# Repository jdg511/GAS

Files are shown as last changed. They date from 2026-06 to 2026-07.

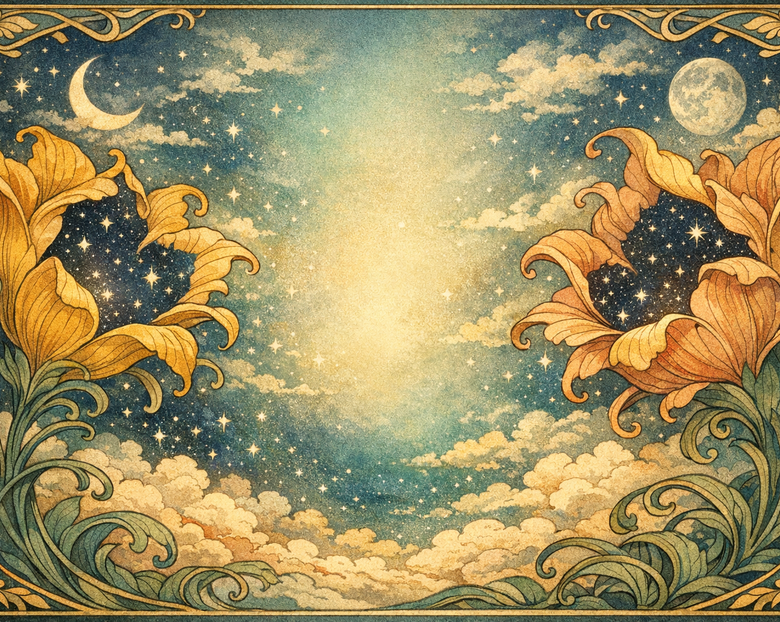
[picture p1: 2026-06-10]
Assets/Images/background_session_08.png

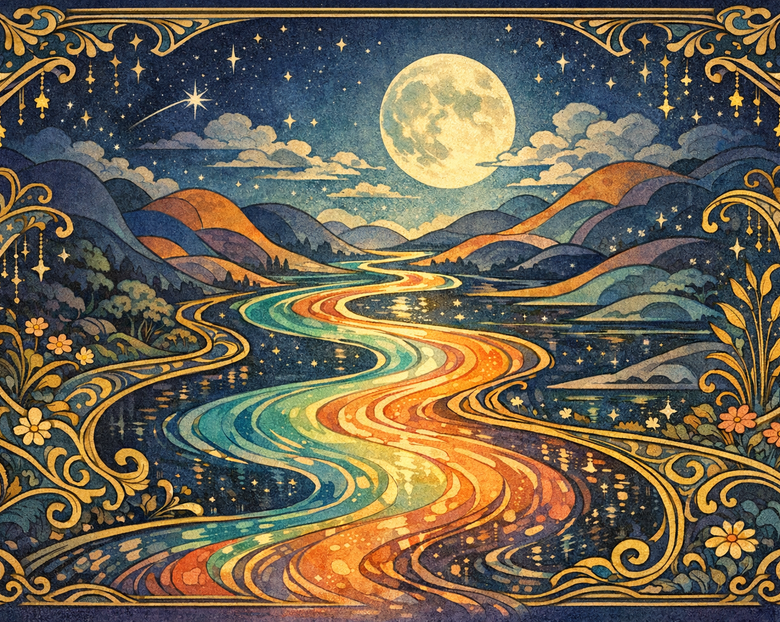
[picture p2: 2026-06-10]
Assets/Images/background_session_03.png

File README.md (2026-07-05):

# The Great American Spring

JUCE 7 audio effect by Illicit Apothecary.

Release v2.5 defines the GAS fork from the former Stereo Crossfeed Convolver project. It packages only the four final spring tank IR files:

- `GBS-L.wav`
- `GBS-R.wav`
- `GAS-L.wav`
- `GAS-R.wav`

The plugin provides Main Tanks, optional Ext Reverb Tanks in series or parallel, a constant-sum stereo crossfade, FilterClipper, feedback phase control, mono source handling, and wet/dry output mixing.

## Hardware Mapping Notes

For the real device, the simulation's `predelay + convolution IR` stage should be treated as the software stand-in for a physical spring reverb tank.

- Primary tank simulation: both channels represent `4AB1C1B` tanks.
- Secondary tank simulation: left channel represents a `9EB2C1B` tank and right channel represents a `9EB3C1B` tank.

This means the current JUCE simulation is not just a generic convolution reverb. Its timing and IR choices are standing in for the mechanical behavior of the spring tanks we intend to use in hardware.
Only the predelay and convolution portions are simulation-only. They exist to emulate the behavior of the real spring tanks; the rest of the signal path should be treated as candidate hardware behavior unless we explicitly decide otherwise later.

## Hardware Platform Constraints

The real-world unit should be designed as primarily analog hardware:

- Use passive components, solid-state transistors, and analog / mixed-signal ICs as the main building blocks.
- Do not base the PCB design on an MCU, Arduino, Raspberry Pi, or other general-purpose embedded computer.
- The production hardware should replace the simulation-only predelay and convolution stages with real spring tanks and supporting analog electronics, not runtime convolution or software processing on the PCB.

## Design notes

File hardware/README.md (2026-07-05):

# GAS Hardware Build

This folder is the starting point for turning the JUCE spring-reverb simulation into a real analog product.

## Core Constraints

- The real unit is primarily analog.
- Use passive parts, transistors, and analog or mixed-signal ICs.
- Do not use an MCU, Arduino, Raspberry Pi, or other general-purpose embedded computer on the production PCB.
- The external audio interfaces should be balanced line level, nominally `+4 dBu`, with 600-ohm capable line I/O behavior.
- The external audio connectors should be combo `XLR / TRS` jacks.
- The enclosure format is now a **user-supplied cylindrical tube**, `10 in` nominal diameter (standard pipe/cap size; `9 in` fits but is rarely stocked) and about `48 in` long.
- All external audio connections and DC power entry should land on **one circular service endcap**, in the spirit of the original Great British Spring.
- In the audio path, avoid ceramic, tantalum, and electrolytic capacitors wherever practical; prefer film-based or other non-ceramic/non-electrolytic solutions and use direct coupling where it makes sense. Power-supply and rail-decoupling positions may use ceramics or electrolytics when practical.
- Only the simulation's predelay and convolution blocks are software-only stand-ins for the real spring tanks.
- The real hardware should use the target tanks directly:
  - Primary tanks: `4AB1C1B` left and `4AB1C1B` right
  - Secondary tanks: `9EB2C1B` left and `9EB3C1B` right
- Plan around `+15VA / -15VA`, but prefer parts that can tolerate at least `+18V / -18V` wherever practical.
- Mains conversion lives in an **external `+24 VDC` wall-adapter strategy** (`750 mA / 18 W`, Triad Magnetics `WSU240-0750` regulated SMPS from DigiKey, selected `2026-07-04`). The chassis takes DC at a barrel jack and generates `+15V / -15V / +5V` on-board from that single DC input. No mains-side circuitry inside the enclosure. The Triad unit is a regulated SMPS; the P-0 receiving check in [rev-a-external-dc-power.md](rev-a-external-dc-power.md) still applies at first power-up.

## Board Roadmap

We are partitioning the product into analog boards so each section can be designed, tested, and revised independently.

1. Input / Output board
   - Balanced line receiver, dry split, final wet/dry summing, balanced line driver
2. Ext Reverb Tanks Off / Series / Parallel board
   - Secondary tank routing and amount control
3. Filter and Clipping board
   - Drive, HPF, selectable clipping, LPF
4. Tank Driver / Recovery board
   - Real spring tank send and return electronics for primary and secondary tanks
5. Crossfade / Feedback / Mixer board
   - Stereo tank crossfade, feedback loop, phase invert, inter-board summing
6. Power / Control / Interconnect board
   - Analog supply rails, panel controls, board-to-board headers, grounding strategy

## Signal-Path Mapping

The current software path is:

`input -> dry tap + wet path -> tank model -> stereo crossfade -> filter/clipper -> feedback -> wet/dry mix -> output`

The real hardware path should become:

`balanced line receiver -> dry split + wet send -> real tank drive/recovery path -> stereo crossfade -> filter/clipper -> feedback loop -> wet/dry output mixer -> balanced line driver`

The only direct substitution is:

- `predelay + convolution` in software
- replaced by
- real tank drive + real spring tank + recovery stages in hardware

## Design Intent

- Keep the board architecture modular so a third-party PCB house can fabricate repeatable revisions.
- Favor through-hole panel hardware and serviceable connectors where practical.
- Keep the control surface directly analog whenever possible: pots, toggles, rotary switches, relay logic, and analog switch ICs are all acceptable paths.
- Avoid any hardware decision that depends on firmware existing later.

## Build Handoff Entry Points

If you are picking this package up to actually build a unit, start here:

- [rev-a-external-dc-power.md](rev-a-external-dc-power.md) — external wall-adapter power topology and on-board ±15V / +5V generation
- [rev-a-pipe-enclosure-concept.md](rev-a-pipe-enclosure-concept.md) — cylindrical shell, endcap, rail, and tank-mount concept
- [rev-a-endcap-panel-layout.md](rev-a-endcap-panel-layout.md) — service-endcap zoning for combo jacks, DC jack, and controls
- [rev-a-endcap-hole-table.md](rev-a-endcap-hole-table.md) — first drilling/cutout draft for the circular service endcap
- [rev-a-endcap-hole-table.csv](rev-a-endcap-hole-table.csv) — machine-readable companion to the endcap hole table
- [rev-a-board-outline-assumptions.md](rev-a-board-outline-assumptions.md) — target board envelopes and axial placement inside the tube
- [rev-a-board-outline-assumptions.csv](rev-a-board-outline-assumptions.csv) — machine-readable board envelope and station map
- [rev-a-harness-cut-lengths.md](rev-a-harness-cut-lengths.md) — prototype harness cut lengths for boards, tanks, and panel wiring
- [rev-a-harness-cut-lengths.csv](rev-a-harness-cut-lengths.csv) — machine-readable harness-length companion
- [rev-a-board-package-freeze.md](rev-a-board-package-freeze.md) — compact board-by-board freeze for schematic capture and quoting
- [rev-a-electrical-capture-worksheet.md](rev-a-electrical-capture-worksheet.md) — next-pass electrical wiring brief keyed to the actual KiCad refs
- [rev-a-io-schematic-ready-definition.md](rev-a-io-schematic-ready-definition.md) — exact first-pass I/O unit allocation, passive map, and connector/net ownership
- [rev-a-ext-routing-schematic-ready-definition.md](rev-a-ext-routing-schematic-ready-definition.md) — exact first-pass ext-routing relay ownership, control decode, and passive map
- [rev-a-tank-driver-recovery-schematic-ready-definition.md](rev-a-tank-driver-recovery-schematic-ready-definition.md) — exact first-pass tank send/recovery stage ownership, shield strategy, and passive map
- [rev-a-crossfade-feedback-wet-schematic-ready-definition.md](rev-a-crossfade-feedback-wet-schematic-ready-definition.md) — exact first-pass crossfade, wet-return, and feedback-path definition
- [rev-a-filter-clipper-schematic-ready-definition.md](rev-a-filter-clipper-schematic-ready-definition.md) — exact first-pass filter/drive/clip stage ownership and mode truth
- [rev-a-control-backplane-schematic-ready-definition.md](rev-a-control-backplane-schematic-ready-definition.md) — exact first-pass control landing, mode encoding, and backplane reserve policy
- [rev-a-board-connector-schedule.csv](rev-a-board-connector-schedule.csv) — machine-readable connector ownership and harness schedule
- [rev-a-quote-request-packet.md](rev-a-quote-request-packet.md) — exactly which files to send each vendor and template request emails
- [rev-a-total-cost-rollup.md](rev-a-total-cost-rollup.md) — single per-unit cost estimate across electronics, fab, assembly, tanks, enclosure, and labor
- [rev-a-bench-test-procedures.md](rev-a-bench-test-procedures.md) — per-board test procedures with specific signals, equipment, and pass/fail thresholds
- [rev-a-manufacturing.md](rev-a-manufacturing.md) — vendor recommendations and file conventions
- [bom/rev-a-procurement-snapshot.md](bom/rev-a-procurement-snapshot.md) — current exact-part sourcing snapshot and scope split
- [rev-a-bringup-sequence.md](rev-a-bringup-sequence.md) — board-by-board power-up order
- [rev-a-open-issues.md](rev-a-open-issues.md) — what is still genuinely unresolved

## Next Deliverables

- Shared signal naming and connector conventions
- One spec per board
- Schematic packets with stage ownership and pin-level harness maps
- Control-law and circuit-value tables that track the current plugin behavior
- Remaining audio-sheet pin-level

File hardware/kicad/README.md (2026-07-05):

# KiCad Workspace

KiCad 10 is installed locally on this machine.

This folder is the intended home for the hardware project once schematic capture starts.

## Planned Contents

- `GAS-Hardware.kicad_pro`
- `GAS-Hardware.kicad_sch`
- one schematic file scaffold per board
- board layouts for:
  - input-output
  - tank-driver-recovery
  - ext-tank-routing
  - crossfade-feedback-wet-summing
  - filter-clipper

## Current Status

The KiCad project now has a **real top-level hierarchical shell**, first-pass real symbol capture across every rev-A child sheet, and a first-pass electrically assigned power/backplane page.

What currently exists:

- file naming
- top-level sheet ownership and page ordering
- title blocks
- top-level system notes
- child-sheet interface labels for global rails, I/O boundary nets, inter-board audio nets, and frozen control nets
- first-pass symbol population on every rev-A board sheet
- first-pass DC-entry, rail-generation, and harness-fanout net assignment on `power-backplane.kicad_sch`
- PCB placement scaffold files for all six rev-A boards, generated from the documented board envelope assumptions
- DRC-clean placement scaffolds with four M3 mounting holes plus all currently assigned schematic footprints per board
- capture sequencing
- validated CLI export workflow
- a manifest-driven audit script for measuring schematic population progress

What does **not** yet exist:

- real inter-sheet and intra-sheet pin-level wiring on the five audio/control sheets
- clean ERC after the new symbol-only capture phase
- finished footprint assignment inside every schematic page
- routed copper, zones, final component placement, or Gerber/drill fabrication exports for the PCB files

Capture should now key off:

- [rev-a-schematic-packets.md](C:/Users/Jason/GAS-build/repo/hardware/rev-a-schematic-packets.md:1)
- [rev-a-electrical-capture-worksheet.md](C:/Users/Jason/GAS-build/repo/hardware/rev-a-electrical-capture-worksheet.md:1)
- [rev-a-io-schematic-ready-definition.md](C:/Users/Jason/GAS-build/repo/hardware/rev-a-io-schematic-ready-definition.md:1)
- [rev-a-ext-routing-schematic-ready-definition.md](C:/Users/Jason/GAS-build/repo/hardware/rev-a-ext-routing-schematic-ready-definition.md:1)
- [rev-a-tank-driver-recovery-schematic-ready-definition.md](C:/Users/Jason/GAS-build/repo/hardware/rev-a-tank-driver-recovery-schematic-ready-definition.md:1)
- [rev-a-crossfade-feedback-wet-schematic-ready-definition.md](C:/Users/Jason/GAS-build/repo/hardware/rev-a-crossfade-feedback-wet-schematic-ready-definition.md:1)
- [rev-a-filter-clipper-schematic-ready-definition.md](C:/Users/Jason/GAS-build/repo/hardware/rev-a-filter-clipper-schematic-ready-definition.md:1)
- [rev-a-control-backplane-schematic-ready-definition.md](C:/Users/Jason/GAS-build/repo/hardware/rev-a-control-backplane-schematic-ready-definition.md:1)
- [rev-a-interconnect-pin-map.md](C:/Users/Jason/GAS-build/repo/hardware/rev-a-interconnect-pin-map.md:1)
- [rev-a-bringup-sequence.md](C:/Users/Jason/GAS-build/repo/hardware/rev-a-bringup-sequence.md:1)
- [rev-a-sheet-population-plan.md](C:/Users/Jason/GAS-build/repo/hardware/kicad/rev-a-sheet-population-plan.md:1)
- [rev-a-symbol-manifest.csv](C:/Users/Jason/GAS-build/repo/hardware/kicad/rev-a-symbol-manifest.csv:1)
- [rev-a-net-label-manifest.csv](C:/Users/Jason/GAS-build/repo/hardware/kicad/rev-a-net-label-manifest.csv:1)

## Verification

During this session, the hierarchical top-level shell and all child sheets were accepted by `kicad-cli`, and the release-export script still produced schematic PDFs successfully after the interface-label pass.

Important current nuance:

- symbol population is intentionally ahead of real wire placement
- `kicad-cli sch export pdf` still succeeds
- top-level ERC is no longer clean at this intermediate stage because the hierarchical labels are not yet attached to real wires or symbols
- the current ERC result is therefore a **known intermediate failure**, not a claim that the capture is electrically complete

Current exported folder:

- the historical placeholder export artifact still exists as a file named `hardware/kicad/exports`

Repeatable release/export helper:

- [export-rev-a-release.ps1](C:/Users/Jason/GAS-build/repo/hardware/kicad/export-rev-a-release.ps1:1)
- [rev-a-release-manifest.csv](C:/Users/Jason/GAS-build/repo/hardware/kicad/rev-a-release-manifest.csv:1)

Repeatable capture-progress audit:

- [audit-rev-a-capture.py](C:/Users/Jason/GAS-build/repo/hardware/kicad/audit-rev-a-capture.py:1)
- [rev-a-capture-audit.md](C:/Users/Jason/GAS-build/repo/hardware/kicad/rev-a-capture-audit.md:1)

Run:

```powershell
python hardware/kicad/audit-rev-a-capture.py
```

Current baseline from the latest `2026-06-29` audit:

- top-level hierarchy: `6 / 6` child sheets present
- populated schematic refs: `88 / 88`
- explicit manifest net labels: `82 / 82`

Current release-export / ERC baseline from the same session:

- capture audit: `88 / 88` planned refs present and `82 / 82` manifest labels present
- top-level ERC: `650` known intermediate violations after the I/O-board center-short cleanup pass on `2026-06-29`
- the I/O child sheet dropped from `404` to `376` local violations in the same pass, and its multiple-net-name collisions dropped from `8` to `2`
- the remaining I/O multiple-net-name warnings are the intentional `WD_L_LO <-> WET_SUM_L` and `WD_R_LO <-> WET_SUM_R` wet-return aliases
- the remaining ERC debt is still dominated by top-level unconnected sheet pins, placeholder wire endpoints, off-grid legacy symbol endpoints, and still-unwired child-sheet labels on the non-power sheets
- the power/backplane page itself still stands as the most electrically assigned sheet, but it is not yet the final ripple-decoupling or chassis-bond implementation

Current PCB scaffold baseline:

- `crossfade-feedback-wet.kicad_pcb`: `100 mm x 70 mm`, 8 electrical footprints, 4x M3 mounting holes, DRC clean
- `ext-tank-routing.kicad_pcb`: `120 mm x 80 mm`, 12 electrical footprints, 4x M3 mounting holes, DRC clean
- `filter-clipper.kicad_pcb`: `140 mm x 90 mm`, 19 electrical footprints, 4x M3 mounting holes, DRC clean
- `io-board.kicad_pcb`: `160 mm x 75 mm`, 50 electrical footprints, 4x M3 mounting holes, DRC clean
- `power-backplane.kicad_pcb`: `150 mm x 95 mm`, 14 electrical footprints, 4x M3 mounting holes, DRC clean
- `tank-driver-recovery.kicad_pcb`: `170 mm x 110 mm`, 11 electrical footprints, 4x M3 mounting holes, DRC clean
- these are **placement scaffolds only** and are not routed fabrication outputs

Repeatable PCB footprint placement helper:

- [place-rev-a-board-footprints.py](C:/Users/Jason/GAS-build/repo/hardware/kicad/place-rev-a-board-footprints.py:1)

Current scripted output root:

- `hardware/kicad/release-exports/rev-a-release`

## Order Readiness Gate

Before ordering boards, run:

```powershell
.\hardware\kicad\test-rev-a-order-readiness.ps1
```

The gate writes:

- [rev-a-order-readiness.md](C:/Users/Jason/GAS-build/repo/hardware/kicad/rev-a-order-readiness.md:1)
- [GAS-Hardware-erc-current.json](C:/Users/Jason/GAS-build/repo/hardware/kicad/GAS-Hardware-erc-current.json:1)

It intentionally fails while any of these are true:

- no `*.kicad_pcb` board layout files exist
- top-level ERC has violations
- non-virtual schematic symbols have empty footprint fields
- KiCad/SPICE simulation model properties are absent

The current project is therefore **not order-ready**. It remains in schematic-capture cleanup before PCB layout, DRC, Gerber/drill export, and simulation setup.

## Planned Export Set

- fabrication Gerbers
- drill files
- schematic PDFs
- `BOM.csv`
- centroid / position files
- assembly drawings
- bring-up and calibration notes

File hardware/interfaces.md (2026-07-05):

# Shared Interfaces

These are the working inter-board signal names for the analog build. The goal is to keep board boundaries stable before schematic capture.

## Audio Nets

- `IN_L`, `IN_R`
  - Local single-ended audio after the balanced input receiver
- `DRY_L`, `DRY_R`
  - Dry split taken from the input board before spring-tank processing
- `WET_SEND_L`, `WET_SEND_R`
  - Main wet-path feeds leaving the input board toward the tank system
- `PRI_RET_L`, `PRI_RET_R`
  - Recovered audio returning from the primary `4AB1C1B` tanks
- `SEC_RET_L`, `SEC_RET_R`
  - Recovered audio returning from the secondary `9EB2C1B` / `9EB3C1B` tanks
- `TANK_MIX_L`, `TANK_MIX_R`
  - Output of the tank-routing board before stereo crossfade
- `XFADE_OUT_L`, `XFADE_OUT_R`
  - Output of the stereo crossfade stage
- `FILTCLIP_OUT_L`, `FILTCLIP_OUT_R`
  - Output of the filter and clipping board
- `FB_SEND_L`, `FB_SEND_R`
  - Signals entering the feedback loop
- `FB_RET_L`, `FB_RET_R`
  - Feedback return signals summed into the wet send on the ext-routing board, upstream of the primary send and the parallel-mode pickoff, so regenerated signal makes another pass through the spring tanks
  - Must never sum into the `TANK_MIX` (post-tank) summers
- `WET_SUM_L`, `WET_SUM_R`
  - Final wet signal presented to the output mix stage
- `OUT_L`, `OUT_R`
  - Local single-ended audio before the balanced output driver

## Control Nets

- `CTL_EXT_MODE_A`, `CTL_EXT_MODE_B`
  - Two-bit ext-routing control pair
  - first-pass decode is `00 = Off`, `10 = Series`, `11 = Parallel`, `01 = reserved`
- `CTL_CLIP_MODE_A`, `CTL_CLIP_MODE_B`
  - Selects Clean / Silicon / LED / Germanium clipping topology
- `CTL_FB_INV`
  - Feedback polarity invert

Practical note:

- rev A now prefers raw passive control nets at the board boundaries rather than abstract one-net control names for stereo pots
- the actual raw control naming lives in [rev-a-control-harnesses.md](C:/Users/Jason/GAS-build/repo/hardware/rev-a-control-harnesses.md:1) and [rev-a-control-backplane-definition.md](C:/Users/Jason/GAS-build/repo/hardware/rev-a-control-backplane-definition.md:1)

## Power Nets

- `+15VA`, `-15VA`
  - Preferred starting assumption for the main analog rails
- `+5VAUX`
  - Optional auxiliary rail for relay coils, LEDs, or analog-switch housekeeping
- `AGND`
  - Audio ground / star ground reference
- `CHASSIS`
  - Chassis / enclosure ground, bonded at controlled points only

## Current Assumptions

- Default design target is stereo throughout.
- External I/O uses combo `XLR / TRS` jacks.
- Main analog stages should preserve enough headroom to survive tank recovery peaks and clipping-mode level changes.
- Board-to-board links should use locking headers or JST/Molex style connectors rather than hardwired point-to-point only.
- If tank interface impedances force shielded cabling, the tank driver/recovery board owns that connectorization.

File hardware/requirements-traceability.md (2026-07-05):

# GAS Hardware Requirements Traceability

This file maps the user-provided hardware constraints to the current hardware package so the design can be reviewed for drift.

## Scope

The goal is to design the analog hardware package for the GAS device as far as possible in this session, including:

- board architecture
- schematic-ready board definitions
- sourced BOM with current pricing/vendor links
- manufacturing handoff recommendations

## Constraint Matrix

| Requirement | Current Decision | Primary Evidence |
| --- | --- | --- |
| Real device is analog, no MCU / Arduino / Raspberry Pi | Locked as analog-only architecture | [README.md](C:/Users/Jason/GAS-build/repo/hardware/README.md:7), [rev-a-system-architecture.md](C:/Users/Jason/GAS-build/repo/hardware/rev-a-system-architecture.md:9) |
| Predelay + convolution are simulation-only stand-ins for real tanks | Locked as the only software-only substitution | [README.md](C:/Users/Jason/GAS-build/repo/README.md:16), [hardware/README.md](C:/Users/Jason/GAS-build/repo/hardware/README.md:37) |
| Primary tanks are `4AB1C1B` / `4AB1C1B` | Locked in architecture and board briefs | [README.md](C:/Users/Jason/GAS-build/repo/README.md:18), [rev-a-system-architecture.md](C:/Users/Jason/GAS-build/repo/hardware/rev-a-system-architecture.md:20) |
| Secondary tanks are `9EB2C1B` left and `9EB3C1B` right | Locked in architecture and board briefs | [README.md](C:/Users/Jason/GAS-build/repo/README.md:19), [rev-a-system-architecture.md](C:/Users/Jason/GAS-build/repo/hardware/rev-a-system-architecture.md:22) |
| External I/O is balanced line level | Locked at `+4 dBu`, 600-ohm capable | [hardware/README.md](C:/Users/Jason/GAS-build/repo/hardware/README.md:10), [input-output-board.md](C:/Users/Jason/GAS-build/repo/hardware/boards/input-output-board.md:5) |
| External jacks are combo `XLR / TRS` | Locked in architecture, panel spec, and mechanical BOM | [hardware/README.md](C:/Users/Jason/GAS-build/repo/hardware/README.md:11), [rev-a-controls-and-panel.md](C:/Users/Jason/GAS-build/repo/hardware/rev-a-controls-and-panel.md:5), [rev-a-panel-and-mechanical-reference-bom.csv](C:/Users/Jason/GAS-build/repo/hardware/bom/rev-a-panel-and-mechanical-reference-bom.csv:1) |
| Rev A needs a dedicated mono-input to stereo switch | Locked on the I/O board and panel spec | [input-output-board.md](C:/Users/Jason/GAS-build/repo/hardware/boards/input-output-board.md:10), [rev-a-controls-and-panel.md](C:/Users/Jason/GAS-build/repo/hardware/rev-a-controls-and-panel.md:24) |
| Input buffer should be JFET or BiFET | Current rev-A pick is `OPA1644AIDR` | [input-output-board.md](C:/Users/Jason/GAS-build/repo/hardware/boards/input-output-board.md:29), [rev-a-system-architecture.md](C:/Users/Jason/GAS-build/repo/hardware/rev-a-system-architecture.md:41), [rev-a-core-priced-bom.csv](C:/Users/Jason/GAS-build/repo/hardware/bom/rev-a-core-priced-bom.csv:1) |
| Prefer `+/-18V` tolerant parts where practical | Locked for the audio op-amp families | [hardware/README.md](C:/Users/Jason/GAS-build/repo/hardware/README.md:17), [rev-a-system-architecture.md](C:/Users/Jason/GAS-build/repo/hardware/rev-a-system-architecture.md:53) |
| Avoid ceramic / tantalum / electrolytic capacitors in the audio path if possible | Locked as an audio-path-only capacitor policy | [hardware/README.md](C:/Users/Jason/GAS-build/repo/hardware/README.md:12), [rev-a-capacitor-policy.md](C:/Users/Jason/GAS-build/repo/hardware/rev-a-capacitor-policy.md:1), [rev-a-common-passives-reference-bom.csv](C:/Users/Jason/GAS-build/repo/hardware/bom/rev-a-common-passives-reference-bom.csv:1) |
| Power may use practical ceramics/electrolytics | Explicitly allowed in power policy and passive BOM | [rev-a-layout-rules.md](C:/Users/Jason/GAS-build/repo/hardware/rev-a-layout-rules.md:17), [rev-a-common-passives-reference-bom.csv](C:/Users/Jason/GAS-build/repo/hardware/bom/rev-a-common-passives-reference-bom.csv:5) |
| Tanks are purchased separately from the PCB assembly | Locked in manufacturing handoff | [rev-a-manufacturing.md](C:/Users/Jason/GAS-build/repo/hardware/rev-a-manufacturing.md:127), [rev-a-manufacturing.md](C:/Users/Jason/GAS-build/repo/hardware/rev-a-manufacturing.md:155) |

## Deliverable Matrix

| Deliverable | Current Evidence |
| --- | --- |
| Board architecture | [hardware/README.md](C:/Users/Jason/GAS-build/repo/hardware/README.md:19), [rev-a-system-architecture.md](C:/Users/Jason/GAS-build/repo/hardware/rev-a-system-architecture.md:57) |
| Board-by-board definitions | [boards/input-output-board.md](C:/Users/Jason/GAS-build/repo/hardware/boards/input-output-board.md:1), [boards/ext-tank-routing-board.md](C:/Users/Jason/GAS-build/repo/hardware/boards/ext-tank-routing-board.md:1), [boards/crossfade-feedback-wet-board.md](C:/Users/Jason/GAS-build/repo/hardware/boards/crossfade-feedback-wet-board.md:1), [boards/filter-clipper-board.md](C:/Users/Jason/GAS-build/repo/hardware/boards/filter-clipper-board.md:1), [boards/system-remaining.md](C:/Users/Jason/GAS-build/repo/hardware/boards/system-remaining.md:1) |
| Signal ownership / interconnects | [interfaces.md](C:/Users/Jason/GAS-build/repo/hardware/interfaces.md:1), [rev-a-interconnects.md](C:/Users/Jason/GAS-build/repo/hardware/rev-a-interconnects.md:1) |
| Schematic starting points | [rev-a-circuit-starting-points.md](C:/Users/Jason/GAS-build/repo/hardware/rev-a-circuit-starting-points.md:1), [rev-a-board-implementation-matrix.md](C:/Users/Jason/GAS-build/repo/hardware/rev-a-board-implementation-matrix.md:1), [rev-a-schematic-packets.md](C:/Users/Jason/GAS-build/repo/hardware/rev-a-schematic-packets.md:1), [rev-a-capture-value-tables.md](C:/Users/Jason/GAS-build/repo/hardware/rev-a-capture-value-tables.md:1), [rev-a-mode-truth-tables.md](C:/Users/Jason/GAS-build/repo/hardware/rev-a-mode-truth-tables.md:1) |
| Hardware control ranges mapped from the plugin | [rev-a-control-ranges-and-laws.md](C:/Users/Jason/GAS-build/repo/hardware/rev-a-control-ranges-and-laws.md:1), [PluginProcessor.cpp](C:/Users/Jason/GAS-build/repo/Source/PluginProcessor.cpp:606) |
| Layout-facing board zoning | [rev-a-board-placement-and-zones.md](C:/Users/Jason/GAS-build/repo/hardware/rev-a-board-placement-and-zones.md:1), [rev-a-layout-rules.md](C:/Users/Jason/GAS-build/repo/hardware/rev-a-layout-rules.md:1) |
| Numeric electrical targets | [rev-a-numeric-targets.md](C:/Users/Jason/GAS-build/repo/hardware/rev-a-numeric-targets.md:1), [rev-a-power-budget.md](C:/Users/Jason/GAS-build/repo/hardware/rev-a-power-budget.md:1) |
| Current priced BOMs | [bom/README.md](C:/Users/Jason/GAS-build/repo/hardware/bom/README.md:1), [bom/rev-a-core-priced-bom.csv](C:/Users/Jason/GAS-build/repo/hardware/bom/rev-a-core-priced-bom.csv:1), [bom/rev-a-common-passives-reference-bom.csv](C:/Users/Jason/GAS-build/repo/hardware/bom/rev-a-common-passives-reference-bom.csv:1), [bom/rev-a-connectors-and-harness-reference-bom.csv](C:/Users/Jason/GAS-build/repo/hardware/bom/rev-a-connectors-and-harness-reference-bom.csv:1), [bom/rev-a-panel-and-mechanical-reference-bom.csv](C:/Users/Jason/GAS-build/repo/hardware/bom/rev-a-panel-and-mechanical-reference-bom.csv:1), [bom/rev-a-supply-watch.md](C:/Users/Jason/GAS-build/repo/hardware/bom/rev-a-supply-watch.md:1) |
| Manufacturing handoff | [rev-a-manufacturing.md](C:/Users/Jason/GAS-build/repo/hardware/rev-a-manufacturing.md:1), [rev-a-validation-checklist.md](C:/Users/Jason/GAS-build/repo/hardware/rev-a-validation-checklist.md:1), [kicad/README.md](C:/Users/Jason/GAS-build/repo/hardware/kicad/README.md:1) |
| Real KiCad project scaffolding | [kicad/GAS-Hardware.kicad_pro](C:/Users/Jason/GAS-build/repo/hardware/kicad/GAS-Hardware.kicad_pro:1), [kicad/GAS-Hardware.kicad_sch](C:/Users/Jason/GAS-build/repo/hardware/kicad/GAS-Hardware.kicad_sch:1), [rev-a-schematic-capture-plan.md](C:/Users/Jason/GAS-build/repo/hardware/rev-a-schematic-capture-plan.md:1) |
| Verified schematic placeholders | [kicad/README.md](C:/Users/Jason/GAS-build/repo/hardware/kicad/README.md:1), `kicad-cli sch export pdf` run outputs in `hardware/kicad/exports` |

## Remaining Reality Check

What is strong right now:

- the architecture and constraints are explicit
- the BOM package is split in a builder-friendly way
- the board boundaries and control ownership are defined

What is not yet complete enough to call "finished hardware design":

- the KiCad project is real and hierarchical, but several audio/control sheets are still intermediate first-pass captures rather than fully finished schematics
- there are not yet finished PCB layouts or clean fabrication-ready DRC/ERC artifacts
- some stage-level component values still need bench-tuning rather than pretending to be final

That means the package is materially advanced, but the thread goal is not yet proven complete.

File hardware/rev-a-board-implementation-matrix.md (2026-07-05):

# GAS Rev A Board Implementation Matrix

This file turns the architecture into concrete board ownership so schematic capture does not drift.

## Board Summary

| Board | Main Function | Active Parts | Key Controls | Main Risk |
| --- | --- | --- | --- | --- |
| Input / Output | Balanced receive, mono-to-stereo, wet/dry sum, balanced drive | `1x OPA1644AIDR`, `3x OPA1656IDR` | Wet/Dry, Mono->Stereo | balanced I/O behavior and headroom |
| Tank Driver / Recovery | Tank send drive and tank recovery | `4x OPA1656IDR`, `2x BD139-16`, `2x BD140-16` | none on panel directly | primary send level and recovery noise |
| Ext Tank Routing | Off/Series/Parallel routing and secondary mix | `4x G6K-2F-Y-DC5`, `1x OPA1679IDR` | Ext Mode, Ext Mix | relay routing around sensitive recovery nodes |
| Crossfade / Feedback / Wet Summing | Stereo crossfade, feedback, wet handoff | `1x OPA1679IDR` | Crossfade, Feedback, Feedback Invert | loop stability |
| Filter / Clipping | HPF, drive, clipping, LPF | `2x OPA1679IDR` | Drive, HPF F/Q, LPF F/Q, Clip Mode | stereo tracking and clip switching artifacts |
| Power / Backplane | DC entry, rail conversion, star ground, harnessing | `1x URA2415YMD-10WR3`, `1x R-78E5.0-0.5` | none | ripple control and grounding |

## Input / Output Board Allocation

### U1 `OPA1644AIDR`

- balanced input receiver left
- balanced input receiver right
- mono-to-stereo routing buffer left
- mono-to-stereo routing buffer right or spare unity-gain utility stage

### U2 `OPA1656IDR`

- wet/dry mix left
- wet/dry mix right

### U3 `OPA1656IDR`

- balanced output driver left hot
- balanced output driver left cold

### U4 `OPA1656IDR`

- balanced output driver right hot
- balanced output driver right cold

### I/O Board Connectors

- `J1` left combo `XLR / TRS`
- `J2` right combo `XLR / TRS`
- `J3` left combo `XLR / TRS` output
- `J4` right combo `XLR / TRS` output
- `P1` power
- `P2` wet send
- `P3` wet return
- `P4` dry distribution
- `P5` wet/dry control
- `P6` mono-to-stereo switch

## Tank Driver / Recovery Board Allocation

### U101 `OPA1656IDR`

- primary left send predriver
- primary right send predriver

### Q101 / Q102 / Q103 / Q104 `BD139-16` / `BD140-16`

- complementary output pair for primary left send
- complementary output pair for primary right send

### U102 `OPA1656IDR`

- secondary left tank send
- secondary right tank send

### U103 `OPA1656IDR`

- primary left recovery
- primary right recovery

### U104 `OPA1656IDR`

- secondary left recovery
- secondary right recovery

### Tank Board Connectors

- `P101` primary routing bundle
- `P102` secondary routing bundle
- `P103` power
- `J101-J108` tank send/return landings

## Ext Tank Routing Board Allocation

### K201-K204 `G6K-2F-Y-DC5`

- route primary and secondary path state for Off / Series / Parallel

### U201 `OPA1679IDR`

- left final routing / wet-output sum
- right final routing / wet-output sum
- left secondary-send buffer
- right secondary-send buffer

### Routing Board Connectors

- `P201` wet input from I/O board
- `P202` primary tank bundle
- `P203` secondary tank bundle
- `P204` routed output to crossfade board
- `P205` feedback reinjection input
- `P206` control or panel-backplane header
- `P207` power input including `+5VAUX`

## Crossfade / Feedback / Wet Summing Board Allocation

### U301 `OPA1679IDR`

- `U301A` left inverting crossfade summer
- `U301B` right inverting crossfade summer
- `U301C` left feedback driver / invert stage
- `U301D` right feedback driver / invert stage
- `U301` power unit for local `+15VA / -15VA` decoupling ownership

### Crossfade / Feedback / Wet Connectors

- `P301` routed tank input: `TANK_MIX_L`, `AGND`, `TANK_MIX_R`
- `P302` send to filter / clipper: `XFADE_OUT_L`, `AGND`, `XFADE_OUT_R`
- `P303` filter return: `FILTCLIP_OUT_L`, `AGND`, `FILTCLIP_OUT_R`
- `P304` direct wet return to I/O board: `WET_SUM_L`, `AGND`, `WET_SUM_R`
- `P305` feedback reinjection output: `FB_RET_L`, `AGND`, `FB_RET_R`
- `P306` power input: `+15VA`, `AGND`, `-15VA`
- `P307` grouped control landing for crossfade, feedback amount, and feedback phase invert

### Crossfade / Feedback / Wet Circuit Freeze Notes

- the direct wet return is sourced from the post-filter `FILTCLIP_OUT_L/R` path and is not phase-flipped
- `CTL_FB_INV` only changes the feedback-send source between direct and inverted paths
- the current `P307` header is good enough for rev-A capture, but still slightly compressed for a completely raw off-board passive feedback-pot implementation

## Filter / Clipping Board Allocation

### U401 `OPA1679IDR`

- left pre-HPF
- right pre-HPF
- left drive/clipping buffer
- right drive/clipping buffer

### U402 `OPA1679IDR`

- left post-LPF
- right post-LPF
- left output buffer
- right output buffer

### Filter / Clipping Connectors

- `P401` input from crossfade board
- `P402` output to crossfade/feedback board
- `P403` control group A
- `P404` power input
- `P405` control group B

## One Important Connector Caveat

Standard combo `XLR / TRS` receptacles are typically `XLR female + TRS`.

That is conventional for balanced inputs, but unconventional for XLR outputs.

Rev A therefore has two practical interpretations:

1. honor the combo-jack requirement literally and accept the unusual female-XLR output convention
2. use the combo format where physically possible, but treat the TRS side as the primary balanced output path

The project currently preserves the literal combo-jack requirement, but this should be sanity-checked before enclosure metalwork is frozen.

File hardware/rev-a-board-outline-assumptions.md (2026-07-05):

# GAS Rev A Board Outline Assumptions

This file gives the first concrete board-size and placement assumptions for the cylindrical rev-A build.

These are **prototype-planning numbers**, not final fab outlines. Their purpose is to:

- keep the six-board split physically plausible inside the tube
- support rail spacing and harness-length planning
- give KiCad layout work a target envelope before the mechanical package is fully frozen

## Mechanical Reference Frame

- enclosure shell: user-supplied tube
- preferred outer diameter: `10.0 in` nominal (`254 mm`; measured cap face will differ — see rev-a-pipe-enclosure-concept.md)
- acceptable fallback outer diameter: `9.0 in` (`228.6 mm`) if stock appears; `8.0 in` (`203.2 mm`) only with layout compromises
- design target length: `48 in` (`1219 mm`)

For the draft board envelopes below, assume:

- usable internal width between rails and curvature keepout: about `160 mm`
- usable straight-line board length near the service end: `80-170 mm` depending on board
- minimum side clearance from board corners to curved shell: `10 mm`
- minimum board-to-board axial service gap: `18 mm`

## Preferred Internal Rail Geometry

- two longitudinal rails or angle brackets
- nominal rail separation: `140 mm` center-to-center
- board mounting plane offset from shell wall: `18-25 mm`
- keep the deepest components on the inward-facing side where possible

## Draft Board Envelopes

### 1. Input / Output Board

- target outline: `160 mm x 75 mm`
- orientation: wide edge parallel to the service endcap
- location: immediately behind the combo-jack field

Reason:

- the board mainly needs room for balanced I/O stages, harness headers, and optional short panel harnesses
- combo jacks themselves should remain panel parts, not board-edge mechanical anchors, in the preferred rev-A interpretation

### 2. Power / Control Backplane

- target outline: `150 mm x 95 mm`
- orientation: broad side parallel to the service endcap
- location: behind or slightly below the I/O board, close to DC entry and chassis bond

Reason:

- this board wants room for the DC-DC module, rail filtering, power headers, and grouped control landings

### 3. Ext Tank Routing Board

- target outline: `120 mm x 80 mm`
- location: first mid-tube audio board after the service-end boards

Reason:

- relay routing is more important than density
- keep one long edge available for the harness field

### 4. Crossfade / Feedback / Wet Board

- target outline: `100 mm x 70 mm`
- location: adjacent to the routing board

Reason:

- this is electrically compact and should be one of the smaller boards

### 5. Filter / Clipper Board

- target outline: `140 mm x 90 mm`
- location: adjacent to the crossfade board

Reason:

- this board is likely to grow because of film-capacitor footprints and control-header density

### 6. Tank Driver / Recovery Board

- target outline: `170 mm x 110 mm`
- location: deeper into the tube, near the tank zone

Reason:

- this board carries the most analog risk
- it needs room for TO-126 devices, recovery spacing, RCA or equivalent tank landings, and thermal/mechanical breathing room

## Draft Axial Station Map

Measured from the inside face of the service endcap:

| Station | Start | End | Notes |
|---|---:|---:|---|
| I/O board zone | `25 mm` | `100 mm` | close to combo-jack harnesses |
| Power/control zone | `105 mm` | `200 mm` | close to DC entry and chassis bond |
| Ext-routing zone | `225 mm` | `305 mm` | first mid-path audio board |
| Crossfade zone | `325 mm` | `395 mm` | short audio links to routing and filter |
| Filter/clipper zone | `415 mm` | `505 mm` | keep controls reachable by one grouped harness |
| Tank driver/recovery zone | `575 mm` | `685 mm` | quiet zone near tank harness landings |
| Tank mounting zone | `720 mm` | `1120 mm` | user-supplied tanks and isolation hardware |

This intentionally leaves:

- one service gap between the filter/clipper and tank-driver board
- a quiet transition zone before the tank area

## Curvature And Height Keepouts

Do not assume a rectangular box interior.

For boards wider than `140 mm`:

- keep tall parts inside an inner rectangle about `140 mm x board length`
- reserve corner triangles as no-go zones for tall electrolytics, relays, or stacked connectors

Practical rule:

- if a component is taller than `14 mm`, keep it at least `12 mm` inboard from the board outline on the shell-facing side

## Preferred Mounting-Hole Pattern

Use a simple 4-hole pattern on each board where practical:

- hole size: `3.2 mm` for `M3` or `4-40`
- edge setback: `5-7 mm`
- slotted holes acceptable only on the tank-driver board if thermal or harness alignment needs them

## What This File Does And Does Not Freeze

This file freezes:

- a plausible physical envelope for each board
- a believable axial layout for harness planning
- a preferred rail-mounted construction style

This file does not freeze:

- exact final PCB outline
- final mounting-hole coordinates
- exact component keepouts from the eventual KiCad 3D models

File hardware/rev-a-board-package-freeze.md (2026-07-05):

# GAS Rev A Board Package Freeze

This file is the compact "what each board is" reference for the current hardware package.

Use it when:

- populating the KiCad child sheets
- building per-board quote bundles
- checking that the mechanical, harness, and BOM layers still agree

The goal is not to replace the board briefs. It is to freeze the minimum board facts that should not drift casually.

## Global Rev-A Freeze

- Analog-only product electronics. No MCU, Arduino, Raspberry Pi, DSP module, or general-purpose embedded computer.
- External I/O is balanced line level, nominal `+4 dBu`, with 600-ohm capable line-interface behavior.
- External panel connectors are combo `XLR / TRS` jacks.
- The real tank set is `4AB1C1B x2`, `9EB2C1B x1`, `9EB3C1B x1`.
- Predelay and convolution remain software-only study tools and do not appear on the PCB set.
- Main supply architecture is external `+24 VDC` wall adapter into on-board conversion for `+15VA`, `-15VA`, and `+5VAUX`.
- The main cylindrical enclosure tube is user-supplied.

## Board Freeze Table

| Board | Target Envelope | Placement Zone | Main Active Set | Power | Main Connectors | Controls | Install Scope |
|---|---|---|---|---|---|---|---|
| Input / Output | `160 x 75 mm` | `25-100 mm` from service endcap | `1x OPA1644AIDR`, `3x OPA1656IDR` | `+15VA`, `AGND`, `-15VA` | `J1-J4`, `P1-P6` | wet/dry, mono-to-stereo | SMT core plus panel-handwired combo jacks |
| Power / Control Backplane | `150 x 95 mm` | `105-200 mm` | `1x URA2415YMD-10WR3`, `1x R-78E5.0-0.5`, optional `ULN2003ADR` | `+24VDC` input, generates `+15VA`, `-15VA`, `+5VAUX` | `J500`, `P501-P506`, optional `P601`, `P610-P614` | none directly; preferred control landing | mixed-tech or SMT plus handwired panel DC jack |
| Ext Tank Routing | `120 x 80 mm` | `225-305 mm` | `4x G6K-2F-Y-DC5`, `1x OPA1679IDR` | `+15VA`, `AGND`, `-15VA`, `+5VAUX` | `P201-P207` | ext mode, ext amount | SMT board, controls via backplane or local wiring |
| Crossfade / Feedback / Wet | `100 x 70 mm` | `325-395 mm` | `1x OPA1679IDR` | `+15VA`, `AGND`, `-15VA` | `P301-P307` | crossfade, feedback, feedback invert | SMT board, controls via backplane or local wiring |
| Filter / Clipper | `140 x 90 mm` | `415-505 mm` | `2x OPA1679IDR` | `+15VA`, `AGND`, `-15VA` | `P401-P405` | drive, HPF F/Q, LPF F/Q, clip mode | SMT board plus film-cap-heavy analog section |
| Tank Driver / Recovery | `170 x 110 mm` | `575-685 mm` | `4x OPA1656IDR`, `2x BD139-16`, `2x BD140-16` | `+15VA`, `AGND`, `-15VA` | `P101-P103`, `J101-J108` | no front-panel controls | mixed-tech board with shielded tank landing |

Placement zones above come from:

- [rev-a-board-outline-assumptions.csv](C:/Users/Jason/GAS-build/repo/hardware/rev-a-board-outline-assumptions.csv:1)

## Per-Board Capture Freeze

### Input / Output

- `J1` and `J2` are balanced stereo inputs.
- `J3` and `J4` are balanced stereo outputs.
- Mono mode is a dedicated rev-A panel function and lives after the balanced receiver.
- Output stage is fully active balanced, not unbalanced and not pseudo-balanced.
- Audio-path capacitor choices should honor the non-ceramic/non-electrolytic preference where coupling is required.

### Power / Control Backplane

- No mains circuitry on-board.
- DC entry is `5.5 x 2.1 mm` barrel (PJ-005A, Triad WSU240-0750 adapter).
- One controlled `AGND` to `CHASSIS` bond only.
- This board is the preferred landing zone for dense front-panel controls if the panel is not directly board-mounted.
- `U601` remains reserve-only under the current frozen 2-bit ext-mode interface and should not be assumed populated in the fixed rev-A BOM.

### Ext Tank Routing

- Supports `Off`, `Series`, and `Parallel` for the secondary tanks only.
- Must preserve distinct left and right secondary tank identities:
  - left secondary = `9EB2C1B`
  - right secondary = `9EB3C1B`
- Relay current loops stay away from high-gain recovery nodes.

### Crossfade / Feedback / Wet

- This board owns the feedback loop gain and polarity function.
- The wet return sent back to the I/O board comes from here, not from the filter board directly.

### Filter / Clipper

- Clean mode bypasses intentional clipping rather than merely turning gain down.
- Keep mirrored left/right analog geometry as much as the film-cap footprint density allows.
- Reserve DNP footprints for alternate diode families and compensation parts.

### Tank Driver / Recovery

- This board is the real-world replacement for the software-only predelay/convolution surrogate.
- Primary sends are the highest-current analog path in the product and need thermal and loop-stability headroom.
- Recovery stages must stay physically quiet and separated from relay and DC-DC noise.

## Preferred Assembly Split

### Board-House Population

- op amps
- relays
- small passives
- low-voltage protection parts
- the DC-DC and +5V regulator modules if the selected assembler accepts them

### Hand Install Or Consigned Install

- combo `XLR / TRS` jacks
- panel DC jack
- panel pots, toggles, and rotaries
- TO-126 primary send transistors if the chosen assembler does not support them economically
- shielded tank cabling
- the four spring tanks
- the user-supplied enclosure tube

## Drift Checks

Before freezing any schematic sheet or PCB outline, confirm it still agrees with:

- [rev-a-interconnect-pin-map.md](C:/Users/Jason/GAS-build/repo/hardware/rev-a-interconnect-pin-map.md:1)
- [rev-a-control-harnesses.md](C:/Users/Jason/GAS-build/repo/hardware/rev-a-control-harnesses.md:1)
- [rev-a-endcap-panel-layout.md](C:/Users/Jason/GAS-build/repo/hardware/rev-a-endcap-panel-layout.md:1)
- [rev-a-harness-cut-lengths.csv](C:/Users/Jason/GAS-build/repo/hardware/rev-a-harness-cut-lengths.csv:1)

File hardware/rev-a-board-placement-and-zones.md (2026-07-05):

# GAS Rev A Board Placement And Zones

This file turns the abstract board split into layout-facing placement guidance.

It is intentionally more concrete than the general layout rules, but less fake-precise than claiming a final enclosure before the mechanics are frozen.

## Global Placement Rules

- Keep the power-entry and DC-DC conversion zone as far as practical from tank recovery circuitry.
- Keep every board's power entry on a predictable edge or corner so the harnessing stays legible.
- Keep low-level recovery, feedback, and balanced-input nodes away from relay coils, PSU ripple loops, and tank-send current paths.
- Prefer one consistent "quiet edge" and one consistent "connector edge" on each board instead of scattering interfaces on every side.
- Treat the cylindrical tube axis as the main mechanical reference direction.

## 1. Input / Output Board

### Role

- service-endcap-adjacent signal entry/exit board
- balanced receive and balanced drive boundary

### Preferred Zones

| Zone | Preferred Contents |
| --- | --- |
| panel edge | `J1-J4` combo jacks and any immediately adjacent RF boundary parts |
| quiet input corner | balanced receiver ratios and `U1` |
| internal signal edge | `P2`, `P3`, `P4` harness connectors |
| output edge near panel | `U3`, `U4`, and output build-out resistors |
| utility/control edge | `P5`, `P6` if controls are off-board |

### Routing Intent

- keep the input receivers and output drivers physically separated
- do not let output leg return currents share the same copper region as the input ratio network
- keep combo-jack pin-1 or sleeve-to-chassis strategy physically close to the connector boundary

## 2. Tank Driver / Recovery Board

### Role

- quietest analog board in the system except for the local send transistor hot zones

### Preferred Zones

| Zone | Preferred Contents |
| --- | --- |
| hot/send edge | `Q101-Q104`, emitter resistors, zobels, any small heatsink allowance |
| tank connector edge | `J101-J108` or their chosen equivalents |
| quiet recovery corner | `U103`, `U104`, recovery bias/gain parts |
| internal harness edge | `P101`, `P102`, `P103` |
| service/test strip | primary bias/current test pads and return-node test pads |

### Routing Intent

- keep send current loops short and local to the output devices
- keep recovery traces physically separated from send traces, even when they terminate at the same tank interface area
- if the board must sit near the tanks, orient the recovery side away from the PSU and relay boards

## 3. Ext Tank Routing Board

### Role

- mode-switching and secondary contribution management board

### Preferred Zones

| Zone | Preferred Contents |
| --- | --- |
| relay/power side | `K201-K204`, coil-drive or suppression parts, `P207` |
| wet audio side | `U201`, active summing parts |
| signal harness edge | `P201-P205` |
| control edge | `P206` or the local mode/amount hardware |

### Routing Intent

- draw the relay contact flow in a way that is visually traceable on the PCB
- keep coil supply and flyback current loops out of the high-impedance summing area
- prefer one edge for all inter-board signal harnesses so routing mode debug is simpler

## 4. Crossfade / Feedback / Wet Board

### Role

- loop-management and final wet handoff board

### Preferred Zones

| Zone | Preferred Contents |
| --- | --- |
| input edge | `P301` routed-tank input and `P303` filter return |
| loop core | `U301`, feedback summing parts, phase switch interface |
| output edge | `P302`, `P304`, `P305` |
| power/control edge | `P306`, `P307` |

### Routing Intent

- keep the feedback loop physically compact and obvious
- put the feedback reinjection output near the edge that faces the routing board
- avoid long wandering traces between the filter-return point and the wet-output point

## 5. Filter / Clipper Board

### Role

- dense tone-shaping and nonlinear board

### Preferred Zones

| Zone | Preferred Contents |
| --- | --- |
| input edge | `P401` and the first HPF stage |
| center mirror line | left/right matched filter sections |
| clip core | diode networks and drive-stage feedback loops |
| output edge | `P402` and output buffers |
| control edge | `P403` or board-mounted control hardware |
| power corner | `P404` and local decoupling |

### Routing Intent

- mirror left and right channels as much as practical
- keep each clip network close to its drive op amp
- do not place long control traces through the most sensitive summing nodes if the controls land off-board

## 6. Power / Backplane Board

### Role

- low-voltage source, star-ground, and distribution board

### Preferred Zones

| Zone | Preferred Contents |
| --- | --- |
| service-endcap side | `J500` harness landing from panel DC jack, `D500`, `F500`, `TVS500`, `C500` |
| conversion side | `PS500`, `PS501`, ferrites, rail bulk caps |
| low-voltage distribution side | `P501-P506`, rail bulk capacitors, test pads |
| bond zone | controlled `AGND` to `CHASSIS` connection |
| optional control landing side | grouped panel-control headers if this board becomes the control backplane |

### Routing Intent

- keep dirty input-conversion loops local to the DC-DC area
- place the star ground and chassis bond close to the low-voltage distribution center, not in the middle of the quiet audio harness field
- point the `P506` auxiliary-power output toward the ext-routing board if the enclosure allows it

## Board-To-Board Physical Relationship

The preferred physical ordering inside the cylindrical enclosure is:

1. service-endcap plane: combo jacks, DC jack, switches, pots
2. just behind endcap: input/output board plus power/control backplane
3. middle analog area: ext-routing, crossfade/feedback, and filter boards on rails
4. quiet deep-tube area: tank driver/recovery board near the tank harness landings
5. along tube wall or subframe: spring tanks

This ordering helps the harness set follow the signal flow while keeping the power-entry and relay energy away from the quietest tank-return circuitry.

## What This File Does Not Pretend To Freeze

- exact board outline dimensions
- exact mounting-hole pattern
- exact front-panel spacing
- exact circular endcap hole pattern
- whether every control is board-mounted or backplane-landed

Those still depend on the final enclosure and metalwork package.

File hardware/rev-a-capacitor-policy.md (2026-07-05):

# GAS Rev A Capacitor Policy

This project now has an explicit audio-path capacitor-selection preference:

- in the audio path, avoid ceramic capacitors where practical
- in the audio path, avoid tantalum capacitors
- in the audio path, avoid electrolytic capacitors where practical

## Preferred Order

1. direct coupling with correct biasing if no capacitor is needed
2. film
3. PPS-film
4. polypropylene
5. polyester
6. mica

## What This Means In Practice

- balanced I/O and internal gain stages should be direct-coupled where sensible
- filter timing positions should use film-family parts where practical
- large-value coupling caps should be treated as a warning sign to revisit the circuit topology
- power-supply filtering and rail decoupling may use ceramic or electrolytic parts where that is the practical engineering choice

## Expected Exceptions

The biggest likely exception zone is the primary `4AB1C1B` send driver if the design keeps a single-supply, capacitor-coupled approach.

If a ceramic, tantalum, or electrolytic capacitor becomes truly unavoidable in the audio path:

- document the exact reason
- document the location
- document why the non-ceramic alternative was not practical for rev A

## Design Consequences

- board area may increase
- some boards may become mixed through-hole / SMD
- the first prototype may prioritize capacitor policy over density

That tradeoff is acceptable for rev A.

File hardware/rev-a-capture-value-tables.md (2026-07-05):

# GAS Rev A Capture Value Tables

This file is the schematic-capture companion to [rev-a-schematic-packets.md](C:/Users/Jason/GAS-build/repo/hardware/rev-a-schematic-packets.md:1).

Use it to reserve designator blocks and populate the first real schematic sheets with consistent starting values.

These are not claimed-final production values. They are the first capture values that should exist on the sheet instead of leaving whole analog sections unnamed or blank.

## 1. Input / Output Board

### Recommended Designator Reservations

| Block | Recommended RefDes Block |
| --- | --- |
| balanced input boundary and RF parts | `R1-R10`, `C1-C10` |
| left/right balanced receiver ratios | `R11-R18` |
| mono/stereo routing and split isolation | `R21-R30` |
| wet/dry summing | `R31-R40` |
| balanced output left | `R41-R50`, `C41-C44` |
| balanced output right | `R51-R60`, `C51-C54` |
| local decoupling and rail bulk | `C91-C99` |

### Starting Circuit Table

| Stage | Part Group | Start Value / Part | Notes |
| --- | --- | --- | --- |
| input series protection | `R1-R4` | `100R` | one per balanced leg |
| RF shunt footprints | `C1-C4` | `220 pF`, DNP default | keep at the connector boundary |
| balanced receiver ratios | `R11-R18` | `10k`, `0.1%` | matched differential receiver ratios |
| split isolation | `R21-R24` | `100R` | one per dry/wet branch output if needed |
| wet input summing | `R31`, `R33` | `20k` | left dry and wet summing inputs |
| wet input summing | `R32`, `R34` | `20k` | right dry and wet summing inputs |
| summing feedback | `R35`, `R36` | `20k` | left/right summer feedback |
| balanced output gain set | `R41-R48` | `10k` | start with unity hot/cold stages |
| output build-out | `R49-R50`, `R59-R60` | `49.9R` | one per output leg |
| output RF footprints | `C41-C44`, `C51-C54` | DNP default | optional connector-facing suppression |

## 2. Tank Driver / Recovery Board

### Recommended Designator Reservations

| Block | Recommended RefDes Block |
| --- | --- |
| primary left send | `R101-R119`, `C101-C109`, `D101-D104` |
| primary right send | `R121-R139`, `C121-C129`, `D121-D124` |
| secondary left/right sends | `R151-R169`, `C151-C159` |
| primary recoveries | `R171-R189`, `C171-C179` |
| secondary recoveries | `R191-R209`, `C191-C199` |
| local decoupling and rail bulk | `C291-C299` |

### Starting Circuit Table

| Stage | Part Group | Start Value / Part | Notes |
| --- | --- | --- | --- |
| primary base stoppers | `R101`, `R102`, `R121`, `R122` | `47R` to `100R` | one at each transistor base |
| primary emitter resistors | `R103`, `R104`, `R123`, `R124` | `0.22R` to `0.47R` | start with footprints that allow either value |
| primary zobel resistor | `R105`, `R125` | `10R` | pair with film cap |
| primary zobel capacitor | `C101`, `C121` | `47 nF` film preferred | tank-send stabilization |
| secondary send feedback | `R151`, `R152` | `12k` | left/right non-inverting gain |
| secondary send gain-to-ground | `R153`, `R154` | `10k` | gives about `2.2x` gain |
| secondary send series output | `R155`, `R156` | `220R` | one per secondary send |
| recovery input bias | `R171-R174` | `2.2M` | one per recovery input |
| recovery gain-to-ground | `R175-R178` | `1k` | one per recovery stage |
| recovery feedback | `R179-R182` | `33k` | one per recovery stage |
| recovery feedback comp | `C171-C174` | `47 pF` to `100 pF`, DNP-friendly | stability tuning footprint |
| recovery input coupler if required | `C175-C178` | `22 nF` film preferred | only if direct coupling proves impractical |

## 3. Ext Tank Routing Board

### Recommended Designator Reservations

| Block | Recommended RefDes Block |
| --- | --- |
| left routing / summing | `R201-R219`, `C201-C209` |
| right routing / summing | `R221-R239`, `C221-C229` |
| series makeup and feedback injection | `R241-R259`, `C241-C249` |
| relay coil suppression and housekeeping | `D261-D268`, `R261-R269`, `C261-C269` |
| local decoupling and rail bulk | `C291-C299` |

### Starting Circuit Table

| Stage | Part Group | Start Value / Part | Notes |
| --- | --- | --- | --- |
| routing/summing inputs | `R201-R208`, `R221-R228` | `20k` | primary, secondary, and wet summing starts |
| routing feedback | `R209`, `R229` | `20k` | unity-gain active sums |
| series makeup trim | `R241` | `20k` nominal plus trim footprint | only if series mode needs lift |
| feedback reinjection resistor | `R242`, `R243` | `20k` | left/right feedback return entry |
| relay flyback | `D261-D264` | diode footprint or suppression network | required if coils are transistor-driven |

## 4. Crossfade / Feedback / Wet Board

### Recommended Designator Reservations

| Block | Recommended RefDes Block |
| --- | --- |
| left/right crossfade network | `R301-R319`, `C301-C309` |
| feedback loop | `R321-R339`, `C321-C329` |
| wet output handoff | `R341-R349`, `C341-C344` |
| local decoupling and rail bulk | `C391-C399` |

### Starting Circuit Table

| Stage | Part Group | Start Value / Part | Notes |
| --- | --- | --- | --- |
| crossfade summing resistors | `R301-R308` | `20k` | equal-value network start |
| feedback pot series floor | `R321`, `R322` | `10k` | prevents hard-zero instability |
| feedback return resistors | `R323`, `R324` | `20k` to `100k` capture placeholders | tune loop gain on bench |
| feedback compensation footprints | `C321`, `C322` | `47 pF`, DNP default | one per channel or shared utility stage |
| wet output isolators | `R341`, `R342` | `100R` | useful if the return harness loading changes |

## 5. Filter / Clipper Board

### Recommended Designator Reservations

| Block | Recommended RefDes Block |
| --- | --- |
| left HPF | `R401-R419`, `C401-C409` |
| right HPF | `R421-R439`, `C421-C429` |
| left/right drive and clip | `R441-R469`, `C441-C449`, `D401-D412` |
| left LPF | `R471-R489`, `C471-C479` |
| right LPF | `R491-R509`, `C491-C499` |
| output buffers and local utility | `R511-R519`, `C511-C519` |
| local decoupling and rail bulk | `C591-C599` |

### Starting Circuit Table

| Stage | Part Group | Start Value / Part | Notes |
| --- | --- | --- | --- |
| filter timing footprints | `C401-C409`, `C421-C429`, `C471-C479`, `C491-C499` | fit `10 nF`, `22 nF`, and `47 nF` options | keep the board flexible during tuning |
| general filter resistor space | `R401-R419`, `R421-R439`, `R471-R509` | start around `10k` to `33k` capture values | exact values depend on chosen topology |
| clip silicon pair | `D401-D404` | `1N4148W` | symmetrical silicon option |
| clip LED pair | `D405-D408` | red SMD LED pair | higher threshold clip option |
| clip germanium pair | `D409-D412` | germanium or adapter footprints | asymmetrical option if needed |
| drive gain placeholder resistors | `R441-R448` | choose values that allow `0 dB` to `+20 dB` range | bench-tune around actual clip feel |

## 6. Power / Backplane Board

### Recommended Designator Reservations

| Block | Recommended RefDes Block |
| --- | --- |
| DC entry and protection | `J500`, `D500`, `F500`, `TVS500`, `C500` |
| low-voltage conversion | `PS500`, `PS501`, `FB500-FB501`, `C501-C514` |
| board power fan-out and test | `P501-P506`, `TP501-TP509` |
| chassis bond / star point | `R551`, `C551`, `L551` if used | 

### Starting Circuit Table

| Stage | Part Group | Start Value / Part | Notes |
| --- | --- | --- | --- |
| split-rail outputs | `P501-P505` | `3-position JST VH` | `+15VA`, `AGND`, `-15VA` |
| ext-routing power | `P506` | `4-position JST VH` | includes `+5VAUX` |
| chassis bond placeholder | `R551/C551` | reserve for bond strategy parts if used | only one controlled bond point |
| local rail bulk | `C501-C519` | power-only ceramic/electrolytic set | not in the audio path |

## What This File Intentionally Leaves Open

- exact final filter topology values
- exact primary send bias network values
- exact feedback loop gain values
- any final compensation part that only real bench work can justify

That is intentional. The goal is to freeze what is already known while keeping honest room for the small set of values that still depend on the real spring hardware.

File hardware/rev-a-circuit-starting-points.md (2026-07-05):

# GAS Rev A Circuit Starting Points

This file is the bridge between the board briefs and real schematics. It does not pretend to be the final tuned schematic, but it locks the first-pass analog topologies and starting values that should go into KiCad.

## 1. Balanced Input / Output Board

## Capacitor Interpretation

In this file:

- the audio path should avoid ceramic, tantalum, and electrolytic capacitors where practical
- power-supply and rail-decoupling positions may use practical ceramic or electrolytic parts

### Balanced Input Receiver

Per channel:

- topology: precision differential receiver
- active device: `OPA1644AIDR`
- resistor strategy:
  - use matched 0.1% resistor ratios
  - start with `10k / 10k / 10k / 10k`
- input protection:
  - `100R` series per leg
  - `220 pF` RF shunt placeholders, preferably PPS-film or mica if fitted
  - clamp network footprint placeholders if needed after EMC testing

Intent:

- convert balanced `+4 dBu` nominal line input into the local single-ended wet/dry domain
- maintain good CMRR without relying on scarce specialty analog front-end ICs
- satisfy the JFET / BiFET preference on the input buffer stage

### Mono-Input To Stereo Switch

Rev A requirement:

- add a dedicated analog mono-input to stereo switch after the balanced receiver

Starting behavior:

- `Stereo`: left receiver feeds left channel, right receiver feeds right channel
- `Mono -> Stereo`: selected mono source feeds both left and right internal channels

Preferred implementation:

- switch the already-received single-ended audio, not the balanced external lines
- default the selected mono source to the left input path unless later product decisions require left/right source selection

### Wet/Dry Mix

Per channel:

- topology: active inverting summer
- active device: `OPA1656IDR`
- starting values:
  - `20k` dry input resistor
  - `20k` wet input resistor
  - `20k` feedback resistor
- make the control law adjustable by changing the wet/dry pot taper later if listening tests call for it

### Balanced Output Driver

Per channel:

- topology: fully active dual-op-amp balanced line driver
- active devices:
  - `2x OPA1656IDR` total for stereo output
- starting values:
  - gain of `1`
  - `49.9R` series output resistor on each leg
  - optional RF shunt footprint at the connector-facing side

Intent:

- deliver balanced line output
- tolerate 600-ohm style professional interfacing
- keep common SMD active parts consistent with the rest of the design
- do not treat the rev-A output as optional, pseudo-balanced, or unbalanced

## 2. Tank Driver / Recovery Board

### Primary 4AB1C1B Send Driver

Per primary tank:

- topology: split-rail op-amp predriver plus complementary emitter-follower output stage
- active devices:
  - `OPA1656IDR`
  - `BD139-16`
  - `BD140-16`
- supply: `+15VA` and `-15VA`
- starting values:
  - op-amp stage gain: start near unity to modest gain
  - emitter resistors: start around `0.22R` to `0.47R` placeholders
  - base-stopper resistors: include footprints on both transistor bases
  - bias spreader / diode-bias network: include trim or selection option
  - zobel: `10R + 47 nF`, with film preferred for the capacitor
  - series trim resistor footprint between driver and tank input

Intent:

- drive the low-impedance 8-ohm primary tank input from the existing split rails
- avoid a large audio-path coupling capacitor if practical
- keep the stage simple enough for rev A while aligning better with the audio-path capacitor policy

### Secondary 9EBxC1B Send Driver

Per secondary tank:

- topology: non-inverting op-amp driver
- active device: `OPA1656IDR`
- starting values:
  - gain: start at `2.0` to `2.2`
  - feedback resistor: `12k`
  - ground resistor: `10k`
  - output series resistor: `220R`
  - keep this stage direct-coupled on split rails if stability and DC conditions allow
  - if a coupling capacitor is still required, prefer film and treat electrolytics as an exception rather than the default

Intent:

- drive the 800-ohm-input secondary tanks cleanly from standard high-headroom audio op-amp stages

### Tank Recovery Preamps

Per tank return:

- topology: AC-coupled non-inverting recovery stage
- topology note: if recovery biasing can be arranged cleanly, direct coupling is preferred over unnecessary coupling capacitors
- active device: `OPA1656IDR`
- starting values:
  - input coupling capacitor: `22 nF`, film preferred if coupling is required
  - bias to ground: `2.2M`
  - gain resistor to ground: `1k`
  - feedback resistor: start at `33k`
  - small feedback capacitor footprint: `47 pF` to `100 pF`, preferably mica or PPS-film where practical
  - output DC blocking only if later testing shows offset problems

Intent:

- prioritize low noise and stable recovery before trying to maximize raw gain

## 3. Ext Tank Routing Board

### Mode Switching

- use `G6K-2F-Y-DC5` relays in the audio path
- keep relay control separate from audio wiring
- add local flyback suppression if the coils are transistor-driven

### Series / Parallel Gain Staging

Starting approach:

- route audio with relays
- use unity-gain buffer points around switch nodes
- use one OPA1679 quad to cover:
  - left primary/secondary blend
  - right primary/secondary blend
  - optional series-path makeup gain
  - spare test or utility stage

Starting resistor values:

- unity-gain summers: `20k` input resistors, `20k` feedback
- series-path makeup trim footprint: `20k` nominal plus trim option

## 4. Crossfade / Feedback / Wet Summing Board

### Stereo Crossfade

Per stereo pair:

- topology: dual cross-mix around one OPA1679
- start with equal-value resistor network:
  - `20k` nominal summing resistors
  - crossfade control implemented by variable split between own-channel and opposite-channel contribution

Intent:

- preserve constant-ish level while moving between isolated stereo and crossfed stereo

### Feedback Loop

Per channel:

- topology: inverting feedback send/return mix
- start with:
  - `100k` feedback amount pot
  - `10k` series floor resistor so the loop never hard-shorts into instability
  - DPDT phase-invert switch in the loop
  - optional compensation footprint: `47 pF` across the feedback resistor, preferably mica or PPS-film where practical

Intent:

- make loop stability adjustable on the bench instead of forcing a second PCB spin for compensation alone

## 5. Filter / Clipping Board

### Filter Topology

Rev A recommendation:

- use active 2-pole state-variable or multiple-feedback sections
- keep the PCB flexible enough to tune between the two during capture if one is mechanically easier

First-pass target:

- per channel:
  - one pre-clipping HPF section
  - one post-clipping LPF section
- active device family: `OPA1679IDR`

Starting capacitor family:

- audio-path timing caps should begin with film, PPS-film, polypropylene, polyester, or mica choices
- avoid ceramic timing caps where practical
- start with `10 nF`, `22 nF`, and `47 nF` footprints available around the filter equations

### Drive And Clipping

Per channel:

- op-amp gain stage ahead of clip network
- start drive control around a `0 dB` to `+20 dB` range
- clip mode selection:
  - `Clean`: bypass clip network
  - `Silicon`: anti-parallel small-signal silicon diodes
  - `LED`: anti-parallel LEDs
  - `Germanium`: asymmetrical germanium pair

Suggested starting diode footprints:

- silicon: `1N4148W`
- germanium: SMD germanium availability varies, so leave both SMD and leaded-adapter footprints if board area permits
- LED: small SMD red LED pair

## Parts Families To Keep Common

- 0.1% resistor values for balanced receiver/output stages
- 1% resistor values for general audio gain stages
- practical local rail decouplers at every IC
- practical bulk rail capacitors per board
- `OPA1656IDR` and `OPA1679IDR` as the default audio op-amp family

## What To Tune First On The Bench

1. Primary send level into `4AB1C1B`
2. Recovery gain and noise floor
3. Series versus parallel level matching
4. Feedback loop stability
5. HPF / LPF ranges against listening tests

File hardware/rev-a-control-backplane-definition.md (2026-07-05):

# GAS Rev A Control Backplane Definition

This file defines the preferred rev-A solution for the denser control groups.

The backplane is still fully analog in spirit:

- no MCU
- no digital audio
- no embedded computer

It only centralizes panel controls, passive control wiring, and simple relay-driver or mode-encoding support where that is cleaner than long direct runs to every audio board.

## Purpose

- land the dense front-panel controls
- decode mode selectors into the existing control nets
- keep passive control harnessing organized
- optionally reserve space for `ULN2003ADR` or similar future support if a later revision changes the harness to give the backplane real coil-drive or indicator ownership

## Recommended Active Content

- `U601` `ULN2003ADR`
  - optional reserve only
  - do not assume it is populated in the current fixed rev-A harness because the frozen inter-board interface carries only the two ext-mode outputs, not a dedicated expanded relay-driver bus
  - if the simple direct-drive rev-A strategy is retained, `CTL_EXT_MODE_A/B` themselves should be treated as the switched `+5VAUX` relay-control outputs

## Power

### P601 Backplane Power

- preferred connector: `JST VH` 4-position
- pins:
  - `1` `+5VAUX`
  - `2` `AGND`
  - `3` `+15VA`
  - `4` `-15VA`

Practical note:

- most of the control backplane only needs `+5VAUX` and `AGND`
- the split rails are included so the board can still serve as the common control landing board if local analog buffering or LED/reference support is later added

## Board-Side Control Connectors

### P610 I/O Controls

- preferred connector: `JST XH` 9-position
- carries:
  - `WD_L_HI`
  - `WD_L_WIPER`
  - `WD_L_LO`
  - `WD_R_HI`
  - `WD_R_WIPER`
  - `WD_R_LO`
  - `MONO_A`
  - `MONO_C`
  - `MONO_B`

### P611 Ext Routing Controls

- preferred connector: `JST XH` 10-position
- carries:
  - `EXTMIX_L_HI`
  - `EXTMIX_L_WIPER`
  - `EXTMIX_L_LO`
  - `EXTMIX_R_HI`
  - `EXTMIX_R_WIPER`
  - `EXTMIX_R_LO`
  - `+5VAUX`
  - `AGND`
  - `CTL_EXT_MODE_A`
  - `CTL_EXT_MODE_B`

### P612 Crossfade / Feedback Controls

- preferred connector: `JST XH` 10-position
- carries:
  - `XFD_L_HI`
  - `XFD_L_WIPER`
  - `XFD_L_LO`
  - `XFD_R_HI`
  - `XFD_R_WIPER`
  - `XFD_R_LO`
  - `FB_L_WIPER`
  - `FB_R_WIPER`
  - `CTL_FB_INV`
  - `AGND`

Practical note:

- if the feedback amount law ends up needing full six-wire raw dual-pot wiring instead of local bias endpoints on the crossfade board, split this into two connectors rather than overcompressing the harness

### P613 Filter / Clipper Controls A

- preferred connector: `JST XH` 12-position
- carries:
  - `DRV_HI`
  - `DRV_WIPER`
  - `DRV_LO`
  - `HPF_F_L_HI`
  - `HPF_F_L_WIPER`
  - `HPF_F_L_LO`
  - `HPF_F_R_HI`
  - `HPF_F_R_WIPER`
  - `HPF_F_R_LO`
  - `HPF_Q_L_WIPER`
  - `HPF_Q_R_WIPER`
  - `AGND`

### P614 Filter / Clipper Controls B

- preferred connector: `JST XH` 12-position
- carries:
  - `LPF_F_L_HI`
  - `LPF_F_L_WIPER`
  - `LPF_F_L_LO`
  - `LPF_F_R_HI`
  - `LPF_F_R_WIPER`
  - `LPF_F_R_LO`
  - `LPF_Q_L_WIPER`
  - `LPF_Q_R_WIPER`
  - `+5VAUX`
  - `CTL_CLIP_MODE_A`
  - `CTL_CLIP_MODE_B`
  - `AGND`

## Panel-Side Hardware

The backplane is the preferred landing point for:

- `J701` ext mode rotary
- `J702` clip mode rotary
- `VR701` wet/dry dual pot
- `VR702` ext amount dual pot
- `VR703` crossfade dual pot
- `VR704` feedback dual pot
- `VR705` drive pot
- `VR706` HPF cutoff dual pot
- `VR707` HPF Q dual pot
- `VR708` LPF cutoff dual pot
- `VR709` LPF Q dual pot
- `SW701` mono-to-stereo
- `SW702` feedback phase

## Encoding Rules

### Ext Mode

- `00` = `Off`
- `10` = `Series`
- `11` = `Parallel`
- `01` = reserved / off-equivalent service state

### Clip Mode

- `00` = `Clean`
- `01` = `Silicon`
- `10` = `LED`
- `11` = `Germanium`

## Why This Board Is Worth Keeping

Without it, rev A starts to accumulate:

- too many long passive control runs
- too many tiny inconsistent control headers
- avoidable front-panel wiring clutter

With it, the build package becomes easier to quote and easier to service while still staying fully within the analog-only project constraint.

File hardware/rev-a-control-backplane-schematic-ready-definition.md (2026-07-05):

# GAS Rev A Control Backplane Schematic-Ready Definition

This file is the direct electrical definition for the rev-A control backplane layer.

It is the practical companion to [rev-a-control-backplane-definition.md](C:/Users/Jason/GAS-build/repo/hardware/rev-a-control-backplane-definition.md:1), [rev-a-control-harnesses.md](C:/Users/Jason/GAS-build/repo/hardware/rev-a-control-harnesses.md:1), and [rev-a-electrical-capture-worksheet.md](C:/Users/Jason/GAS-build/repo/hardware/rev-a-electrical-capture-worksheet.md:1).

Use this file when:

- deciding whether the current rev-A control strategy stays as a distinct backplane or collapses into direct panel wiring
- translating the dense-control wiring into a future KiCad page or a later expansion of the current `power-backplane.kicad_sch`
- checking that the panel control layer stays analog-only and honest about which controls are raw passive landings versus encoded mode selectors

## 1. Assumed First-Pass Control-Backplane Strategy

This definition freezes the first-pass control-backplane role as:

- no audio signal processing on the backplane
- passive landing and redistribution for off-board pots and switches
- local generation of the encoded mode pairs for ext-routing and clip mode
- optional future reserve for simple coil or indicator support, but not relied on by the current frozen inter-board harness

Important note:

- the current rev-A harness contract between the control layer and the ext-routing board carries only `CTL_EXT_MODE_A` and `CTL_EXT_MODE_B`
- because of that, a `ULN2003ADR` on the control backplane cannot directly drive the ext-routing relay coils without changing the frozen inter-board interface
- if rev A keeps the simplest direct-drive relay strategy, those two exported mode lines should be interpreted as the switched `+5VAUX` outputs themselves, not as separate logic-only sense lines
- therefore `U601` should be treated as a reserve-only symbol for now, not a required populated rev-A part

## 2. First-Pass Electrical Boundary

The control backplane should remain fully compatible with the current project constraints:

- no MCU
- no programmable logic
- no digital audio
- no computer-style control plane

The only active behavior currently justified here is:

- switch-to-bit encoding for mode selectors
- optional passive or transistorized indicator/relay support if the inter-board interface later grows to support it

## 3. Board-Side Connector Ownership

### P601 Backplane Power

| Pin | Net | Meaning |
| --- | --- | --- |
| `1` | `+5VAUX` | main control logic-high rail |
| `2` | `AGND` | control reference |
| `3` | `+15VA` | reserve split rail |
| `4` | `-15VA` | reserve split rail |

Practical rule:

- the current rev-A passive control scheme should assume only `+5VAUX` and `AGND` are required on the backplane
- `+15VA` and `-15VA` remain reserved for later analog buffer or indicator support and should not be assumed by the base passive wiring

### P610 I/O Controls

| Pin | Net | Meaning |
| --- | --- | --- |
| `1` | `WD_L_HI` | left wet/dry pot dry end |
| `2` | `WD_L_WIPER` | left wet/dry wiper |
| `3` | `WD_L_LO` | left wet/dry pot wet end |
| `4` | `WD_R_HI` | right wet/dry pot dry end |
| `5` | `WD_R_WIPER` | right wet/dry wiper |
| `6` | `WD_R_LO` | right wet/dry pot wet end |
| `7` | `MONO_A` | mono switch throw A |
| `8` | `MONO_C` | mono switch common |
| `9` | `MONO_B` | mono switch throw B |

### P611 Ext Routing Controls

| Pin | Net | Meaning |
| --- | --- | --- |
| `1` | `EXTMIX_L_HI` | left ext-amount top end |
| `2` | `EXTMIX_L_WIPER` | left ext-amount wiper |
| `3` | `EXTMIX_L_LO` | left ext-amount low end |
| `4` | `EXTMIX_R_HI` | right ext-amount top end |
| `5` | `EXTMIX_R_WIPER` | right ext-amount wiper |
| `6` | `EXTMIX_R_LO` | right ext-amount low end |
| `7` | `+5VAUX` | mode-encoding high rail |
| `8` | `AGND` | mode-encoding reference |
| `9` | `CTL_EXT_MODE_A` | ext-mode encoded bit A |
| `10` | `CTL_EXT_MODE_B` | ext-mode encoded bit B |

### P612 Crossfade / Feedback Controls

Keep the current rev-A grouped landing below, but treat it as a consciously compressed interface:

| Pin | Net | Meaning |
| --- | --- | --- |
| `1` | `XFD_L_HI` | left crossfade top end |
| `2` | `XFD_L_WIPER` | left crossfade wiper |
| `3` | `XFD_L_LO` | left crossfade low end |
| `4` | `XFD_R_HI` | right crossfade top end |
| `5` | `XFD_R_WIPER` | right crossfade wiper |
| `6` | `XFD_R_LO` | right crossfade low end |
| `7` | `FB_L_WIPER` | left feedback control wiper only |
| `8` | `FB_R_WIPER` | right feedback control wiper only |
| `9` | `CTL_FB_INV` | feedback invert control |
| `10` | `AGND` | control reference |

Practical rule:

- this is sufficient for the current placeholder capture
- it is not yet a fully honest raw passive dual-gang feedback-pot interface
- before final PCB release, either:
  - promote this into a larger raw-feedback header set, or
  - make the feedback pot local to the control backplane and explicitly generate the missing endpoint references there

### P613 Filter / Clipper Controls A

| Pin | Net | Meaning |
| --- | --- | --- |
| `1` | `DRV_HI` | drive-pot top end |
| `2` | `DRV_WIPER` | drive-pot wiper |
| `3` | `DRV_LO` | drive-pot low end |
| `4` | `HPF_F_L_HI` | left HPF cutoff top end |
| `5` | `HPF_F_L_WIPER` | left HPF cutoff wiper |
| `6` | `HPF_F_L_LO` | left HPF cutoff low end |
| `7` | `HPF_F_R_HI` | right HPF cutoff top end |
| `8` | `HPF_F_R_WIPER` | right HPF cutoff wiper |
| `9` | `HPF_F_R_LO` | right HPF cutoff low end |
| `10` | `HPF_Q_L_WIPER` | left HPF-Q wiper only |
| `11` | `HPF_Q_R_WIPER` | right HPF-Q wiper only |
| `12` | `AGND` | control reference |

### P614 Filter / Clipper Controls B

| Pin | Net | Meaning |
| --- | --- | --- |
| `1` | `LPF_F_L_HI` | left LPF cutoff top end |
| `2` | `LPF_F_L_WIPER` | left LPF cutoff wiper |
| `3` | `LPF_F_L_LO` | left LPF cutoff low end |
| `4` | `LPF_F_R_HI` | right LPF cutoff top end |
| `5` | `LPF_F_R_WIPER` | right LPF cutoff wiper |
| `6` | `LPF_F_R_LO` | right LPF cutoff low end |
| `7` | `LPF_Q_L_WIPER` | left LPF-Q wiper only |
| `8` | `LPF_Q_R_WIPER` | right LPF-Q wiper only |
| `9` | `+5VAUX` | clip-mode encoding high rail |
| `10` | `CTL_CLIP_MODE_A` | clip-mode encoded bit A |
| `11` | `CTL_CLIP_MODE_B` | clip-mode encoded bit B |
| `12` | `AGND` | control reference |

Practical rule:

- `P613` and `P614` are sufficient for the current grouped-control placeholder strategy
- the `HPF_Q_*` and `LPF_Q_*` entries are still compressed relative to a fully raw passive stereo pot landing
- before final PCB release, either:
  - promote those Q controls into fuller raw passive interfaces, or
  - make the Q controls local to the control backplane and explicitly generate the missing endpoint references there

## 4. Panel-Side Hardware Ownership

Use these panel refs as the first-pass control-backplane ownership map:

| Ref | Type | Function |
| --- | --- | --- |
| `VR701` | dual pot | wet/dry |
| `VR702` | dual pot | ext amount |
| `VR703` | dual pot | crossfade |
| `VR704` | dual pot | feedback |
| `VR705` | single pot | drive |
| `VR706` | dual pot | HPF cutoff |
| `VR707` | dual pot | HPF Q |
| `VR708` | dual pot | LPF cutoff |
| `VR709` | dual pot | LPF Q |
| `SW701` | SPDT or 3-state source switch | mono/stereo |
| `SW702` | SPDT | feedback invert |
| `J701` | rotary mode switch | ext mode |
| `J702` | rotary mode switch | clip mode |

## 5. Raw Passive Wiring Ownership

### Wet / Dry

`VR701` should wire directly to `P610`:

- left track to `WD_L_HI`, `WD_L_WIPER`, `WD_L_LO`
- right track to `WD_R_HI`, `WD_R_WIPER`, `WD_R_LO`

### Ext Amount

`VR702` should wire directly to `P611`:

- left track to `EXTMIX_L_HI`, `EXTMIX_L_WIPER`, `EXTMIX_L_LO`
- right track to `EXTMIX_R_HI`, `EXTMIX_R_WIPER`, `EXTMIX_R_LO`

### Crossfade

`VR703` should wire directly to `P612`:

- left track to `XFD_L_HI`, `XFD_L_WIPER`, `XFD_L_LO`
- right track to `XFD_R_HI`, `XFD_R_WIPER`, `XFD_R_LO`

### Feedback

`VR704` is not yet fully represented as a raw passive interface in the frozen 10-pin grouping.

Therefore the current schematic-ready interpretation is:

- `FB_L_WIPER` and `FB_R_WIPER` are the only mandatory frozen boundary nets today
- the exact local endpoint generation for the feedback dual pot remains a later design choice

### Drive

`VR705` should wire directly to `P613`:

- `DRV_HI`, `DRV_WIPER`, `DRV_LO`

### HPF Cutoff

`VR706` should wire directly to `P613`:

- left track to `HPF_F_L_HI`, `HPF_F_L_WIPER`, `HPF_F_L_LO`
- right track to `HPF_F_R_HI`, `HPF_F_R_WIPER`, `HPF_F_R_LO`

### HPF Q

`VR707` is only partially represented in the current grouped interface:

- mandatory frozen nets today are `HPF_Q_L_WIPER` and `HPF_Q_R_WIPER`
- the endpoint strategy remains deferred unless the interface is promoted

### LPF Cutoff

`VR708` should wire directly to `P614`:

- left track to `LPF_F_L_HI`, `LPF_F_L_WIPER`, `LPF_F_L_LO`
- right track to `LPF_F_R_HI`, `LPF_F_R_WIPER`, `LPF_F_R_LO`

### LPF Q

`VR709` is only partially represented in the current grouped interface:

- mandatory frozen nets today are `LPF_Q_L_WIPER` and `LPF_Q_R_WIPER`
- the endpoint strategy remains deferred unless the interface is promoted

## 6. Encoded Mode Ownership

### SW701 Mono Switch

`SW701` should remain the raw 3-wire switch landing:

| Switch Terminal | Net |
| --- | --- |
| `A` | `MONO_A` |
| `C` | `MONO_C` |
| `B` | `MONO_B` |

### SW702 Feedback Invert

The first-pass interpretation should stay simple:

- `CTL_FB_INV` is asserted or grounded by `SW702`
- `AGND` is the low state
- if needed, a pull-up or pull-down can live locally on the target board rather than on the backplane

### J701 Ext Mode

Freeze `J701` as a two-pole three-position rotary or functionally equivalent discrete analog switch arrangement.

Required bit map:

| User Position | `CTL_EXT_MODE_A` | `CTL_EXT_MODE_B` |
| --- | --- | --- |
| `Off` | `0` | `0` |
| `Series` | `1` | `0` |
| `Parallel` | `1` | `1` |

The unused `01` state should remain unselected by the panel hardware.

### J702 Clip Mode

Freeze `J702` as a two-pole four-position rotary or functionally equivalent discrete analog switch arrangement.

Required bit map:

| User Position | `CTL_CLIP_MODE_A` | `CTL_CLIP_MODE_B` |
| --- | --- | --- |
| `Clean` | `0` | `0` |
| `Silicon` | `0` | `1` |
| `LED` | `1` | `0` |
| `Germanium` | `1` | `1` |

## 7. `U601` Reserve Policy

`U601` `ULN2003ADR` should remain a reserve-only footprint or symbol unless the inter-board control contract changes.

Reason:

- the current frozen ext-routing interface carries encoded mode lines, not direct coil-drive lines
- without additional coil-drive nets in the harness, the backplane cannot directly own relay sinking

Therefore the current rev-A policy is:

1. do not treat `U601` as required
2. keep it absent from any fixed populated BOM unless the harness contract changes
3. if a later revision moves relay sinking to the backplane, update:
   - `rev-a-interconnect-pin-map.md`
   - `rev-a-board-connector-schedule.csv`
   - `rev-a-ext-routing-schematic-ready-definition.md`
   - the KiCad manifests

## 8. Current KiCad Capture Relationship

The checked-in `power-backplane.kicad_sch` currently captures:

- `J500`
- `F500`
- `D500`
- `TVS500`
- `C500`
- `PS500`
- `PS501`
- `FB500`
- `FB501`
- `P501-P506`
- `P601`

It does not yet instantiate:

- `P610-P614`
- `U601`

That is acceptable for the present phase, but it means the control-backplane layer remains a definition-level artifact rather than a real KiCad-wired page today.

## 9. Verification Gate For The Later KiCad Pass

When this definition is translated into the later real KiCad control-backplane pass, verify all of the following:

1. `P601` keeps the frozen `+5VAUX / AGND / +15VA / -15VA` order.
2. `P610` and `P611` remain fully honest raw passive or encoded interfaces and are not compressed further.
3. `J701` and `J702` cannot select illegal intermediate states in normal panel use.
4. `U601` is only populated if the harness definition is updated to support real coil-drive ownership from the backplane.
5. Any remaining compressed grouped headers are called out explicitly on the schematic notes instead of being mistaken for fully raw passive harnesses.

## 10. Explicitly Deferred Items

These are intentionally deferred:

- whether the control-backplane remains a distinct PCB or is folded into an expanded power/backplane board
- the final endpoint strategy for the off-board feedback, HPF-Q, and LPF-Q passive controls
- any future indicator LED or relay-drive features that would justify populating `U601`

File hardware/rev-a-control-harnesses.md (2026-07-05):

# GAS Rev A Control Harnesses

This file defines the rev-A front-panel control wiring in a way that can actually be captured and built.

It exists because several rev-A controls are stereo dual-gang parts, and those cannot be represented honestly as vague one-net control abstractions if the first hardware pass uses passive panel controls.

## Control Wiring Strategy

Rev A supports two valid implementations:

1. board-mounted controls where a board sits directly behind the panel
2. a power/control/backplane board that lands the panel controls and routes them to the audio boards

For the denser stereo-control groups, option `2` is preferred.

## Raw Control Pin Convention

For passive panel controls, use these labels:

### Single Pot

- `HI`
- `WIPER`
- `LO`

### Dual-Gang Pot

- `L_HI`
- `L_WIPER`
- `L_LO`
- `R_HI`
- `R_WIPER`
- `R_LO`

### SPDT Toggle

- `A`
- `C`
- `B`

### Encoded Mode Switch

For mode selectors that are decoded into logic-like control lines on the control backplane:

- `+5VAUX`
- `AGND`
- `CTL_*_A`
- `CTL_*_B`

## Harness Set

### H21 Wet / Dry Control

- from: panel dual-gang pot
- to: I/O board `P5` or control backplane landing
- preferred connector: `JST XH` 6-position
- conductors:
  - `WD_L_HI`
  - `WD_L_WIPER`
  - `WD_L_LO`
  - `WD_R_HI`
  - `WD_R_WIPER`
  - `WD_R_LO`

### H22 Mono Source To Stereo

- from: panel SPDT toggle
- to: I/O board `P6` or control backplane landing
- preferred connector: `JST XH` 3-position
- conductors:
  - `MONO_A`
  - `MONO_C`
  - `MONO_B`

### H23 Ext Reverb Tanks Amount

- from: panel dual-gang pot
- to: ext-routing board analog-control input or control backplane landing
- preferred connector: `JST XH` 6-position
- conductors:
  - `EXTMIX_L_HI`
  - `EXTMIX_L_WIPER`
  - `EXTMIX_L_LO`
  - `EXTMIX_R_HI`
  - `EXTMIX_R_WIPER`
  - `EXTMIX_R_LO`

### H24 Ext Reverb Tanks Mode

- from: panel mode rotary
- to: ext-routing board or control backplane logic landing
- preferred connector: `JST XH` 4-position
- conductors:
  - `+5VAUX`
  - `AGND`
  - `CTL_EXT_MODE_A`
  - `CTL_EXT_MODE_B`

Encoding:

- `00` = `Off`
- `10` = `Series`
- `11` = `Parallel`
- `01` = reserved / off-equivalent service state

### H25 Crossfade Amount

- from: panel dual-gang pot
- to: crossfade / feedback / wet board `P307` or control backplane landing
- preferred connector: `JST XH` 6-position
- conductors:
  - `XFD_L_HI`
  - `XFD_L_WIPER`
  - `XFD_L_LO`
  - `XFD_R_HI`
  - `XFD_R_WIPER`
  - `XFD_R_LO`

### H26 Feedback Amount

- from: panel dual-gang pot
- to: crossfade / feedback / wet board `P307` or control backplane landing
- preferred connector: `JST XH` 6-position
- conductors:
  - `FB_L_HI`
  - `FB_L_WIPER`
  - `FB_L_LO`
  - `FB_R_HI`
  - `FB_R_WIPER`
  - `FB_R_LO`

### H27 Feedback Phase

- from: panel SPDT toggle or backplane-encoded control
- to: crossfade / feedback / wet board `P307`
- preferred connector: `JST XH` 4-position if encoded
- conductors:
  - `+5VAUX`
  - `AGND`
  - `CTL_FB_INV`
  - `SPARE`

Preferred implementation note:

- if the phase inversion is executed by a local relay or analog switch on the crossfade board, this encoded harness is preferred
- if the phase switch itself is mounted directly on the crossfade board, no separate harness is needed

### H28 Drive

- from: panel single-gang pot
- to: filter / clipper board `P403` or control backplane landing
- preferred connector: `JST XH` 3-position
- conductors:
  - `DRV_HI`
  - `DRV_WIPER`
  - `DRV_LO`

### H29 HPF Cutoff

- from: panel dual-gang pot
- to: filter / clipper board `P403` or control backplane landing
- preferred connector: `JST XH` 6-position
- conductors:
  - `HPF_F_L_HI`
  - `HPF_F_L_WIPER`
  - `HPF_F_L_LO`
  - `HPF_F_R_HI`
  - `HPF_F_R_WIPER`
  - `HPF_F_R_LO`

### H30 HPF Q

- from: panel dual-gang pot
- to: filter / clipper board `P405` or control backplane landing
- preferred connector: `JST XH` 6-position
- conductors:
  - `HPF_Q_L_HI`
  - `HPF_Q_L_WIPER`
  - `HPF_Q_L_LO`
  - `HPF_Q_R_HI`
  - `HPF_Q_R_WIPER`
  - `HPF_Q_R_LO`

### H31 LPF Cutoff

- from: panel dual-gang pot
- to: filter / clipper board `P403` or control backplane landing
- preferred connector: `JST XH` 6-position
- conductors:
  - `LPF_F_L_HI`
  - `LPF_F_L_WIPER`
  - `LPF_F_L_LO`
  - `LPF_F_R_HI`
  - `LPF_F_R_WIPER`
  - `LPF_F_R_LO`

### H32 LPF Q

- from: panel dual-gang pot
- to: filter / clipper board `P405` or control backplane landing
- preferred connector: `JST XH` 6-position
- conductors:
  - `LPF_Q_L_HI`
  - `LPF_Q_L_WIPER`
  - `LPF_Q_L_LO`
  - `LPF_Q_R_HI`
  - `LPF_Q_R_WIPER`
  - `LPF_Q_R_LO`

### H33 Clip Mode

- from: panel rotary selector
- to: filter / clipper board `P405` or control backplane landing
- preferred connector: `JST XH` 4-position
- conductors:
  - `+5VAUX` — **source is the panel 5V bus, NOT the filter board.**
    The filter board's `P405` pin 9 is a spare with no on-board 5V feed
    (its power input H13/`P404` is ±15V only). Feed the clip rotary common
    from the same +5VAUX bus that feeds the ext-mode rotary common
    (arrives at the panel on ext board `P206` pin 7, sourced from
    power-backplane `P506.4` via `P207.4`). One short panel jumper wire
    between the two rotary commons is the rev-A wiring.
    Do not wire `P405` pin 9 as the 5V source — the clip relays would
    never energize. (Found in the 2026-07-04 pre-order review; a 4-pin
    `P404`/`P504` power feed is the recorded rev-B fix.)
  - `AGND`
  - `CTL_CLIP_MODE_A`
  - `CTL_CLIP_MODE_B`

Encoding:

- `00` = `Clean`
- `01` = `Silicon`
- `10` = `LED`
- `11` = `Germanium`

## Practical Result

This wiring map makes two important rev-A implications explicit:

1. `Wet / Dry`, `Ext Amount`, `Crossfade`, `Feedback`, `HPF Cutoff`, `HPF Q`, `LPF Cutoff`, and `LPF Q` are all better treated as real 6-wire stereo controls if they are off-board.
2. a control-backplane or locally board-mounted controls are cleaner than pretending all of these can be handled by a few tiny generic control headers.

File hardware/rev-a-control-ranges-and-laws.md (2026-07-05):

# GAS Rev A Control Ranges And Laws

This file maps the current JUCE control behavior into rev-A hardware control recommendations.

The intent is not to force the first analog prototype to feel identical to the plugin on day one. The intent is to stop the hardware controls from drifting into arbitrary ranges or tapers while schematic capture is still in progress.

Source for the current software ranges and defaults:

- [PluginProcessor.cpp](C:/Users/Jason/GAS-build/repo/Source/PluginProcessor.cpp:606)
- [applyDefaultGasSettings()](C:/Users/Jason/GAS-build/repo/Source/PluginProcessor.cpp:757)

There are two relevant "defaults" in the software:

1. the parameter-layout defaults used when the parameters are declared
2. the curated `applyDefaultGasSettings()` preset that the processor applies as the GAS startup/default state

For rev-A hardware panel marks and startup assumptions, the curated `applyDefaultGasSettings()` values are the better reference unless the product direction changes later.

## Main Control Table

| Control | Plugin Range | Layout Default | GAS Default | Rev-A Hardware Element | Recommended Hardware Law | Notes |
| --- | --- | --- | --- | --- | --- | --- |
| `Crossfade Amount` | `0.0` to `1.0` | `0.2` | `0.0` | dual-gang pot | electrical law set by resistor network around a linear pot | the curated startup state is fully uncrossfed |
| `Mode` | `Clean / Silicon / LED / Germanium` | `Clean` | `Clean` | 4-position rotary | hard switched | make `Clean` the fully bypassed clip mode |
| `Drive` | `0 dB` to `+30 dB` | `+6 dB` | `+6 dB` | pot | audio/log-like gain feel | the plugin has a wide gain span, so reserve enough gain before clipping |
| `HPF Cutoff` | `1 Hz` to `4000 Hz` | `120 Hz` | `100 Hz` | dual-gang pot | log-like sweep | do not use a raw linear-feeling frequency sweep |
| `HPF Q` | `0.25` to `8.0` | `0.707` | `1.0` | dual-gang pot | low-end resolution favored | keep the useful range around `0.5` to `2.0` physically easy to hit |
| `LPF Cutoff` | `500 Hz` to `20000 Hz` | `16000 Hz` | `12000 Hz` | dual-gang pot | log-like sweep | keep most of the travel above a few kilohertz |
| `LPF Q` | `0.25` to `8.0` | `0.707` | `1.0` | dual-gang pot | low-end resolution favored | same handling recommendation as HPF Q |
| `Ext Reverb Tanks` | `Off / Series / Parallel` | `Parallel` | `Off` | 3-position rotary or equivalent relay logic | hard switched | the curated startup state bypasses the secondary tanks |
| `Ext Reverb Tanks Amount` | `0.0` to `1.0` | `1.0` | `1.0` | dual-gang pot | near-linear blend behavior | keep full secondary contribution available when engaged |
| `Feedback` | `0.0` to `1.0` | `0.2` | `0.1` | dual-gang pot | controlled build-up near the low end | add fixed floor/series resistance so the loop never hard-shorts into instability |
| `Feedback Phase Invert` | `false / true` | `false` | `false` | toggle or pushbutton plus relay | hard switched | keep this in the feedback loop only |
| `Wet / Dry` | `0.0` to `1.0` | `0.5` | `0.5` | dual-gang pot | mix law set by summing network | center should sound like the nominal balanced mix point |
| `Mono Source To Stereo` | `false / true` | `false` | `false` | toggle | hard switched | switch after the balanced receiver |

## Software-Law Implications

The plugin already tells us something important about how the hardware controls should feel.

### Frequency Controls

The JUCE cutoff controls use a skewed `NormalisableRange` rather than a simple linear sweep.

That means rev A should not use:

- a pot law that feels linear in Hertz
- a control that crams the useful low-end range into a tiny travel region

Preferred rev-A approach:

- implement the frequency controls with a circuit law that feels roughly logarithmic
- use resistor padding, cap-range selection, or filter-law shaping so the lower frequencies get more panel travel

### Q Controls

The raw parameter defaults park both filter Q controls at `0.707`, while the curated GAS default preset moves them to `1.0`.

Preferred rev-A approach:

- make both `0.707` and `1.0` easy to hit repeatably
- do not optimize the control around only extreme resonance settings

### Blend Controls

`Crossfade`, `Ext Reverb Tanks Amount`, `Feedback`, and `Wet / Dry` are normalized in software.

That does not mean the hardware should use plain passive linear pots with no surrounding law shaping.

Preferred rev-A approach:

- use active summing or cross-mix resistor networks
- let the pot position control the weighting inside that network
- tune perceived balance on the bench instead of pretending a raw `50kB` pot automatically gives the right subjective law

## Default Positions Worth Marking On The Panel

These are the curated GAS defaults that are the best candidates for rev-A reference marks or calibration targets:

| Control | Plugin Default | Hardware Interpretation |
| --- | --- | --- |
| `Crossfade Amount` | `0%` | fully uncrossfed starting point |
| `Drive` | `+6 dB` | light push into the nonlinear stage |
| `HPF Cutoff` | `100 Hz` | useful low-frequency cleanup without obvious thinning |
| `HPF Q` | `1.0` | slightly more pointed than Butterworth |
| `LPF Cutoff` | `12 kHz` | open but not maximum-bright |
| `LPF Q` | `1.0` | slightly more pointed than Butterworth |
| `Ext Reverb Tanks` | `Off` | secondary tanks bypassed at startup |
| `Ext Reverb Tanks Amount` | `100%` | full secondary-tank contribution available |
| `Feedback` | `10%` | audible but conservative startup value |
| `Wet / Dry` | `50%` | equal starting mix |

## Recommended Pot And Switch Strategy

### High-Density Stereo Controls

Use dual-gang parts for:

- crossfade
- ext tank amount
- feedback
- wet/dry
- HPF cutoff
- HPF Q
- LPF cutoff
- LPF Q

### Best Candidates For Board-Mounted Or Backplane-Landed Controls

- `Drive`
- `HPF Cutoff`
- `HPF Q`
- `LPF Cutoff`
- `LPF Q`
- `Crossfade`
- `Feedback`

### Simple Local Control Exceptions

- `Mono Source To Stereo`
- `Feedback Phase Invert`
- `Mode`
- `Ext Reverb Tanks`

## First-Pass Bench Questions

When the first analog prototype exists, evaluate these before freezing final pot families:

1. Does the wet/dry blend feel level-consistent through the middle third of travel?
2. Does the crossfade control preserve an intentional perceived width change instead of only changing loudness?
3. Is the HPF low-end sweep usable across more than half the travel?
4. Is the LPF high-end sweep useful before the last small slice of pot travel?
5. Does feedback become musically active early enough without becoming unstable too abruptly?

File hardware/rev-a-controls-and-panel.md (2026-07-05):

# GAS Rev A Controls And Panel

This document captures the user-facing controls and service-endcap assumptions for the analog hardware.

## Enclosure Context

- cylindrical tube enclosure
- about `48 in` long
- target diameter `10 in` nominal
- all user connections and DC power entry on one circular endcap

Because the control count is high and the I/O format is fixed, the endcap is now the primary user interface rather than a conventional flat rack front panel.

## External Audio Connectors

Rev A uses combo `XLR / TRS` connectors for balanced line I/O.

### Proposed Panel I/O Count

- `J1` left input combo jack
- `J2` right input combo jack
- `J3` left output combo jack
- `J4` right output combo jack
- `J5` DC power jack for the external `+24 VDC` wall adapter

### Electrical Intent

- nominal balanced line level `+4 dBu`
- 600-ohm capable interfacing
- wall power stays outside the enclosure; only low-voltage DC enters the service endcap

## Core Controls

### Input / Output Section

- `Wet / Dry`
  - continuous control
- `Mono -> Stereo`
  - dedicated switch
  - duplicates the selected mono input into both internal channels after the balanced receiver

### Ext Tank Section

- `Ext Reverb Tanks`
  - `Off`
  - `Series`
  - `Parallel`
- `Ext Reverb Tanks Amount`
  - continuous control

### Crossfade / Feedback Section

- `Crossfade Amount`
  - continuous control
- `Feedback`
  - continuous control
- `Feedback Phase`
  - switch
  - normal / invert

### Filter / Clipping Section

- `Drive`
  - continuous control
- `HPF Cutoff`
  - continuous control
- `HPF Q`
  - continuous control
- `LPF Cutoff`
  - continuous control
- `LPF Q`
  - continuous control
- `Clip Mode`
  - `Clean`
  - `Silicon`
  - `LED`
  - `Germanium`

## Recommended Rev A Control Hardware Split

### Rotaries / Toggles

- ext tank mode rotary
- clip mode rotary
- mono-to-stereo switch
- feedback phase switch

### Pots

- wet/dry
- ext tank amount
- crossfade
- feedback
- drive
- HPF cutoff
- HPF Q
- LPF cutoff
- LPF Q

## Panel-Layout Consequences

- The unit has a relatively control-dense **circular endcap**
- The combo-jack requirement takes the widest chord across the face
- `10 in` nominal diameter is the preferred rev-A target: it fits four combo jacks plus the full control set with margin, and unlike `9 in` it is a standard off-the-shelf pipe/cap size
- Keep the mono-to-stereo switch near the input section so the behavior reads clearly
- Keep ext-tank mode and amount adjacent so Off / Series / Parallel behavior is easier to understand
- Keep feedback amount and feedback phase together
- Keep filter and clip controls grouped as one section
- Keep the DC jack away from the center knob field so a plugged-in barrel cable does not block hand access

## Builder Note

The panel hardware is not the same thing as the SMD core BOM.

Treat the panel layer as:

- combo jacks
- DC jack
- switches
- pots
- knobs
- circular endcap drilling/cutouts

That lets the analog PCBs stay modular while the enclosure is refined separately.

## Preferred Rev A Control Wiring

Two control-wiring strategies are acceptable in rev A:

1. board-mounted controls where the PCB can sit directly behind the panel
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

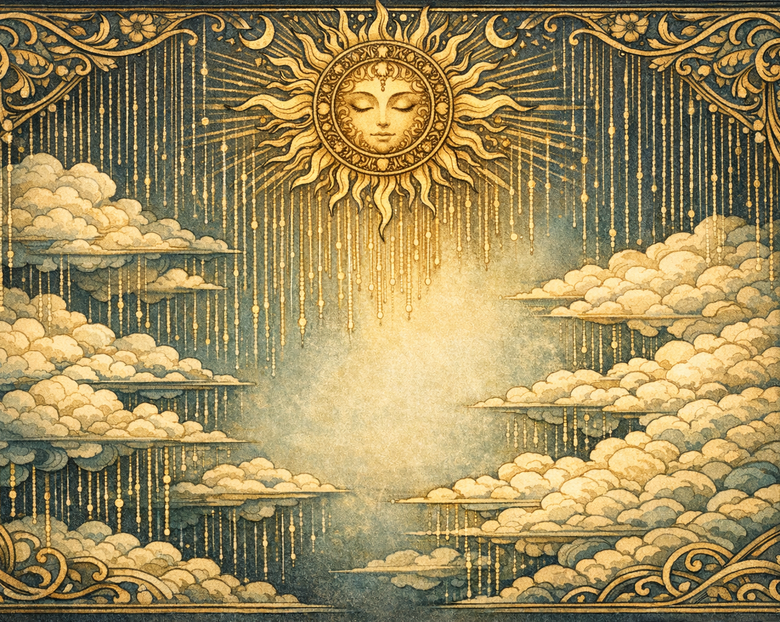
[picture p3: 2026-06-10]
Assets/Images/background_session_09.png

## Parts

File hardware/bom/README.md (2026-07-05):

# BOM Package

The rev-A hardware package now uses multiple BOM layers on purpose.

## Files

- `rev-a-core-priced-bom.csv`
  - common SMD active devices plus the external-DC / on-board-conversion power core
- `rev-a-preliminary-board-boms.md`
  - index for the per-board population/BOM starter files used during schematic capture
- `rev-a-board-priced-summary.md`
  - index and subtotal summary for board-by-board priced hard-part BOM companions
- `rev-a-control-backplane-priced-bom.csv`
  - priced hard-part companion for the optional / deferred control-backplane landing layer
- `rev-a-procurement-snapshot.md`
  - current exact-part sourcing snapshot with assembly-scope split and current vendor links
- `rev-a-common-passives-reference-bom.csv`
  - representative critical passive/device families with current pricing, aligned to the non-ceramic audio-path capacitor preference
- `rev-a-connectors-and-harness-reference-bom.csv`
  - internal board-to-board connector families and harness references
- `rev-a-panel-and-mechanical-reference-bom.csv`
  - combo jacks and panel/mechanical reference parts
- `rev-a-bom-notes.md`
  - explains what is locked and what still needs bench tuning
- `rev-a-common-smd-policy.md`
  - gives the builder-friendly passive substitution policy
- `rev-a-supply-watch.md`
  - approved alternates and the current common-parts sourcing direction
- `../rev-a-capacitor-policy.md`
  - documents the capacitor-avoidance preference and how to treat exceptions

## Why It Is Split

This project has three distinct procurement realities:

1. common SMD parts the board house can place
2. internal harness and connector parts
3. external mechanical parts and spring tanks

Splitting the BOM this way makes quoting cleaner and keeps the first prototype build realistic.

There are also two capture/quote-support layers:

4. board-level preliminary population files
5. board-level priced fixed-parts quote companions
6. current fixed-part procurement snapshot for builder/vendor use

Those files are there to keep the actual schematic capture organized.

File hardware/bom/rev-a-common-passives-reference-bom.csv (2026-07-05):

Category | Subsystem | Qty | Manufacturer | MPN | Description | UnitPrice | Currency | Supplier | ExtPrice | BuyURL | Notes
Precision Resistor | Balanced I/O | 16 | Vishay Dale | TNPW060310K0BEEA | 10k 0.1% 0603 thin-film resistor | 0.26 | USD | DigiKey | 4.16 | https://www.digikey.com/en/products/detail/vishay-dale/TNPW060310K0BEEA/1606881 | Reference precision ratio resistor for balanced receive/drive stages
Small Film Capacitor | Audio Compensation / RF | 20 | Panasonic Industry | ECH-U1H102JX5 | 1000 pF PPS film capacitor 0805 50V | 0.54 | USD | DigiKey | 10.80 | https://www.digikey.com/en/products/detail/panasonic-industry/ECH-U1H102JX5/353701 | Reference non-ceramic audio-path small-value cap family for compensation and RF shaping
Small Film Capacitor | Audio Timing / Filters | 20 | Panasonic Industry | ECH-U1H103JX5 | 10000 pF PPS film capacitor 1206 50V | 0.58 | USD | DigiKey | 11.60 | https://www.digikey.com/en/products/detail/panasonic-industry/ECH-U1H103JX5/353705 | Reference non-ceramic audio-path timing cap family for smaller filter values
Film Capacitor | Audio Coupling / General Audio | 20 | TDK | B32529C0105K000 | 1uF 63V polyester film capacitor radial | 0.65 | USD | DigiKey | 13.00 | https://www.digikey.com/en/products/detail/tdk/B32529C0105K000/1089750 | Reference non-electrolytic audio-path coupling family
Ceramic Capacitor | Power Decoupling | 40 | Murata Electronics | GRM188R72A104KA35D | 0.1uF 100V X7R 0603 capacitor | 0.15 | USD | DigiKey | 6.00 | https://www.digikey.com/en/products/detail/murata-electronics/GRM188R72A104KA35D/587143 | Reference power-rail decoupler family; allowed because the restriction applies to the audio path
Small Signal Diode | Filter/Clipper | 20 | Diodes Incorporated | 1N4148W-7-F | 100V 300mA SOD-123 switching diode | 0.17 | USD | DigiKey | 3.40 | https://www.digikey.com/en/products/detail/diodes-incorporated/1N4148W-7-F/814371 | Reference silicon clipping diode and general fast-signal diode
Indicator LED | Control | 8 | Lite-On Inc. | LTST-C190KRKT | Red 0603 LED | 0.15 | USD | DigiKey | 1.20 | https://www.digikey.com/en/products/detail/liteon/LTST-C190KRKT/386817 | Reference panel/board indication LED if needed

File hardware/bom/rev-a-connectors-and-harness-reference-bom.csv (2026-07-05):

Category | Subsystem | Qty | Manufacturer | MPN | Description | UnitPrice | Currency | Supplier | ExtPrice | BuyURL | Notes
Power Header 3P | Board Power | 5 | JST Sales America Inc. | B3P-VH-B | 3-position 3.96mm through-hole header | 0.23 | USD | DigiKey | 1.15 | https://www.digikey.com/en/products/detail/jst-sales-america-inc/B3P-VH-B/9924220 | Use on split-rail-only board power inputs
Power Housing 3P | Harness | 5 | JST Sales America Inc. | VHR-3N | 3-position 3.96mm housing | 0.10 | USD | DigiKey | 0.50 | https://www.digikey.com/en/products/detail/jst-sales-america-inc/VHR-3N/926611 | Reference mating housing for 3-position board power links
Power Header 4P | Board Power | 1 | JST Sales America Inc. | B4P-VH-B | 4-position 3.96mm through-hole header | 0.29 | USD | DigiKey | 0.29 | https://www.digikey.com/en/products/detail/jst-sales-america-inc/B4P-VH-B/9924221 | Use on the ext-routing board power input where +5VAUX is also required
Power Housing 4P | Harness | 1 | JST Sales America Inc. | VHR-4N | 4-position 3.96mm housing | 0.11 | USD | DigiKey | 0.11 | https://www.digikey.com/en/products/detail/jst-sales-america-inc/VHR-4N/926612 | Reference mating housing for the 4-position ext-routing power link
Power Crimp | Harness | 19 | JST Sales America Inc. | SVH-21T-P1.1 | VH crimp contact 18-22 AWG | 0.04132 | USD | DigiKey | 0.78508 | https://www.digikey.com/en/products/detail/jst-sales-america-inc/SVH-21T-P1-1/527368 | Current estimate for five 3-position and one 4-position VH harnesses
Signal Header 3P | Board Audio | 16 | JST Sales America Inc. | B3B-XH-A | 3-position 2.50mm through-hole header | 0.15 | USD | DigiKey | 2.40 | https://www.digikey.com/en/products/detail/jst-sales-america-inc/B3B-XH-A/1651046 | Use for 3-wire audio links and simple off-board control links
Signal Housing 3P | Harness | 10 | JST Sales America Inc. | XHP-3 | 3-position 2.50mm housing | 0.10 | USD | DigiKey | 1.00 | https://www.digikey.com/en/products/detail/jst-sales-america-inc/XHP-3/1651017 | Reference mating housing for audio harnesses H2 H3 H4 H7 H8 H9 H10 and simple control links
Signal Header 6P | Board Audio | 4 | JST Sales America Inc. | B6B-XH-A | 6-position 2.50mm through-hole header | 0.24 | USD | DigiKey | 0.96 | https://www.digikey.com/en/products/detail/jst-sales-america-inc/B6B-XH-A/1000381 | Use for bundled tank send/return links
Signal Housing 6P | Harness | 4 | JST Sales America Inc. | XHP-6 | 6-position 2.50mm housing | 0.10 | USD | DigiKey | 0.40 | https://www.digikey.com/en/products/detail/jst-sales-america-inc/XHP-6/1651016 | Reference mating housing for H5 and H6
Signal Header 8P | Board Control | 1 | JST Sales America Inc. | B8B-XH-A | 8-position 2.50mm through-hole header | 0.32 | USD | DigiKey | 0.32 | https://www.digikey.com/en/products/detail/jst-sales-america-inc/B8B-XH-A/1651024 | Keep as a reference only if a modest control bundle is still landed directly on one board
Signal Housing 8P | Harness | 1 | JST Sales America Inc. | XHP-8 | 8-position 2.50mm housing | 0.13 | USD | DigiKey | 0.13 | https://www.digikey.com/en/products/detail/jst-sales-america-inc/XHP-8/1651014 | Reference mating housing for that optional denser direct-control bundle
Signal Crimp | Harness | 78 | JST Sales America Inc. | SXH-001T-P0.6 | XH crimp contact | 0.04710 | USD | DigiKey | 3.6738 | https://www.digikey.com/en/products/detail/jst-sales-america-inc/SXH-001T-P0-6/26213115 | Current estimate for the rev-A audio harness set plus a few simple off-board control links

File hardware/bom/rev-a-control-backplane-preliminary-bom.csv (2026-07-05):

RefDes | Qty | MPN | Description | Notes
U601 | 1 | ULN2003ADR | 7-channel Darlington relay/driver array | Reserve only under the current rev-A harness; do not populate unless a later revision adds real coil-drive ownership to the backplane
P601 | 1 | B4P-VH-B | 4-position power header | Backplane power input
P610 | 1 | B9B-XH-A | 9-position control header | I/O controls group
P611 | 1 | B10B-XH-A | 10-position control header | Ext-routing controls group
P612 | 1 | B10B-XH-A | 10-position control header | Crossfade/feedback controls group
P613 | 1 | B12B-XH-A | 12-position control header | Filter/clipper controls group A
P614 | 1 | B12B-XH-A | 12-position control header | Filter/clipper controls group B
R* | 1 | set | Pull resistors and small-signal support parts | Use for mode-encoding, optional local endpoint generation, and future indicator options
C* | 1 | set | Power-only support capacitors | Local decoupling only; not in the audio path

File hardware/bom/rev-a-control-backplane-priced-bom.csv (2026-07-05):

Board | RefDes | Qty | Manufacturer | MPN | Description | UnitPrice | Currency | Supplier | ExtPrice | BuyURL | AssemblyScope | Notes
Control Backplane | P601 | 1 | JST Sales America Inc. | B4P-VH-B | 4-position 3.96mm through-hole header | 0.29 | USD | DigiKey | 0.29 | https://www.digikey.com/en/products/detail/jst-sales-america-inc/B4P-VH-B/9924221 | TH | Backplane power input
Control Backplane | P610 | 1 | JST Sales America Inc. | B9B-XH-A | 9-position 2.50mm through-hole header | 0.34 | USD | DigiKey | 0.34 | https://www.digikey.com/en/products/detail/jst-sales-america-inc/B9B-XH-A/1651042 | TH | I/O controls group; price from current DigiKey search/index snapshot
Control Backplane | P611-P612 | 2 | JST Sales America Inc. | B10B-XH-A | 10-position 2.50mm through-hole header | 0.39 | USD | DigiKey | 0.78 | https://www.digikey.com/en/products/detail/jst-sales-america-inc/B10B-XH-A/1651051 | TH | Ext-routing and crossfade/feedback grouped-control headers; price from current DigiKey search/index snapshot
Control Backplane | P613-P614 | 2 | JST | B12B-XH-AM(LF)(SN) | 12-position 2.50mm through-hole header | 0.1964 | USD | LCSC | 0.3928 | https://www.lcsc.com/product-detail/C594093.html | TH | Filter-control grouped headers; current visible LCSC price is MOQ-based and shown for 5+ pieces
Control Backplane | U601 | 1 | Texas Instruments | ULN2003ADR | 7-channel Darlington array, SOIC-16 | 0.91 | USD | DigiKey | 0.91 | https://www.digikey.com/en/products/detail/texas-instruments/ULN2003ADR/277011 | Reserve-DNP | Reserve-only under the current rev-A harness; do not populate unless a later revision gives the backplane real coil-drive ownership

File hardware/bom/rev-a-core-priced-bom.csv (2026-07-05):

Category | Board | Qty | Manufacturer | MPN | Description | UnitPrice | Currency | Supplier | ExtPrice | BuyURL | Notes
JFET/BiFET Input Op Amp | Input/Output | 1 | Texas Instruments | OPA1644AIDR | Quad JFET-input audio op amp, SOIC-14, +/-18V capable | 4.65 | USD | DigiKey | 4.65 | https://www.digikey.com/en/products/detail/texas-instruments/OPA1644AIDR/2353575 | Current rev-A choice for the JFET or BiFET preferred balanced input front-end; DigiKey still shows the part as not normally stocked | so `2x OPA1642AIDR` remains the approved immediate-order alternate
Op Amp | Output + Tank Driver/Recovery | 7 | Texas Instruments | OPA1656IDR | Dual audio op amp, SOIC-8, 36V total supply / +/-18V capable | 2.99 | USD | DigiKey | 20.93 | https://www.digikey.com/en/products/detail/texas-instruments/OPA1656IDR/10715414 | Core high-headroom audio device for line driver send recovery and output stages; rev-A now uses four channels for fully active stereo balanced output
Op Amp | Routing + Filter + Feedback | 4 | Texas Instruments | OPA1679IDR | Quad audio op amp, SOIC-14, 36V total supply / +/-18V capable | 1.52 | USD | DigiKey | 6.08 | https://www.digikey.com/en/products/detail/texas-instruments/OPA1679IDR/7034963 | Use for routing filter crossfade and feedback sections; current DigiKey status is backorderable so `OPA1664AIDR` is the preferred live alternate
Primary Send NPN | Tank Driver/Recovery | 2 | STMicroelectronics | BD139-16 | NPN transistor, 80V 1.5A, TO-126 | 1.44 | USD | DigiKey | 2.88 | https://www.digikey.com/en/products/detail/stmicroelectronics/BD139-16/2529325 | Current preferred direct-coupled primary tank driver transistor
Primary Send PNP | Tank Driver/Recovery | 2 | STMicroelectronics | BD140-16 | PNP transistor, 80V 1.5A, TO-126 | 1.57 | USD | DigiKey | 3.14 | https://www.digikey.com/en/products/detail/stmicroelectronics/BD140-16/3945995 | Complementary partner to BD139-16 for the preferred primary tank send stage
Signal Relay | Ext Tank Routing | 4 | Omron Electronics | G6K-2F-Y-DC5 | DPDT low-signal relay, SMD, 5V coil | 4.89 | USD | Mouser | 19.56 | https://www.mouser.com/ProductDetail/Omron-Electronics/G6K-2F-Y-DC5?qs=SXIVkn%252Bm38kNKs%252BIzeJTSg%3D%3D | SMD audio-path switching for Off/Series/Parallel routing
External Wall Adapter | Power | 1 | Triad Magnetics | WSU240-0750 | AC/DC wall adapter, +24 VDC single output, 750 mA, 18 W regulated SMPS, UL 62368-1, 5.5 x 2.1 mm center-positive barrel | 12.43 | USD | DigiKey | 12.43 | https://www.digikey.com/en/products/detail/triad-magnetics/WSU240-0750/3094933 | Selected `2026-07-04`; supersedes the unregulated Jameco DDU300050E9340 candidate and closes open issue 7; alternates: Tri-Mag L6R20-240 and Triad WSU240-1000
On-Board Isolated DC-DC | Power | 1 | Mornsun | URA2415YMD-10WR3 | Isolated DC-DC module, 9-36V in (24V nominal), +/-15V dual at 10W out | 9.27 | USD | DigiKey | 9.27 | https://www.digikey.com/en/products/detail/mornsun-america-llc/URA2415YMD-10WR3/13160913 | Generates +/-15VA from the +24V external adapter; URA dual-output variant per datasheet-cache correction; RECOM REC10-2415DZ/H1/A/M and XP JTD1024S15 are approved alternates per supply-watch
On-Board +5V Regulator | Power | 1 | RECOM | R-78E5.0-0.5 | Switching regulator module, 7-28V in, +5V/500mA out, 7805 pinout | 3.37 | USD | DigiKey | 3.37 | https://www.digikey.com/en/products/detail/recom-power/R-78E5-0-0-5/2834904 | Generates +5VAUX from +15VA; no heatsink required at this current
DC Input Jack | Power | 1 | Same Sky | PJ-005A | Panel-mount DC barrel jack, 5.5 mm OD / 2.1 mm ID, center positive | 3.07 | USD | DigiKey | 3.07 | https://www.digikey.com/en/products/detail/same-sky-formerly-cui-devices/PJ-005A/165838 | Service-endcap DC input matched to the Triad WSU240-0750 2.1 mm plug; same mounting hole and hardware as the prior PJ-005B
Optional Relay Driver | Control | 1 | Texas Instruments | ULN2003ADR | 7-channel Darlington array, SOIC-16 | 0.91 | USD | DigiKey | 0.91 | https://www.digikey.com/en/products/detail/texas-instruments/ULN2003ADR/277011 | Reserve-only part under the current frozen rev-A harness; do not populate unless a later revision moves real coil-drive ownership to the control backplane
Fallback Primary Driver | Tank Driver/Recovery | 2 | Texas Instruments | LM386MX-1/NOPB | Mono audio amplifier, SOIC-8, fallback single-supply primary tank send driver | 0.95 | USD | DigiKey | 1.90 | https://www.digikey.com/en/products/detail/texas-instruments/LM386MX-1-NOPB/212680 | Retained only as a fallback reference if the preferred direct-coupled stage proves impractical

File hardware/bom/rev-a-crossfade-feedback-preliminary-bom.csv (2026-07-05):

RefDes | Qty | MPN | Description | Notes
U301 | 1 | OPA1679IDR | Quad audio op amp | U301A/U301B crossfade summers, U301C/U301D feedback drivers
P301 | 1 | B3B-XH-A | 3-position signal header | Input from ext-routing board: TANK_MIX_L, AGND, TANK_MIX_R
P302 | 1 | B3B-XH-A | 3-position signal header | Output to filter/clipper board: XFADE_OUT_L, AGND, XFADE_OUT_R
P303 | 1 | B3B-XH-A | 3-position signal header | Return from filter/clipper board: FILTCLIP_OUT_L, AGND, FILTCLIP_OUT_R
P304 | 1 | B3B-XH-A | 3-position signal header | Direct wet return to I/O board: WET_SUM_L, AGND, WET_SUM_R
P305 | 1 | B3B-XH-A | 3-position signal header | Feedback reinjection output: FB_RET_L, AGND, FB_RET_R
P306 | 1 | B3P-VH-B | 3-position power header | Board power input: +15VA, AGND, -15VA
P307 | 1 | B10B-XH-A | 10-position grouped control header | Current rev-A grouped landing for crossfade, feedback amount, feedback phase invert, and AGND; may grow if raw passive feedback-pot wiring is expanded later
R301 | 1 | RC0603FR-0720KL | 20k 1% resistor, 0603 | Left crossfade entry: XFD_L_WIPER to U301A-
R302 | 1 | RC0603FR-0720KL | 20k 1% resistor, 0603 | Right crossfade entry: XFD_R_WIPER to U301B-
R309 | 1 | RC0603FR-0720KL | 20k 1% resistor, 0603 | Left crossfade unity-gain feedback
R310 | 1 | RC0603FR-0720KL | 20k 1% resistor, 0603 | Right crossfade unity-gain feedback
R311 | 1 | RC0603FR-07100RL | 100R 1% resistor, 0603 | Left filter-send isolator
R312 | 1 | RC0603FR-07100RL | 100R 1% resistor, 0603 | Right filter-send isolator
R321 | 1 | RC0603FR-0720KL | 20k 1% resistor, 0603 | Left feedback-driver input from FILTCLIP_OUT_L
R322 | 1 | RC0603FR-0720KL | 20k 1% resistor, 0603 | Right feedback-driver input from FILTCLIP_OUT_R
R323 | 1 | RC0603FR-0720KL | 20k 1% resistor, 0603 | Left feedback amount return-path start value; trim-friendly
R324 | 1 | RC0603FR-0720KL | 20k 1% resistor, 0603 | Right feedback amount return-path start value; trim-friendly
R325 | 1 | RC0603FR-0710KL | 10k 1% resistor, 0603 | Left minimum loop-floor feedback
R326 | 1 | RC0603FR-0710KL | 10k 1% resistor, 0603 | Right minimum loop-floor feedback
R331 | 1 | RC0603FR-07100RL | 100R 1% resistor, 0603 | Left feedback-send isolator after phase selection
R332 | 1 | RC0603FR-07100RL | 100R 1% resistor, 0603 | Right feedback-send isolator after phase selection
R341 | 1 | RC0603FR-07100RL | 100R 1% resistor, 0603 | Left final wet-return isolator
R342 | 1 | RC0603FR-07100RL | 100R 1% resistor, 0603 | Right final wet-return isolator
C321 | 1 | C0603C470J5GACTU | 47pF NP0 capacitor, 0603, DNP default | Left feedback-driver stability footprint
C322 | 1 | C0603C470J5GACTU | 47pF NP0 capacitor, 0603, DNP default | Right feedback-driver stability footprint
C391 | 1 | CC0603KRX7R9BB104 | 100nF X7R capacitor, 0603 | Local +15VA decoupling near U301 power unit
C392 | 1 | CC0603KRX7R9BB104 | 100nF X7R capacitor, 0603 | Local -15VA decoupling near U301 power unit
C393 | 1 | UWX1E100MCL1GB | 10uF 25V electrolytic or polymer support cap | Local positive-rail bulk footprint; power-path only
C394 | 1 | UWX1E100MCL1GB | 10uF 25V electrolytic or polymer support cap | Local negative-rail bulk footprint; power-path only

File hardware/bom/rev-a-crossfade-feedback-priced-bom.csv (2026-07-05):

Board | RefDes | Qty | Manufacturer | MPN | Description | UnitPrice | Currency | Supplier | ExtPrice | BuyURL | AssemblyScope | Notes
Crossfade/Feedback | U301 | 1 | Texas Instruments | OPA1679IDR | Quad audio op amp | 1.52 | USD | DigiKey | 1.52 | https://www.digikey.com/en/products/detail/texas-instruments/OPA1679IDR/7034963 | SMD | Crossfade feedback and wet handoff
Crossfade/Feedback | P301-P305 | 5 | JST Sales America Inc. | B3B-XH-A | 3-position 2.50mm through-hole header | 0.15 | USD | DigiKey | 0.75 | https://www.digikey.com/en/products/detail/jst-sales-america-inc/B3B-XH-A/1651046 | TH | Signal interconnect headers
Crossfade/Feedback | P306 | 1 | JST Sales America Inc. | B3P-VH-B | 3-position 3.96mm through-hole header | 0.23 | USD | DigiKey | 0.23 | https://www.digikey.com/en/products/detail/jst-sales-america-inc/B3P-VH-B/9924220 | TH | Board power input

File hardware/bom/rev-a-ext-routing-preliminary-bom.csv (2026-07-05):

RefDes | Qty | MPN | Description | Notes
U201 | 1 | OPA1679IDR | Quad audio op amp | Routing buffers, summing, makeup
U202 | 1 | OPA1656IDR | Dual audio op amp | Wet-input send summers; FB_RET reinjects pre-tank with WET_SEND
K201-K204 | 4 | G6K-2F-Y-DC5 | DPDT low-signal relay | Off/Series/Parallel routing
P201 | 1 | B3B-XH-A | 3-position signal header | Wet input
P202 | 1 | B6B-XH-A | 6-position signal header | Primary tank bundle
P203 | 1 | B6B-XH-A | 6-position signal header | Secondary tank bundle
P204 | 1 | B3B-XH-A | 3-position signal header | Routed output
P205 | 1 | B3B-XH-A | 3-position signal header | Feedback reinjection input (pre-tank, into U202 send summers)
P206 | 1 | TBD | Logical control landing or panel-backplane handoff | Ext amount plus mode-select wiring; freeze against rev-a-control-backplane-definition.md during capture
P207 | 1 | B4P-VH-B | 4-position power header | Board power input including +5VAUX
R* | 1 | set | Unity and summing resistors | 20k nominal starting point
C* | 1 | set | Stability and audio-path caps | Film-family preferred in audio path

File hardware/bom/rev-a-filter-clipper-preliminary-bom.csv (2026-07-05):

RefDes | Qty | MPN | Description | Notes
U401 | 1 | OPA1679IDR | Quad audio op amp | Pre-HPF and drive buffer channels
U402 | 1 | OPA1679IDR | Quad audio op amp | Post-LPF and output buffer channels
P401 | 1 | B3B-XH-A | 3-position signal header | Input from crossfade board
P402 | 1 | B3B-XH-A | 3-position signal header | Output to wet/feedback board
P403 | 1 | B12B-XH-A | 12-position control header group A | Drive and HPF control landing; pairs naturally with backplane P613
P404 | 1 | B3P-VH-B | 3-position power header | Board power input
P405 | 1 | B12B-XH-A | 12-position control header group B | LPF and clip-mode control landing; pairs naturally with backplane P614
D401-D4xx | 1 | set | Clip diodes and LEDs | Silicon, LED, and germanium options
R* | 1 | set | Filter and gain resistors | Final values to be tuned against listening tests
C* | 1 | set | Filter timing capacitors | Prefer film-family parts in audio path

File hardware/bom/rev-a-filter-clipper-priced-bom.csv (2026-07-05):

Board | RefDes | Qty | Manufacturer | MPN | Description | UnitPrice | Currency | Supplier | ExtPrice | BuyURL | AssemblyScope | Notes
Filter/Clipper | U401-U402 | 2 | Texas Instruments | OPA1679IDR | Quad audio op amp | 1.52 | USD | DigiKey | 3.04 | https://www.digikey.com/en/products/detail/texas-instruments/OPA1679IDR/7034963 | SMD | HPF drive clipping LPF and output buffers
Filter/Clipper | P401-P402 | 2 | JST Sales America Inc. | B3B-XH-A | 3-position 2.50mm through-hole header | 0.15 | USD | DigiKey | 0.30 | https://www.digikey.com/en/products/detail/jst-sales-america-inc/B3B-XH-A/1651046 | TH | Signal input and output
Filter/Clipper | P404 | 1 | JST Sales America Inc. | B3P-VH-B | 3-position 3.96mm through-hole header | 0.23 | USD | DigiKey | 0.23 | https://www.digikey.com/en/products/detail/jst-sales-america-inc/B3P-VH-B/9924220 | TH | Board power input

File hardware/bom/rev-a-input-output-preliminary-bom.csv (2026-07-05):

RefDes | Qty | MPN | Description | Notes
U1 | 1 | OPA1644AIDR | Quad JFET/BiFET-input audio op amp | Balanced receiver and mono-to-stereo utility stages
U2 | 1 | OPA1656IDR | Dual audio op amp | Wet/dry mixer left and right
U3 | 1 | OPA1656IDR | Dual audio op amp | Balanced output driver left hot/cold
U4 | 1 | OPA1656IDR | Dual audio op amp | Balanced output driver right hot/cold
J1 | 1 | NCJ6FI-S | Combo XLR/TRS jack | Left input
J2 | 1 | NCJ6FI-S | Combo XLR/TRS jack | Right input
J3 | 1 | NCJ6FI-S | Combo XLR/TRS jack | Left output
J4 | 1 | NCJ6FI-S | Combo XLR/TRS jack | Right output
P1 | 1 | B3P-VH-B | 3-position power header | Board power input
P2 | 1 | B3B-XH-A | 3-position signal header | Wet send
P3 | 1 | B3B-XH-A | 3-position signal header | Wet return
P4 | 1 | B3B-XH-A | 3-position signal header | Dry distribution
P5 | 1 | B6B-XH-A | 6-position header | Wet/Dry dual-gang control if the pot is off-board
P6 | 1 | B3B-XH-A | 3-position header | Mono->Stereo switch if the switch is off-board
R* | 1 | set | 0.1% ratio resistors | Balanced input and output resistor networks
C* | 1 | set | Audio-path capacitor set | Prefer direct coupling or film-family parts in signal path

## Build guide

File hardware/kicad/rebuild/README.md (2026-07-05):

# Rev A Clean Rebuild — Tank Driver / Recovery Board

Branch: `rev-a-clean-rebuild`. Board 1 of 6, taken end-to-end first per plan.

## What exists now

| Artifact | Status |
| --- | --- |
| `../tank-driver-recovery.kicad_sch` | Full electrical capture, 97 components, **ERC = 0** |
| `../sim/tank-driver-recovery-sim/` | Simulation testbench project, **ERC = 0**, **runs in ngspice with no errors** |
| `../tank-driver-recovery.kicad_pcb` | Netlist-synced board, 90 footprints placed by stage, outline + M3 holes + AGND pours, **DRC errors = 0** (13 silk warnings), routing not yet done |
| `gen_tdr.py` | Generates both schematics from one circuit definition — edit this, not the .kicad_sch |
| `gen_tdr_pcb.py` | Generates the board placement from the same circuit definition |
| `run_sim.py` | Runs the testbench through KiCad's bundled ngspice.dll and sanity-checks levels |

## Verified simulation results (0.5 Vpk 1 kHz drive, ±15 V rails)

- Primary send: unity gain, 0.52 Vpk into the 8R tank model (~65 mA pk), op-amp
  pre-driver swings ±1.16 V to correct the class-B follower dead zone in-loop
- Primary recovery: 20 mV tank return -> 0.69 Vpk out (gain 34)
- Secondary send: gain 2.2 into the 800R tank model; recovery -> 0.86 Vpk
- Left/right channels identical; no convergence errors over 60 ms

## Engineering decisions made during capture (vs. the written spec)

1. **Feedback point**: R108/R128 feedback is taken from `PRI_OUT_L/R`
   (after the BD139/BD140 followers) instead of the op-amp output pin. With
   the bias diodes DNP per spec, the followers would otherwise run open-loop
   class-B with gross crossover distortion. In-loop feedback is the standard
   fix and simulation confirms clean output. D101/D102/D121/D122 stay as DNP
   bias-spreader reserves exactly as specced.
2. **Tank cable landings** (`J101-J108`): spec defers RCA vs shielded-wire.
   Chosen: JST XH 2-pin board landings (stock footprint, cheap, crimp
   harness to the tanks' RCA plugs). Swappable later without net changes.
3. **Recovery input coupling**: direct-coupled by default via 0R jumpers
   R183-R186, with DNP film caps C175-C178 in parallel positions, so the
   bench choice in the spec stays a solder-jumper choice.
4. **Decoupling**: C299 + C300 bulk (one per rail) — spec reserved only
   C291-C299 but intent lists two bulk parts.

## Tank models

`sim/tank-driver-recovery-sim/tanks.lib` models what the electronics see:
input coil L+R load, band-limited coupling (~80 Hz-4 kHz) with realistic
insertion loss, output coil source impedance. Spring delay/reverb tail is
intentionally NOT modeled — that is what the real tanks are for.

## How to run the simulation in KiCad

1. Open `hardware/kicad/sim/tank-driver-recovery-sim/tank-driver-recovery-sim.kicad_pro`
2. Inspect -> Simulator -> Run (the `.tran 20u 60m` directive is on the sheet)
3. Probe `PRI_OUT_L`, `PRI_RET_L`, `SEC_RET_L`, etc. For frequency response,
   comment `.tran` and uncomment `.ac dec 50 10 100k` on the sheet text.

## Still to do (after review sign-off)

- Route the board (power first, then signals), refill zones, DRC to zero
  including connectivity, then Gerber/drill/BOM/position exports
- Replicate this workflow for the other five boards
- Order: fab/assembly quote packet per `hardware/rev-a-manufacturing.md`

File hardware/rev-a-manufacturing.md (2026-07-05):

# GAS Rev A Manufacturing Handoff

This file records where to send the finished design files once the KiCad project is complete.

Current vendor guidance in this file was rechecked on `2026-06-29`.

The current exact-part sourcing snapshot for the frozen rev-A fixed parts lives in:

- [bom/rev-a-procurement-snapshot.md](C:/Users/Jason/GAS-build/repo/hardware/bom/rev-a-procurement-snapshot.md:1)

Current package status:

- board architecture, connector schedule, harness/endcap assumptions, and schematic-ready definitions are in place
- the KiCad project is still an intermediate capture, not a final fabrication release
- top-level ERC was rerun on `2026-06-29` and currently reports `650` known intermediate violations dominated by unconnected sheet pins and placeholder child-sheet wiring on the non-power audio/control pages
- the latest I/O-board cleanup pass removed the accidental center-short stubs in the first-pass receiver / blend / output-driver capture and reduced that child sheet from `404` to `376` local violations

## Recommended Build Path

### Best Prototype Path

1. Use `KiCad 10` for schematic capture and PCB layout
2. Send SMT-heavy analog boards for fabrication/assembly
3. Hand-install or consigned-install the bulky mechanical parts:
   - spring tanks
   - any user-supplied vacuum tubes
   - combo `XLR / TRS` panel jacks
   - panel switches
   - panel potentiometers
   - service-endcap DC barrel jack
   - user-supplied enclosure tube

Note: rev A no longer carries any mains-side circuitry. The internal `Mean Well RT-50C` AC/DC module is gone; DC arrives via an external `+24VDC` wall-adapter strategy and is converted to `+/-15V / +5V` on the power-backplane PCB by an isolated DC-DC + small +5V switching regulator. The adapter is the regulated `Triad WSU240-0750` (`+24 VDC / 750 mA / 18 W`, UL 62368-1, selected `2026-07-04`), which retired the earlier unverified Jameco candidate. See [rev-a-external-dc-power.md](rev-a-external-dc-power.md). This eliminates the IEC inlet, fuse holder, mains creepage rules, and the chassis-bond safety-test step that earlier revisions of this document called out.
4. Perform bench tuning on the tank send/recovery and filter sections
5. Only then freeze the production BOM

### Where To Send The Files

#### JLCPCB

Best fit:

- fast prototype PCB fab
- SMT assembly for the op-amp / relay / passive-heavy boards

Current JLCPCB assembly handoff guidance says to provide:

- `Gerber`
- `BOM`
- `CPL / centroid / positions`

Relevant current source:

- [JLCPCB KiCad BOM/CPL guide](https://jlcpcb.com/help/article/how-to-generate-the-bom-and-centroid-file-from-kicad)
- [JLCPCB BOM requirements](https://jlcpcb.com/help/article/bill-of-materials-for-pcb-assembly)

Recommendation:

- Use JLCPCB for the first board spins
- Treat the service endcap hardware and the user-supplied tube as separate mechanical work

#### PCBWay

Best fit:

- PCB fab plus broader assembly support
- more realistic option when through-hole and odd mechanical parts begin to matter

Current PCBWay assembly guidance says to provide:

- `Gerber` files
- `Centroid` / pick-and-place file
- `BOM`

Relevant current source:

- [PCBWay assembly file requirements](https://www.pcbway.com/assembly-file-requirements.html)

Recommendation:

- Use PCBWay when the design moves past bare/SMT prototype boards and you want more help with mixed-technology assembly

#### MacroFab

Best fit:

- low-volume turnkey manufacturing
- U.S.-friendly handoff
- better candidate for a semi-turnkey production build once the design is stable

Current MacroFab guidance says it accepts:

- native project files
- `Gerber` / `ODB++`
- `BOM`

Relevant current source:

- [MacroFab required design files](https://support.macrofab.com/s/article/macrofab-required-design-files)
- [MacroFab platform overview](https://www.macrofab.com/platform/)

Recommendation:

- If the goal is "I want a company to own more of the sourcing and assembly workflow", MacroFab is the strongest final-build target from the options researched in this session

#### Endcap / Mechanical Vendors

Best fit:

- `Front Panel Express` for engraved or printed circular endcap artwork
- `SendCutSend` for simple cut/drill circular plates and internal brackets
- `Protocase` for a more turnkey custom-mechanical package when the project is ready to hand a vendor the endcaps, brackets, and internal mounting hardware together

Relevant current sources:

- [Front Panel Express](https://www.frontpanelexpress.com/)
- [SendCutSend custom metal parts](https://sendcutsend.com/)
- [Protocase custom enclosures](https://www.protocase.com/)

Recommendation:

- For rev-A prototype work, keep the user-supplied tube outside the vendor quote and send only the circular endcaps, reinforcement plates, and brackets to the mechanical vendor
- If later revisions need a more turnkey enclosure package, `Protocase` is the best fit from the researched vendors. This is an inference from its custom-enclosure service model, not a claim that it has a stock cylindrical product

## Files To Generate From KiCad

When the KiCad project is ready, generate:

- schematic PDF set
- fabrication `Gerbers`
- drill files
- IPC netlist or design archive
- assembly `BOM.csv`
- pick-and-place / `positions.csv`
- board stackup note
- assembly drawings
- test notes and calibration notes

For rev A, also include:

- [rev-a-schematic-packets.md](C:/Users/Jason/GAS-build/repo/hardware/rev-a-schematic-packets.md:1)
- [rev-a-interconnect-pin-map.md](C:/Users/Jason/GAS-build/repo/hardware/rev-a-interconnect-pin-map.md:1)
- [rev-a-board-package-freeze.md](C:/Users/Jason/GAS-build/repo/hardware/rev-a-board-package-freeze.md:1)
- [rev-a-board-connector-schedule.csv](C:/Users/Jason/GAS-build/repo/hardware/rev-a-board-connector-schedule.csv:1)
- [rev-a-bringup-sequence.md](C:/Users/Jason/GAS-build/repo/hardware/rev-a-bringup-sequence.md:1)
- [rev-a-endcap-hole-table.md](C:/Users/Jason/GAS-build/repo/hardware/rev-a-endcap-hole-table.md:1)
- [rev-a-endcap-hole-table.csv](C:/Users/Jason/GAS-build/repo/hardware/rev-a-endcap-hole-table.csv:1)
- [rev-a-board-outline-assumptions.md](C:/Users/Jason/GAS-build/repo/hardware/rev-a-board-outline-assumptions.md:1)
- [rev-a-board-outline-assumptions.csv](C:/Users/Jason/GAS-build/repo/hardware/rev-a-board-outline-assumptions.csv:1)
- [rev-a-harness-cut-lengths.md](C:/Users/Jason/GAS-build/repo/hardware/rev-a-harness-cut-lengths.md:1)
- [rev-a-harness-cut-lengths.csv](C:/Users/Jason/GAS-build/repo/hardware/rev-a-harness-cut-lengths.csv:1)

Supporting manufacturing references already in the repo:

- [rev-a-pcb-fabrication-assumptions.md](C:/Users/Jason/GAS-build/repo/hardware/rev-a-pcb-fabrication-assumptions.md:1)
- [bom/rev-a-cost-summary.md](C:/Users/Jason/GAS-build/repo/hardware/bom/rev-a-cost-summary.md:1)
- [bom/rev-a-board-priced-summary.md](C:/Users/Jason/GAS-build/repo/hardware/bom/rev-a-board-priced-summary.md:1)
- [bom/rev-a-procurement-snapshot.md](C:/Users/Jason/GAS-build/repo/hardware/bom/rev-a-procurement-snapshot.md:1)

For the mechanical vendor, also include:

- circular service-endcap drill schedule
- preferred board-outline/rail assumptions
- harness cut-length assumptions so the shop understands why the service end needs accessible routing space

## Recommended Quote Package Split

For rev A, the cleanest handoff is to treat the build as three BOM layers:

1. `SMD core BOM`
   - active ICs
   - relays
   - critical passives
   - board-mount support parts
2. `Connector / internal harness BOM`
   - JST board headers
   - mating housings
   - crimp contacts
3. `Mechanical / consigned BOM`
   - spring tanks
   - combo `XLR / TRS` jacks
   - service-endcap DC jack
   - panel switches
   - panel potentiometers
   - endcap plates and reinforcement hardware
   - user-supplied enclosure tube

This keeps the SMT assembly quote realistic while still preserving a complete manufacturing package.

## Parts That Should Usually Be Consigned Or Purchased Separately

- the four spring tanks
- any user-supplied vacuum tubes
- tank RCA cabling
- user-supplied enclosure tube
- any custom faceplate or screened panel

## Preferred Sourcing Pattern

The latest project direction is:

- let the PCB build company place the common SMD parts
- keep the design centered on widely available analog ICs, relays, and passives
- treat tanks and enclosure hardware separately from the SMD assembly quote

The current approved alternates and supply-risk notes live in:

- [bom/rev-a-supply-watch.md](C:/Users/Jason/GAS-build/repo/hardware/bom/rev-a-supply-watch.md:1)

For the common SMD semiconductors and support parts, the best mainstream sources found during this session were:

- [DigiKey](https://www.digikey.com/)
- [Mouser](https://www.mouser.com/)

Use these as the reference market for:

- TI op-amps
- ST BD139 / BD140 primary send transistors
- LM386 driver ICs if the fallback path is ever needed
- Omron relays
- low-voltage conversion parts and the service-endcap DC jack

Panel hardware, tanks, endcaps, and the enclosure tube can stay outside the SMD house BOM until the mechanical package is frozen.

If this build uses tubes, keep them consigned as well. The current rev-A fixed PCB package does not yet carry frozen tube SKUs, so the assembler should not source tubes from the main BOM.

The spring tanks are explicitly separate-purchase items and should stay outside the SMD assembly quote.

The external balanced I/O format is now fixed:

- combo `XLR / TRS` jacks for input and output

One practical note from Neutrik's combo-jack family documentation:

- the standard combo receptacle family is positioned as an XLR receptacle plus 1/4-inch jack solution commonly used for balanced mic or line inputs

Because the project requirement is combo jacks for both input and output, rev A should keep the combo format but sanity-check the female-XLR output convention before the chassis metalwork is frozen.

## Practical Recommendation

For the first real hardware pass:

- send the SMT board files to JLCPCB or PCBWay
- keep the BOM centered on common SMD parts
- let the builder quote the common passives directly from its house supply chain
- use MacroFab only after the first tuned prototype proves the circuits and connector strategy

## Best Current Recommendation

As of `2026-06-29`:

- `JLCPCB` is still the cleanest first stop for bare-board plus common-SMD prototype spins
- `PCBWay` is the better next step if the build starts leaning harder on mixed through-hole, odd connectors, or more hands-on assembly support
- `MacroFab` is the best handoff target if you want a U.S.-based company to absorb more of the sourcing and assembly workflow once the analog design is proven

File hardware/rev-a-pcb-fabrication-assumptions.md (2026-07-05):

# GAS Rev A PCB Fabrication Assumptions

This file records the first-pass PCB fabrication assumptions for the analog hardware package.

## Default Board Style

Rev A should begin with conventional rigid FR-4 boards.

Preferred defaults:

- layer count: `2-layer`
- thickness: `1.6 mm`
- outer copper: `1 oz`
- surface finish: `ENIG`
- solder mask: green unless branding needs something else later
- silkscreen: white

Reason:

- these defaults are easy for prototype fabs
- the analog density does not currently demand more than 2 layers
- ENIG is friendly for mixed SMD / through-hole and repeat rework

## Manufacturer Capability References

The current assumptions are intentionally aligned to easy, standard offerings from the prototype vendors already referenced in the package.

### JLCPCB

Relevant capability references:

- [PCB capabilities](https://jlcpcb.com/capabilities/pcb-capabilities)
- [Copper weight guide](https://jlcpcb.com/help/article/jlcpcb-copper-weight)
- [How to choose board thickness](https://jlcpcb.com/blog/how-to-choose-the-thickness-of-pcb)

Useful current points from those sources:

- 2-layer FR-4 is standard
- 1 oz and 2 oz outer copper are standard options
- 1.6 mm is a normal board thickness choice

### PCBWay

Relevant capability references:

- [PCB capabilities](https://www.pcbway.com/capabilities.html)
- [Manufacturing tolerances](https://www.pcbway.com/pcb_prototype/PCB_Manufacturing_tolerances.html)

Useful current points from those sources:

- minimum manufacturable trace/spacing is `4/4 mil`
- they strongly suggest `6/6 mil` or wider to save cost
- minimum drill sizes go down below what this project should need

## Rev A Design Rules To Target

For quote-friendly prototype boards:

- nominal trace/space target: `6/6 mil`
- minimum drill target: `0.3 mm`
- through-hole parts are acceptable where they materially help:
  - combo jacks
  - JST headers
  - TO-126 transistors
  - film capacitors in the audio path

## Board-Specific Notes

### Input / Output Board

- likely mixed-technology board because of combo jacks and possible film audio capacitors
- keep balanced I/O traces symmetrical near the panel connectors

### Tank Driver / Recovery Board

- likely mixed-technology board
- TO-126 output transistors and film audio-path parts may push board area up
- treat this board as the least likely to stay compact

### Ext Tank Routing Board

- mostly friendly to SMD assembly
- relay keepouts and coil-current routing matter more than density

### Crossfade / Feedback / Wet Board

- should be one of the easiest boards to keep compact and SMD-heavy

### Filter / Clipper Board

- may become mixed-technology if the chosen audio-path capacitor policy drives film-capacitor footprints into the filter sections

## When To Revisit The Layer Count

Stay at 2 layers unless one of these becomes true:

- grounding around the tank recovery stage becomes too compromised
- the filter / clipper board becomes too dense to route cleanly
- relay routing plus analog return paths become messy enough to justify extra planes

If that happens, the best upgrade path is:

- move the problem board only to `4-layer`
- keep the simpler boards at `2-layer`

## Practical Rev A Recommendation

Start all boards assuming:

- `2-layer`
- `1.6 mm`
- `1 oz`
- `ENIG`
- `6/6 mil`
- `0.3 mm` drill or larger

Only promote an individual board to `4-layer` if the actual KiCad routing proves it needs it.

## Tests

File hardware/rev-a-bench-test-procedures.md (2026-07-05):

# GAS Rev A Bench Test Procedures

Concrete bench procedures for each board, run in the order given in [rev-a-bringup-sequence.md](rev-a-bringup-sequence.md). The validation checklist in [rev-a-validation-checklist.md](rev-a-validation-checklist.md) covers what to confirm; this file covers how to confirm it, with specific signals, equipment, and pass/fail numbers tied to [rev-a-numeric-targets.md](rev-a-numeric-targets.md).

## Required bench equipment

- Bench DMM with 10 mV resolution and a 100 mA range
- Dual-channel oscilloscope, 50 MHz bandwidth or better, with two 10x probes
- Audio signal generator capable of balanced output, or a USB audio interface with a balanced line out
- Audio analyzer or USB interface plus FFT software (REW, ARTA, or equivalent) for THD+N and frequency response
- Dummy load: two `600 ohm 1 W` non-inductive resistors plus two `10 kohm 1/4 W` resistors
- Bench power supply rated at least `+/-20 V` at 250 mA for pre-installation rail injection
- Two pairs of audio cables: balanced XLR/TRS, plus internal harness adapters per [rev-a-interconnect-pin-map.md](rev-a-interconnect-pin-map.md)
- Bench DMM probe or breakout for the external `+24 VDC` wall adapter plug

## Reference signal definitions

- `REF-DBU-0`: balanced sine, `1 kHz`, `0 dBu` (`0.775 Vrms` differential)
- `REF-DBU+4`: balanced sine, `1 kHz`, `+4 dBu` (`1.228 Vrms` differential)
- `REF-DBU+18`: balanced sine, `1 kHz`, `+18 dBu` (`6.16 Vrms` differential, headroom check)
- `REF-SWEEP`: balanced log sweep `20 Hz` to `20 kHz`, `+4 dBu`
- `REF-IMPULSE`: balanced single-cycle `1 kHz` burst for tank excitation

## P-0  Power Backplane (before any audio board is connected)

Equipment: DMM, scope.

1. Verify the wall adapter is the intended `Triad WSU240-0750` `+24 VDC` model (open-circuit `+22.8 V` to `+25.2 V`, reject above `+27 V`) and that the barrel polarity matches the service-endcap jack before any board is connected.
2. Apply the wall adapter with all downstream board connectors unmated.
2. Measure each rail at the backplane test points:
   - `+15VA` to `AGND`: `+14.85 V` to `+15.30 V`, ripple under `5 mVpp` at 100 kHz scope bandwidth
   - `-15VA` to `AGND`: `-14.85 V` to `-15.30 V`, ripple under `5 mVpp`
   - `+5VAUX` to `DGND`: `+4.90 V` to `+5.20 V`, ripple under `20 mVpp`
3. Scope `AGND` to chassis at the star-ground point. Low-frequency component under `2 mVpp`.
4. Load each rail to its rev-A budgeted draw from [rev-a-power-budget.md](rev-a-power-budget.md) using bench resistors. Rails must hold within the limits above and the DC-DC plus `+5V` regulator stack must not enter thermal foldback within 5 minutes.

Pass condition: all three rails within tolerance under loaded and unloaded conditions, no oscillation on the scope, no thermal warning from the conversion modules.

## P-1  Input / Output Board

Equipment: balanced generator, DMM, scope, audio analyzer, 600 ohm load.

Setup: connect the board through its own power harness from P-0. Leave all downstream audio connectors floating. Connect a balanced load (`600 ohm` in parallel with a `10 kohm` voltmeter tap) to each output jack.

1. Quiescent check
   - Measure DC at each balanced receiver output pin. Target within `+/-5 mV` of `AGND`.
   - Measure DC at each balanced driver output pin. Target within `+/-15 mV` of `AGND`.
2. Balanced receiver gain
   - Apply `REF-DBU+4` to the left input. Measure the post-receiver test point.
   - Expected internal level matches the rev-A internal nominal in [rev-a-numeric-targets.md](rev-a-numeric-targets.md) within `+/-0.3 dB`.
3. Mono-to-stereo switch
   - Apply `REF-DBU+4` to the left input only, right input shorted.
   - Toggle `STEREO/MONO`. In `MONO`, the right internal channel must match the left within `0.3 dB` and remain phase-coherent on the scope.
4. Headroom
   - Apply `REF-DBU+18`. THD+N at the post-receiver test point under `0.05 percent` measured at `20 Hz - 20 kHz`.
5. Wet / dry control behavior
   - Sweep the `WET/DRY` pot through its full travel with `REF-DBU+4` applied. Output at the balanced driver must transition monotonically with no zipper noise audible on a powered monitor through the analyzer return.
6. Balanced driver into load
   - Drive `REF-DBU+4` through with `WET/DRY` at fully dry. Output across `600 ohm` must be `+4 dBu +/- 0.5 dB`.
   - Drive `REF-DBU+18` through. Output must remain undistorted (THD+N under `0.1 percent`) and the rails must not sag more than `100 mV`.
7. Frequency response
   - Run `REF-SWEEP`. Response must be flat within `+/- 0.5 dB` from `20 Hz` to `20 kHz` on the dry path.

Pass condition: all six checks within bounds with no audible artifacts on the monitor.

## P-2  Tank Driver / Recovery Board

Equipment: scope, balanced generator, current-limited bench supply for safety.

Setup: connect the board to P-0. Connect the recovery side to a temporary 10 kohm load while the primary tanks are not yet wired in.

1. Quiescent driver bias
   - Measure DC at each `BD139` / `BD140` emitter junction. Should sit within `+/-30 mV` of `AGND`.
   - Measure each transistor's emitter-resistor voltage. Idle current should match the rev-A bias point in [rev-a-circuit-starting-points.md](rev-a-circuit-starting-points.md) within `+/-20 percent`.
2. Send drive level
   - Apply `REF-DBU+4` at the wet send. Verify the driver output across a `10 ohm` dummy tank-input resistor matches the rev-A send-drive target in [rev-a-numeric-targets.md](rev-a-numeric-targets.md) within `+/-1 dB`.
3. Recovery gain
   - Inject a `5 mVrms` `1 kHz` sine into the recovery input through a `10 kohm` series resistor to simulate tank source impedance. Verify recovery output level matches the rev-A recovery gain within `+/-0.5 dB`.
4. Real tank substitution
   - With the bench rails off, install the primary `4AB1C1B` tanks per [rev-a-harness-map.md](rev-a-harness-map.md). Re-energize.
   - Apply `REF-IMPULSE`. The recovery output must show a decaying spring response longer than `1.5 s` on the scope before the next burst.
5. Secondary tank check
   - Repeat step 4 with `9EB2C1B` (left) and `9EB3C1B` (right). Decay should be audibly distinct from the primaries when monitored through P-1.

Pass condition: bias stable, send and recovery levels in range, tanks audibly excited and decaying without oscillation or hum higher than `-70 dBu` at the recovery output.

## P-3  Ext Tank Routing Board

Equipment: signal generator, audio analyzer, scope.

0. Relay receiving check (at parts arrival, review W2 / pre-order double-check item 7)
   - Before installing any relay, measure each `G5V-2` coil resistance with the DMM and record it.
   - DC5 coils (`K201-K204` here): confirm which coil-current variant arrived (30 vs 40 mA class) and that the `+5VAUX` relay allowance in [rev-a-power-budget.md](rev-a-power-budget.md) still holds for 7 coils worst-case.
   - DC12 coil (`K301`, crossfade board): if the coil measures as the `720R` variant, change `R351` from `240R` to `150R` before assembly, per the pre-order double-check.
   - Also bench-confirm NC/NO orientation on one relay before final panel labeling (symbol-orientation risk noted in review W2).

1. Quiescent off state
   - Set the `MODE` rotary to `Off`. Apply `REF-DBU+4` at the wet input. Measure the secondary send output: should be at the analyzer noise floor (under `-80 dBu`).
2. Series mode
   - Set to `Series`. The wet path must pass through the secondary tanks. Verify with `REF-IMPULSE` that the recovery output shows both primary and secondary decay characteristics summed.
3. Parallel mode
   - Set to `Parallel`. The secondary send must be present at the analyzer noise floor while the wet path is also present at the bypass. Confirm the `EXT AMOUNT` pot scales the secondary-tank contribution monotonically from `-inf` to the rev-A maximum in [rev-a-control-ranges-and-laws.md](rev-a-control-ranges-and-laws.md).
4. Relay switching transient
   - With `REF-DBU+4` applied, switch `MODE` between all three positions repeatedly. Scope the wet bypass output. Switching transients must stay below `30 mVpp` at the post-routing output.
5. Crosstalk
   - Apply signal to left only with `MODE` in `Parallel`. Right channel post-routing must show crosstalk under `-70 dB` at `1 kHz`.

Pass condition: all three modes behave per truth table in [rev-a-mode-truth-tables.md](rev-a-mode-truth-tables.md), switching transients within bounds, crosstalk under spec.

## P-4  Filter / Clipper Board

Equipment: signal generator, audio analyzer, scope.

1. Drive stage linearity
   - With `DRIVE` at minimum, apply `REF-DBU+4`. THD+N at the post-drive test point under `0.05 percent`.
   - With `DRIVE` at maximum, expect intentional harmonic content; verify the scope shows the selected `CLIP MODE` waveform shape.
2. HPF sweep
   - Set `CLIP MODE` to clean. Sweep `HPF CUTOFF` across full travel with `REF-SWEEP`. The `-3 dB` point must traverse the rev-A HPF range in [rev-a-numeric-targets.md](rev-a-numeric-targets.md) within `+/- 10 percent`.
   - Sweep `HPF Q` and verify peak amplitude tracks per rev-A control law without self-oscillation at maximum Q.
3. LPF sweep
   - Repeat step 2 with `LPF CUTOFF` and `LPF Q`.
4. Clip mode encoding
   - Step `CLIP MODE` through all four positions with `DRIVE` at maximum and `REF-DBU+4` applied. Each position must produce a visibly distinct scope waveform consistent with the curated mode set in [rev-a-mode-truth-tables.md](rev-a-mode-truth-tables.md).
5. Output level
   - With `DRIVE` minimum, `CLIP MODE` clean, both filters wide open, output level at the filter board send must match input level within `+/- 0.5 dB`.

Pass condition: filter ranges within `+/- 10 percent`, clip modes audibly distinct, drive stage clean at minimum.

## P-5  Crossfade / Feedback / Mixer Board

Equipment: signal generator, audio analyzer, scope.

1. Crossfade law
   - Inject distinct signals into the left and right wet inputs (`1 kHz` left, `1.1 kHz` right). Sweep `CROSSFADE` from full-left to full-right. Each endpoint must show greater than `40 dB` of opposite-channel rejection at the mixer output.
   - Center position must show both channels within `+/-1 dB` of each other.
2. Feedback phase invert
   - Apply `REF-DBU+4` to wet input with `FEEDBACK` near zero. Toggle `FB PHASE`. The mixer output at `1 kHz` must invert polarity cleanly with no level change greater than `0.3 dB`.
3. Feedback stability
   - Slowly raise `FEEDBACK` with `MODE` in `Off` and the filter passing signal. Verify the rev-A feedback maximum stays below self-oscillation when `FILTER` is set to its rev-A nominal narrow band. Document the position where oscillation onsets with the real tanks installed.
4. Feedback loop-sense labeling check (added `2026-07-04`, review finding W6)
   - The `2026-07-04` ext-routing re-spin moved feedback reinjection pre-tank through inverting send summers (`U202`), which changes the net loop sign versus the earlier topology. With the real tanks installed, raise `FEEDBACK` moderately in each `FB PHASE` position and identify which position gives regenerative build-up (blooming decay) versus damping. If the behavior is swapped relative to the panel legend, swap the panel labeling (function is unaffected; the selector covers both senses).
5. Mixer summing
   - Apply matched `REF-DBU+4` to all summing inputs in turn. Total mixer output must scale per rev-A gain plan in [rev-a-capture-value-tables.md](rev-a-capture-value-tables.md).

Pass condition: crossfade endpoints clean, phase invert exact, feedback stable below rev-A documented threshold, and the `FB PHASE` legend matched to observed loop behavior per step 4.

## S-1  Full System Audio Validation

Run only after P-0 through P-5 each pass standalone, with all boards mated through the harness defined in [rev-a-harness-map.md](rev-a-harness-map.md) and all four tanks installed.

1. Repeat the input/output P-1 checks with the full signal chain populated and `WET/DRY` at fully dry. Output must still meet `+4 dBu +/- 0.5 dB` into `600 ohm`.
2. With `WET/DRY` at center and `MODE` cycled through `Off / Series / Parallel`, verify the curated `applyDefaultGasSettings` startup behavior in [rev-a-control-ranges-and-laws.md](rev-a-control-ranges-and-laws.md).
3. THD+N at `+4 dBu` output, `WET/DRY` fully dry, all controls at curated defaults: under `0.05 percent` from `20 Hz` to `20 kHz`.
4. Background noise at the balanced output with inputs terminated in `600 ohm` and `WET/DRY` fully dry: under `-90 dBu A-weighted`.
5. Listen test through the curated defaults. Tank decay, ext-tank routing, filter, clipper, crossfade, and feedback must each be audibly identifiable as distinct controls.

Pass condition: all measurements within bounds and the curated default startup state is reproducible from a cold boot.

## Failure handling

Record any failure in [rev-a-open-issues.md](rev-a-open-issues.md) with the test step number, observed value, and the board harness state. Do not advance to the next P step until the prior one passes; the bring-up sequence depends on each upstream board being correct in isolation.

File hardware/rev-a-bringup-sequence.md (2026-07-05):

# GAS Rev A Bring-Up Sequence

This is the intended order for first-power and first-audio work once the real boards exist.

## 1. Power / Backplane Only

- verify wall-adapter polarity and service-endcap DC jack wiring with the unit unplugged
- power the backplane with no audio boards connected
- verify:
  - `+15VA`
  - `-15VA`
  - `+5VAUX`
  - single controlled `AGND` to `CHASSIS` bond
- confirm no abnormal DC-DC or `+5V` regulator heating

## 2. I/O Board Standalone

- connect only `H1`
- inject balanced `+4 dBu` at `1 kHz`
- verify:
  - balanced receiver output is clean
  - mono-to-stereo duplicates the left internal source as intended
  - `DRY_L/R` and `WET_SEND_L/R` are present
  - balanced outputs produce equal and opposite hot/cold legs

## 3. Tank Driver / Recovery Board Standalone

- connect only board power
- verify quiescent rail current before tanks are attached
- trim or inspect primary send idle current at zero signal
- inject a small bench signal into each send stage and verify no oscillation
- short recovery inputs through a safe test network and verify gain/noise floor

## 4. Ext-Routing Board Plus Tank Driver / Recovery

- connect `H5`, `H6`, and `H14`
- exercise `Off`, `Series`, and `Parallel`
- confirm relay logic and contact routing before real tanks are attached
- then attach tanks and verify send level stays within a safe starting range

## 5. Crossfade / Feedback / Wet Board

- connect `H7`, `H10`, and `H12`
- verify crossfade reaches both extremes cleanly
- start with minimum feedback and increase slowly
- confirm phase invert changes loop polarity and does not pop excessively

## 6. Filter / Clipper Board

- connect `H8`, `H9`, and `H13`
- verify clean mode first
- then verify silicon, LED, and germanium clip paths one at a time
- sweep HPF and LPF controls to confirm stereo tracking is at least acceptable for rev A

## 7. Full-System Audio Pass

- reconnect the full chain
- verify:
  - dry-only output
  - wet-only output
  - ext tanks `Off`
  - ext tanks `Series`
  - ext tanks `Parallel`
  - mono-to-stereo on and off
  - feedback stable across the intended control range

## First Measurements To Archive

- rail voltages at every board
- quiescent current per rail
- primary send DC offset and idle current
- balanced output amplitude at nominal `+4 dBu`
- noise floor with tanks connected and with tanks disconnected

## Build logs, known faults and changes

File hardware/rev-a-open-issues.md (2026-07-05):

# GAS Rev A Open Issues

This file keeps the remaining unresolved items visible so they do not get mistaken for completed design decisions.

## 0. io-board: Vias in SMD Pads (rev-B layout item)

Recorded `2026-07-04` from the NextPCB HQDFM report on the io-board fab package.

Open issue:

- four `AGND` vias sit inside SMD pads: `C92.2`, `C94.2` (100n decoupler pads, 0.4 mm drill) and `U2.5`, `U4.5` (OPA1656 pads, 0.3 mm drill)
- during reflow, solder can wick down the via barrel and starve the joint (tombstoning / weak fillet risk)
- automated relocation was attempted and rejected: with the rev-A 0.2 mm design rules there is no compliant off-pad landing within 3.2 mm of any of the four pads (nearest candidate: 0.21 mm margin to a `-15VA` rail at `U2`) — a proper fix needs interactive re-routing

Status:

- rev A: accepted for the 5-board prototype run; order with bottom-side solder-mask plugged vias if offered, and bench-inspect these four joints on arrival (all reworkable by hand, all `AGND`)
- rev B: relocate the four vias off-pad during the next layout pass, when re-routing is on the table anyway
- HQDFM false alarms noted for the record: "Missing THT holes x9 / pad count mismatch x9" is the tool matching `J1-J4` to the 9-terminal Neutrik panel jack instead of the board-mounted JST `B3B-XH-A`; all 37 through-hole pads verified present in the drill file on `2026-07-04`. "Open/Shorts (IPC): Fail" reflects the absent IPC-D-356 netlist, not a detected fault.

All-board HQDFM triage (`2026-07-04`, reports on the other five boards):

- drill files verified complete on **all six boards**: every through-hole pad and via in each `.kicad_pcb` has a matching hit in its `.drl`; every "missing THT hole / pad count mismatch" flag traces to the same JST-vs-library matching artifact (flagged refs: `P301`, `P201`, `P501` area, `J101`, `P402`)
- **filter-clipper had 9 duplicated AGND vias** (8 stacked at identical coordinates, one pair 8 um apart). Fixed in the fab output on `2026-07-04`: duplicate drill hits removed from `filter-clipper.drl` (loose and in-zip; 118 -> 109 hits), verified zero duplicates and full pad/via coverage after the edit; original zip preserved in the session backup. The duplicate via objects still exist in `filter-clipper.kicad_pcb` — deduplicate there during the rev-B pass
- further via-in-pad instances to relocate in rev B (accepted for rev A): ext-tank-routing `C297` area (x2), power-backplane `C505` (via only 11.75% on pad — barely touching), tank-driver-recovery `R153` area (x2)
- power-backplane "NPTH attribute PTH" flag: no drill hit exists at the flagged location (nearest holes are the `P502`/`P503`/`P504` 1.7 mm PTH pads >=1.4 mm away); with KiCad merged drill files fabs plate all holes by default, so no unplated-signal-hole risk exists. Noise
- minor footprint-quality notes for rev B, no rev-A action: "heel distance F_Flat_Lead" x1 on four boards (same footprint signature), "oversized chip pads" x2 on filter-clipper (tombstone-risk warning), "side distance C_C_Bend" x1 on power-backplane, no fiducials on any board (fab adds panel fiducials for assembly; consider 3 local fiducials per board in rev B)

## 1. Combo Jack Output Convention

The project requirement is combo `XLR / TRS` jacks for both input and output.

Open issue:

- standard combo-jack families are most conventional on inputs
- using them on balanced outputs may force a less-common female-XLR output convention

Status:

- requirement preserved
- needs final mechanical sanity-check before enclosure metalwork is frozen

## 2. Primary Tank Driver Final Topology

Current rev-A starting point:

- split-rail `OPA1656IDR` predriver plus `BD139-16` / `BD140-16` emitter-follower output stage

Open issue:

- this is more aligned with the audio-path capacitor preference
- but it is more complex and needs bias/stability tuning
- the old LM386 path remains as a fallback if bench results force a simpler first build

Status:

- preferred direction is now the direct-coupled split-rail stage
- final bias/stability details still need schematic and bench work

## 3. Exact Stereo Pot Families

Open issue:

- final panel hardware families for the multi-control stereo sections are not fully frozen

Status:

- architecture is stable
- exact panel hardware can be finalized after enclosure spacing is more concrete

## 4. Endcap Density And Preferred Diameter

Resolved 2026-07-04:

- diameter decided: `10 in` nominal, chosen for off-the-shelf pipe/cap availability (`9 in` fits the layout but is rarely stocked)
- hole-table positions finalized: toggles moved inboard/down, wet/dry and HPF cutoff raised `1/4 in`, DC jack at `(95, -18.35)` after two clash corrections

Status:

- the endcap drilling pattern passes all spacing rules on both `10 in` and `9 in` faces
- remaining before metalwork freeze: measured face diameter of the purchased cap, exact Neutrik cutout geometry, and final bushing diameters

## 5. Final Filter Values

Open issue:

- HPF/LPF values and Q ranges still need listening-based tuning against the real tanks

Status:

- topology is defined
- value freezing waits for prototype evaluation

## 6. Real KiCad Capture

Open issue:

- the package now has a real top-level hierarchical KiCad shell plus full first-pass symbol coverage, but five of the six rev-A child sheets are still largely un-wired electrically

Status:

- hierarchy and PDF export workflow are now real
- manifest net-label coverage is now `82 / 82`
- all six rev-A child sheets now have first-pass real symbols (`88 / 88` required refs across the full manifest)
- overall schematic symbol coverage is now `88 / 88` refs on the latest capture audit
- the power/backplane page now has a first-pass real electrical capture for DC entry, split-rail generation, and harness fanout
- the I/O page now has an explicit schematic-ready electrical definition in [rev-a-io-schematic-ready-definition.md](rev-a-io-schematic-ready-definition.md) that freezes unit allocation, passive naming, and connector ownership before the eventual KiCad multi-unit pass
- the current top-level ERC intentionally remains an intermediate failure (`650` known violations on the latest `2026-06-29` rerun), still dominated by top-level unconnected sheet pins, placeholder wire endpoints, off-grid legacy symbol endpoints, and still-unwired child-sheet labels on the non-power sheets
- the latest contained cleanup pass was on the I/O board, where removal of accidental center-short stubs reduced that child sheet from `404` to `376` local violations and dropped its multiple-net-name collisions from `8` to `2`
- actual pin-level wiring, footprint confirmation, ERC cleanup, and PCB layout are still the next major phase

## 7. External Wall Adapter: Regulated vs Unregulated Confirmation — RESOLVED `2026-07-04`

Resolution:

- the wall adapter is now the **Triad Magnetics `WSU240-0750`**: regulated SMPS, `+24 VDC / 750 mA / 18 W`, UL 62368-1 (file `E345519`), DOE Level VI, purchased from DigiKey
- this retires the unregulated-adapter damage risk: worst case with the Triad's combined `+/-5%` regulation is `+25.2 V`, far inside the `URA2415YMD-10WR3` input range (`9-36 V`, `24 V` nominal)
- barrel plug changes from `5.5 x 2.5 mm` to `5.5 x 2.1 mm`; the service-endcap jack changes from `PJ-005B` to `PJ-005A` (same mounting hole and hardware)
- full topology update in [rev-a-external-dc-power.md](rev-a-external-dc-power.md)

Remaining follow-ups (also tracked in the rev-a-external-dc-power.md open items):

- P-0 receiving check at first power-up: open-circuit `+22.8 V` to `+25.2 V`, reject above `+27 V`
- KiCad net names `+30V_RAW` / `+30V_F` are historical labels that now carry `+24 V` nominal; rename at the next schematic capture pass before layout freeze
- the exact `PJ-005A` footprint pin map and the `PS500` enable-pin treatment still need one final datasheet-to-footprint sanity pass before layout freeze

## 8. Control Backplane Versus Direct Panel Wiring

Open issue:

- the filter and mode sections have enough controls that several small direct-control JST links are not the cleanest final wiring strategy
- the currently checked-in grouped placeholders for `P307`, `P403`, and `P405` are still electrically compressed relative to a fully honest passive off-board control harness
- the current frozen control-backplane contract does not support putting `U601` in charge of ext-routing relay coils without changing the inter-board harness definition
- rev A likely wants either board-mounted controls or a power/control/backplane landing board for the denser control groups

Status:

- the audio harness map is now stable
- the ext-routing control landing is now electrically frozen with the raw stereo amount pot plus encoded two-bit mode control
- the crossfade feedback and filter-Q control groups now have explicit schematic-ready definitions, and the new control-backplane companion makes the compressed-placeholder status expl

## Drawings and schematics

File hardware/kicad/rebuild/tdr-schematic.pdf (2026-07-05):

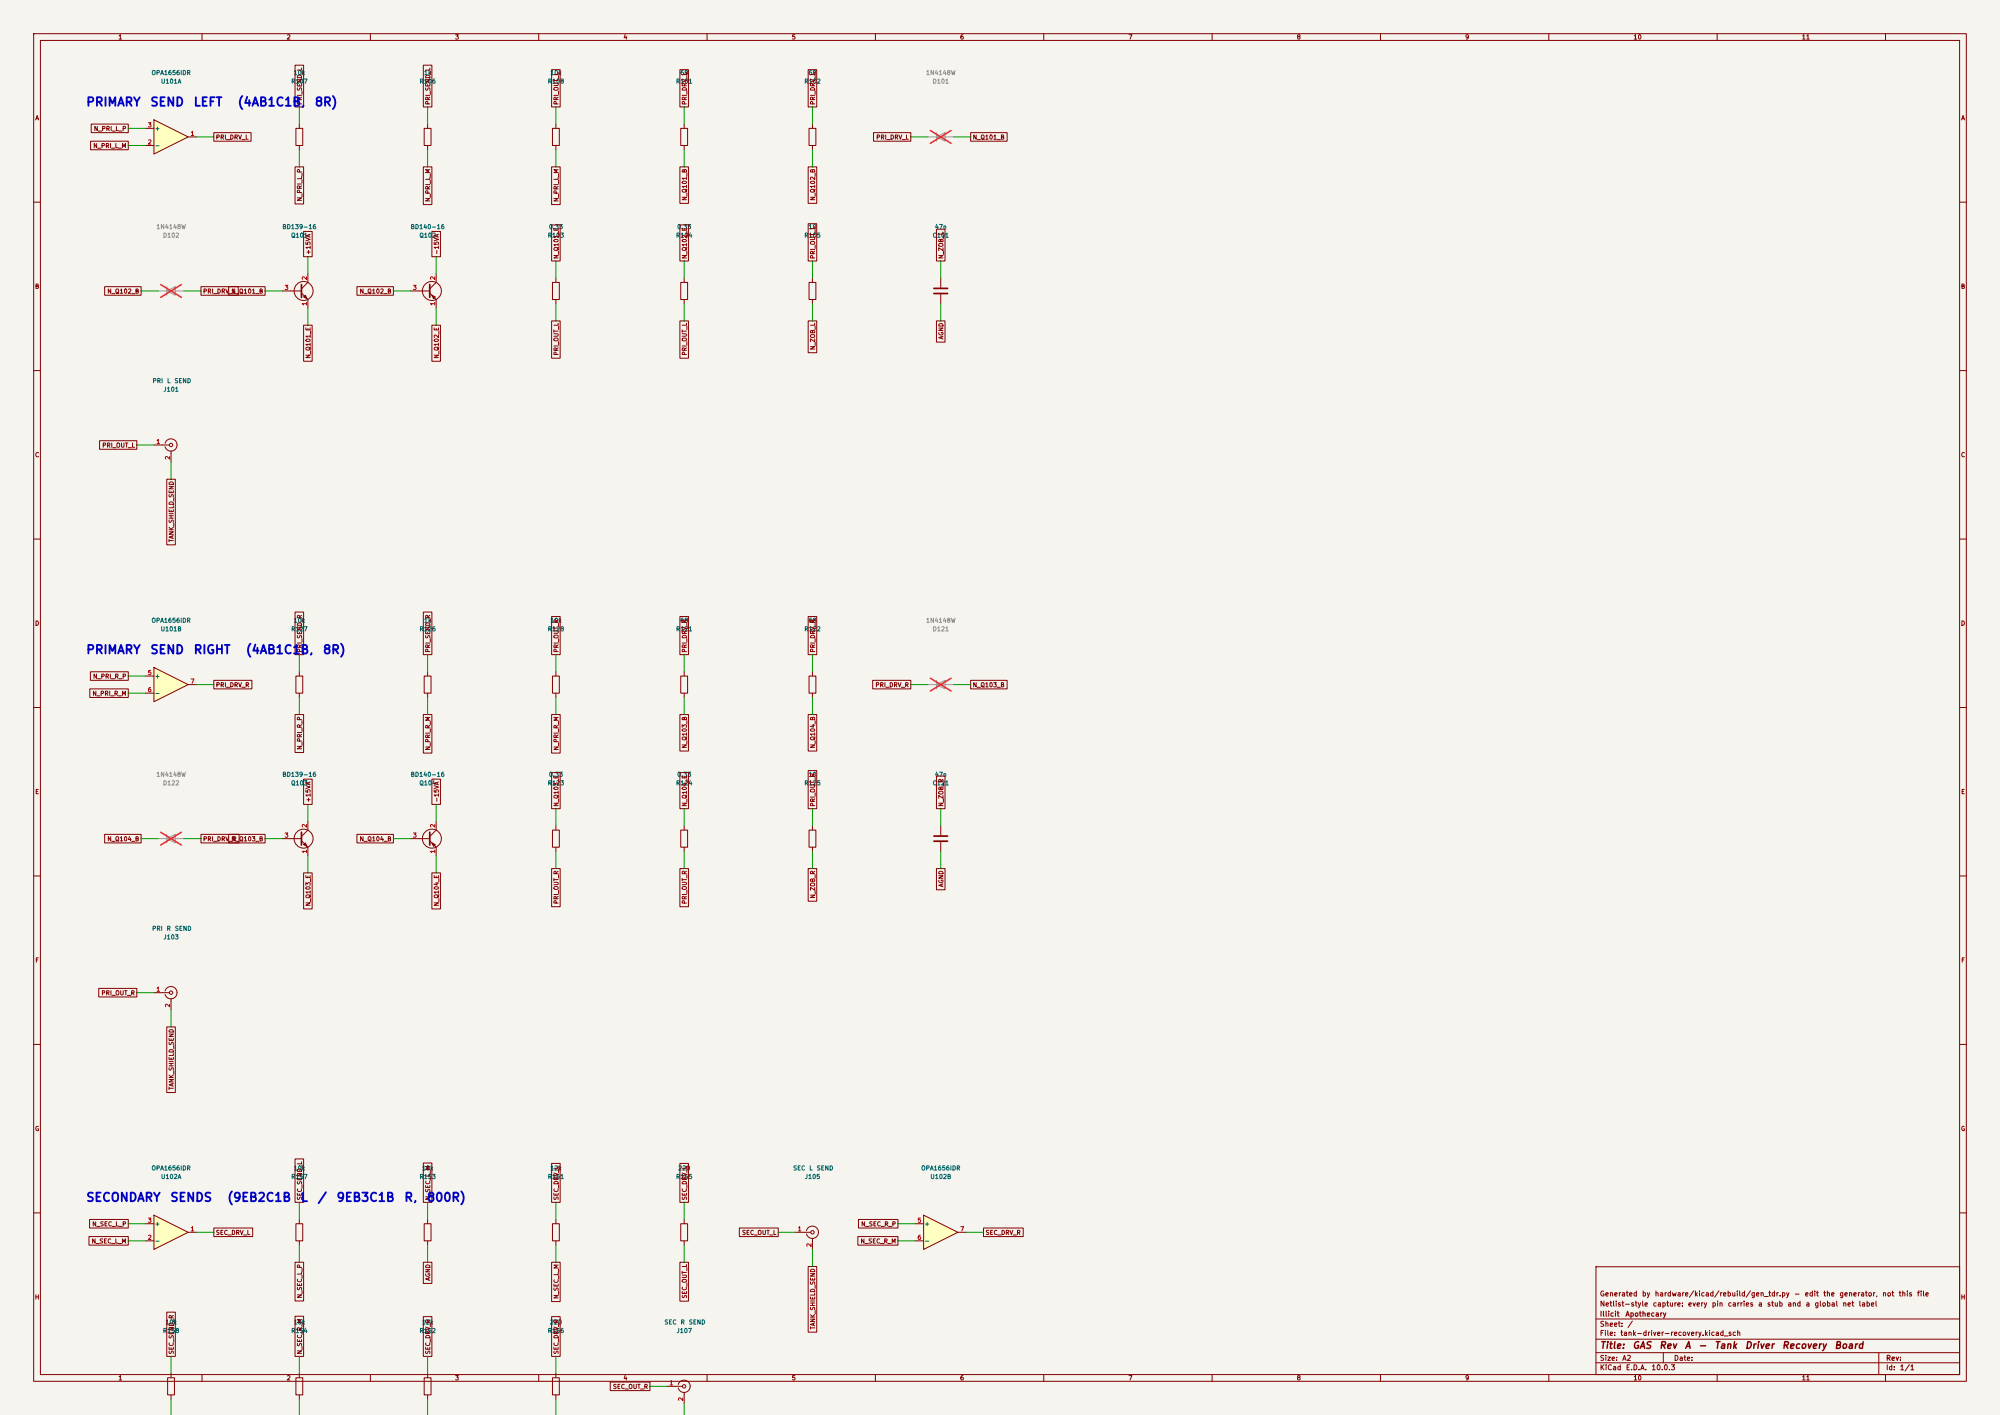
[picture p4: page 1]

Generated by hardware/kicad/rebuild/gen_tdr.py - edit the generator, not this file 1 2 3 Q103 BD139-16 D122

Netlist-style capture: every pin carries a stub and a global net label
Illicit Apothecary
Sheet: /
File: tank-driver-recovery.kicad_sch
Title: GAS Rev A - Tank Driver Recovery Board

Size: A2 | Rev:
KiCad E.D.A. 10.0.3 | Id: 1/1

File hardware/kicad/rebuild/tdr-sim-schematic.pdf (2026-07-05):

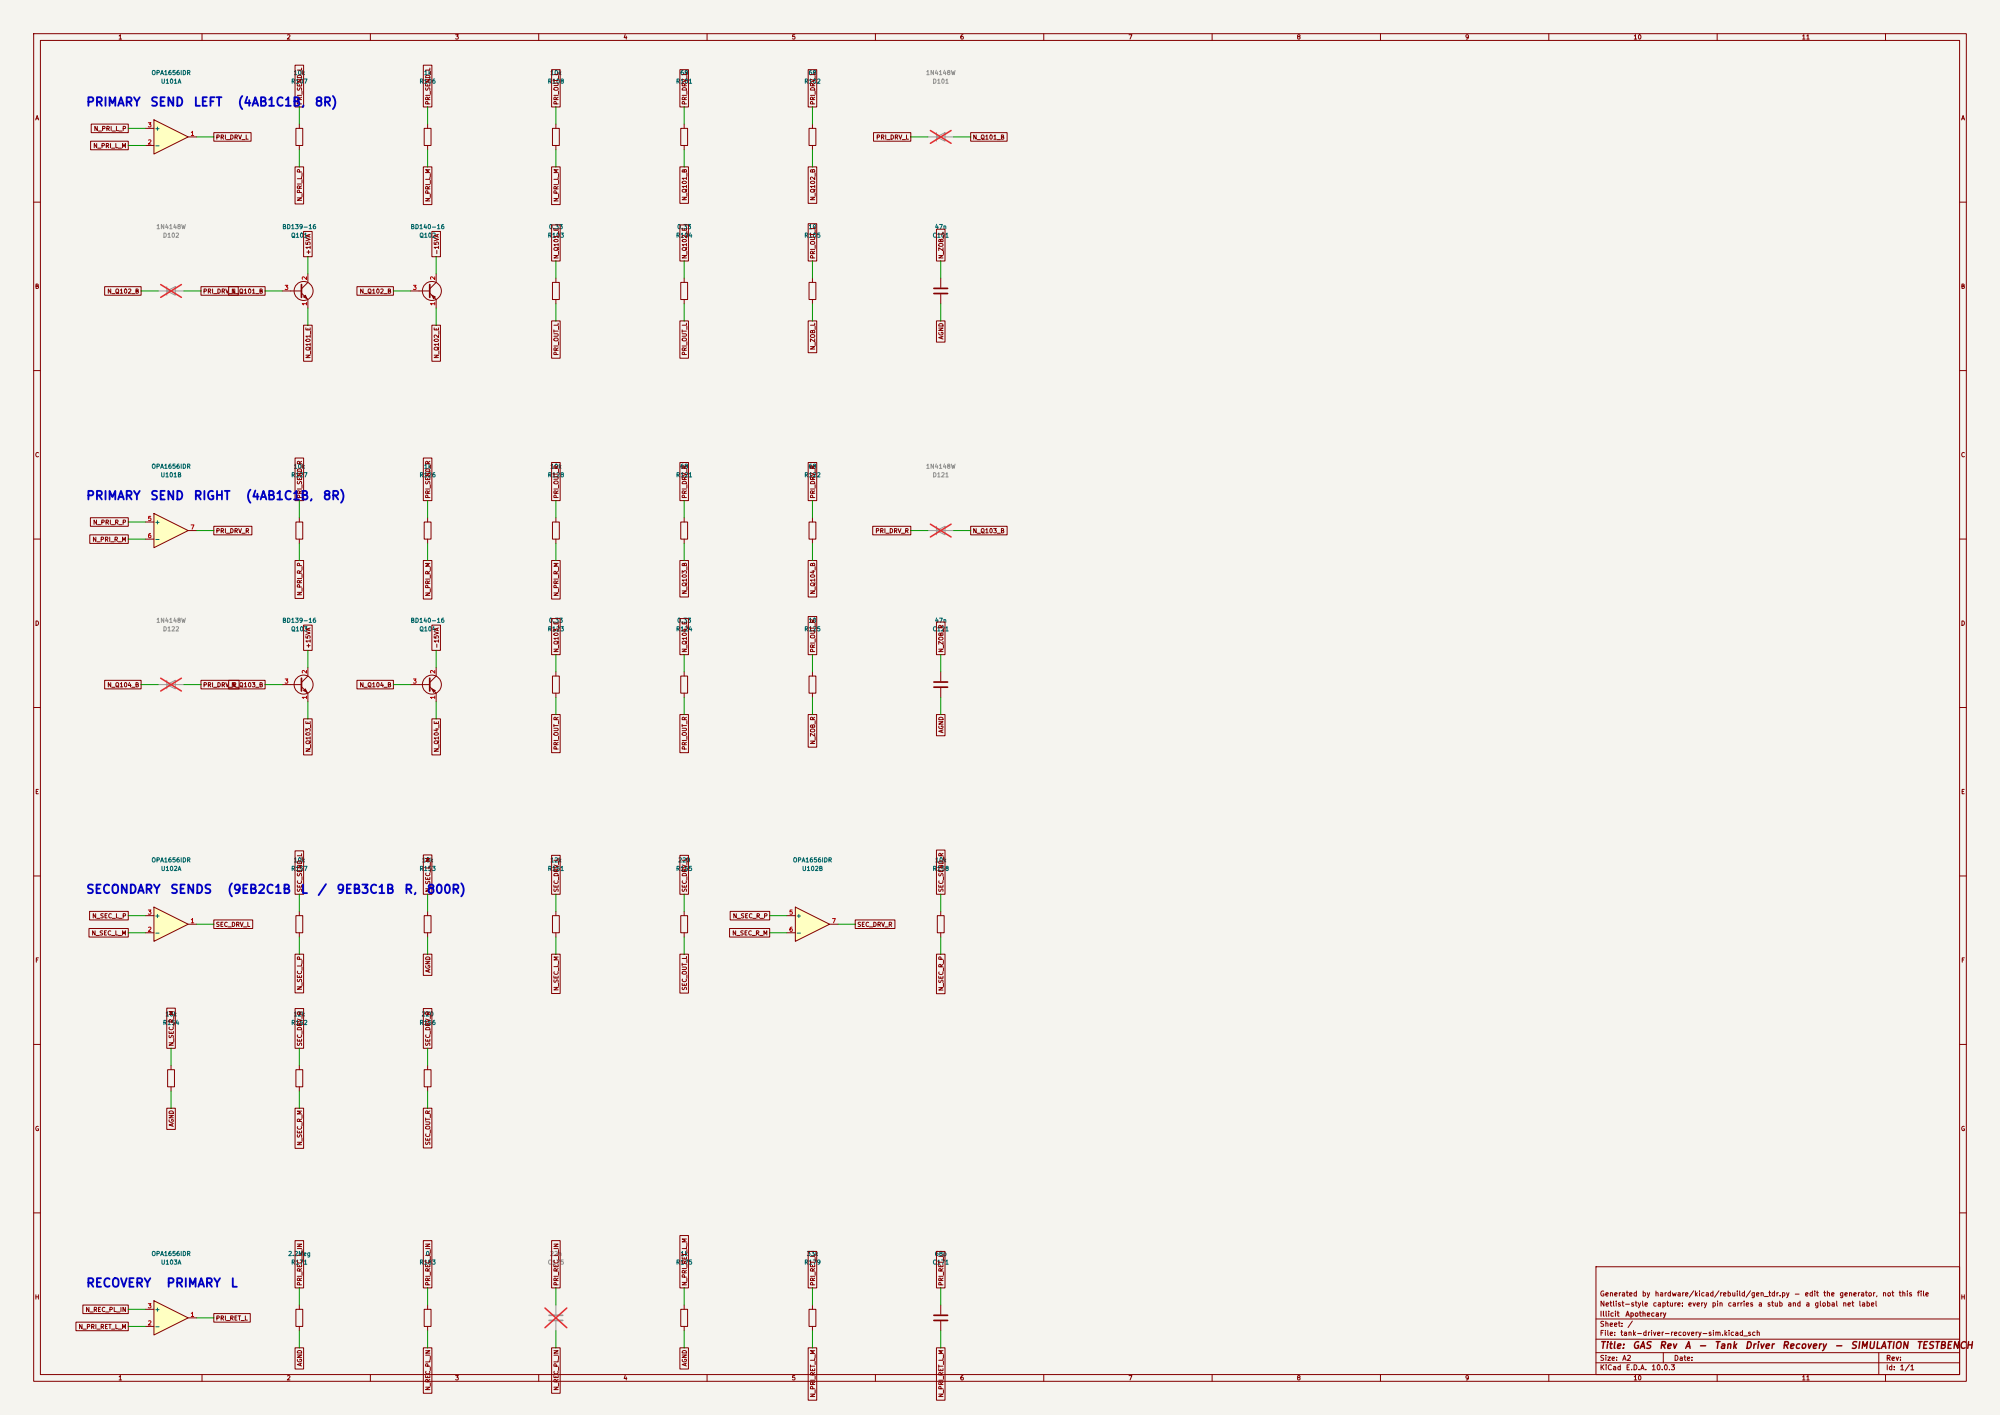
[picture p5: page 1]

Generated by hardware/kicad/rebuild/gen_tdr.py - edit the generator, not this file
Netlist-style capture: every pin carries a stub and a global net label
Illicit Apothecary
Sheet: /
File: tank-driver-recovery-sim.kicad_sch
Title: GAS Rev A - Tank Driver Recovery - SIMULATION TESTBENCH

Size: A2 | Rev:
KiCad E.D.A. 10.0.3 | Id: 1/1

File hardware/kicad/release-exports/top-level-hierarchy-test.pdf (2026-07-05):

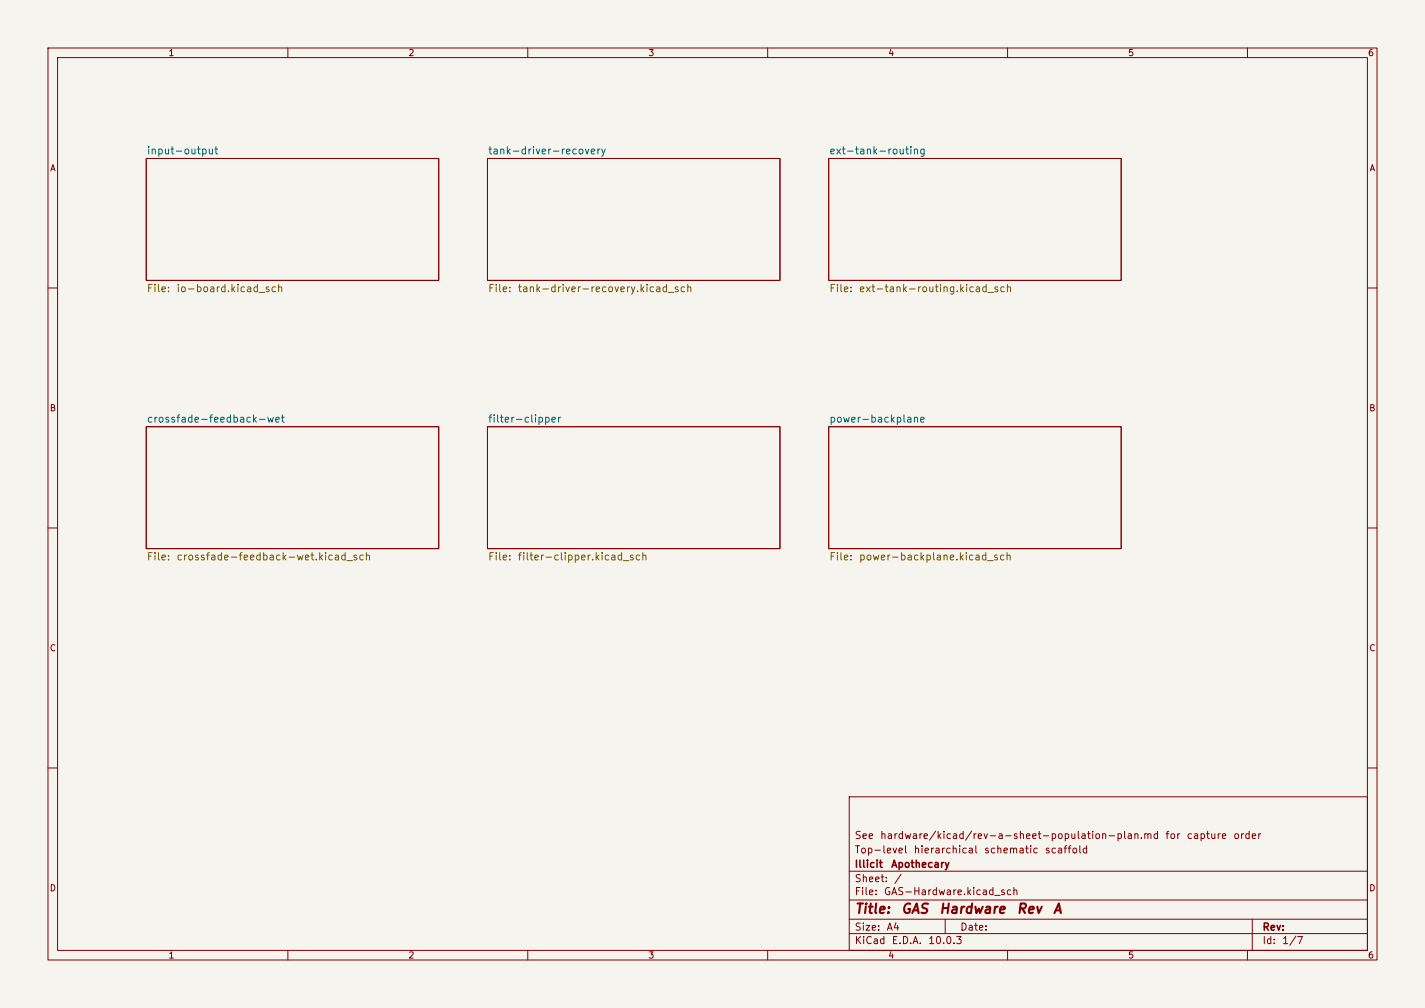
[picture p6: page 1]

File: tank-driver-recovery.kicad_sch

File: ext-tank-routing.kicad_sch

File: crossfade-feedback-wet.kicad_sch

See hardware/kicad/rev-a-sheet-population-plan.md for capture order
Top-level hierarchical schematic scaffold
Illicit Apothecary
Sheet: /
File: GAS-Hardware.kicad_sch
Title: GAS Hardware Rev A

Size: A4 | Rev:
KiCad E.D.A. 10.0.3 | Id: 1/7

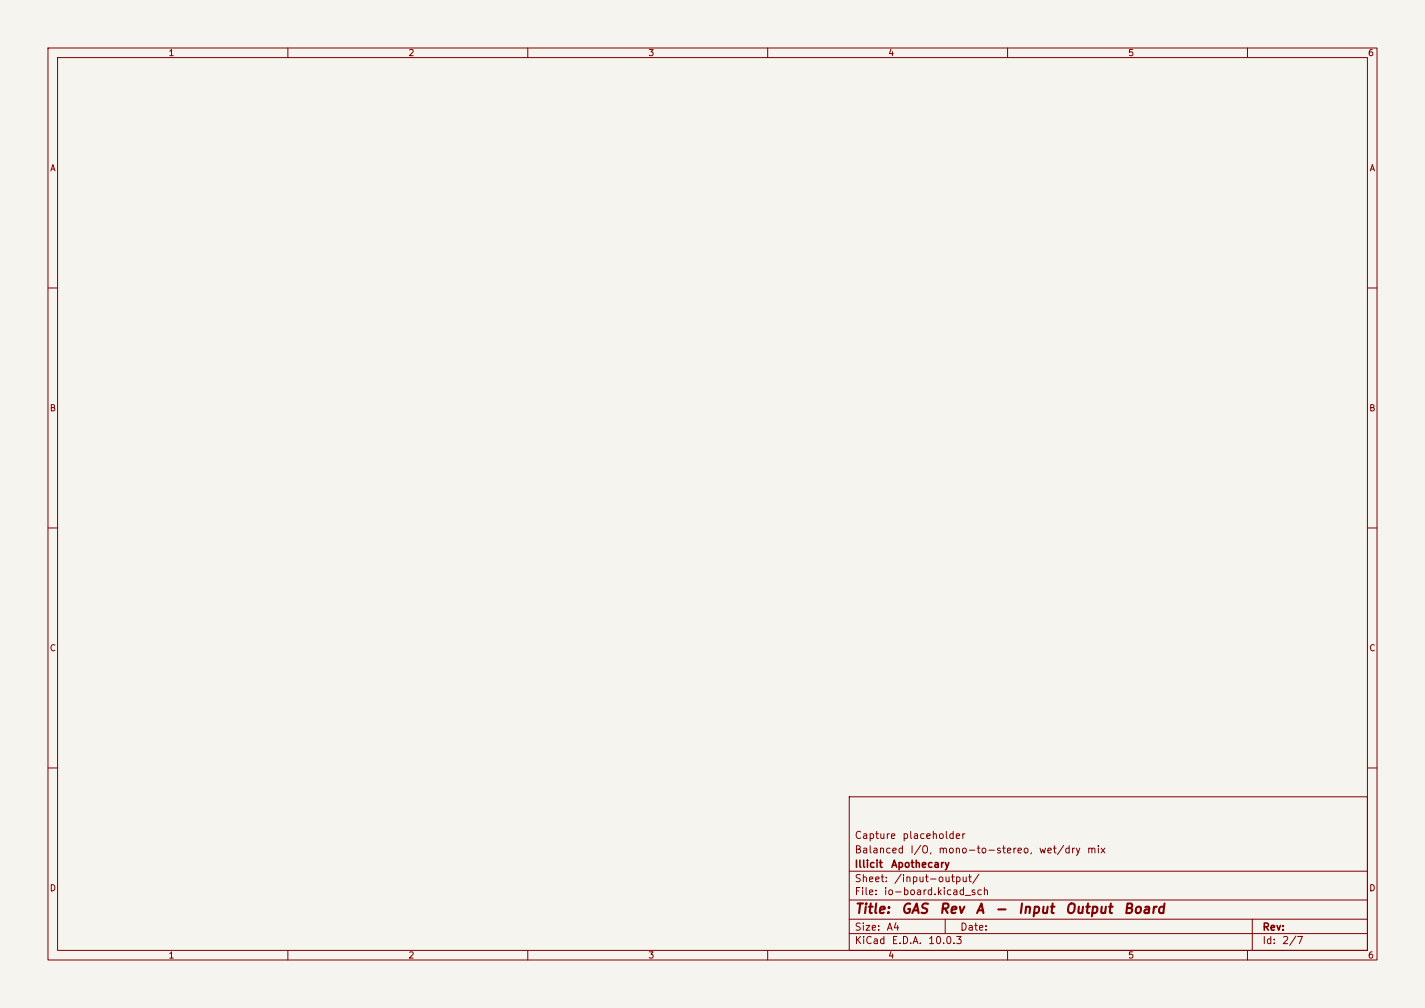
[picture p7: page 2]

Capture placeholder
Balanced I/O, mono-to-stereo, wet/dry mix
Illicit Apothecary
Sheet: /input-output/
File: io-board.kicad_sch
Title: GAS Rev A - Input Output Board

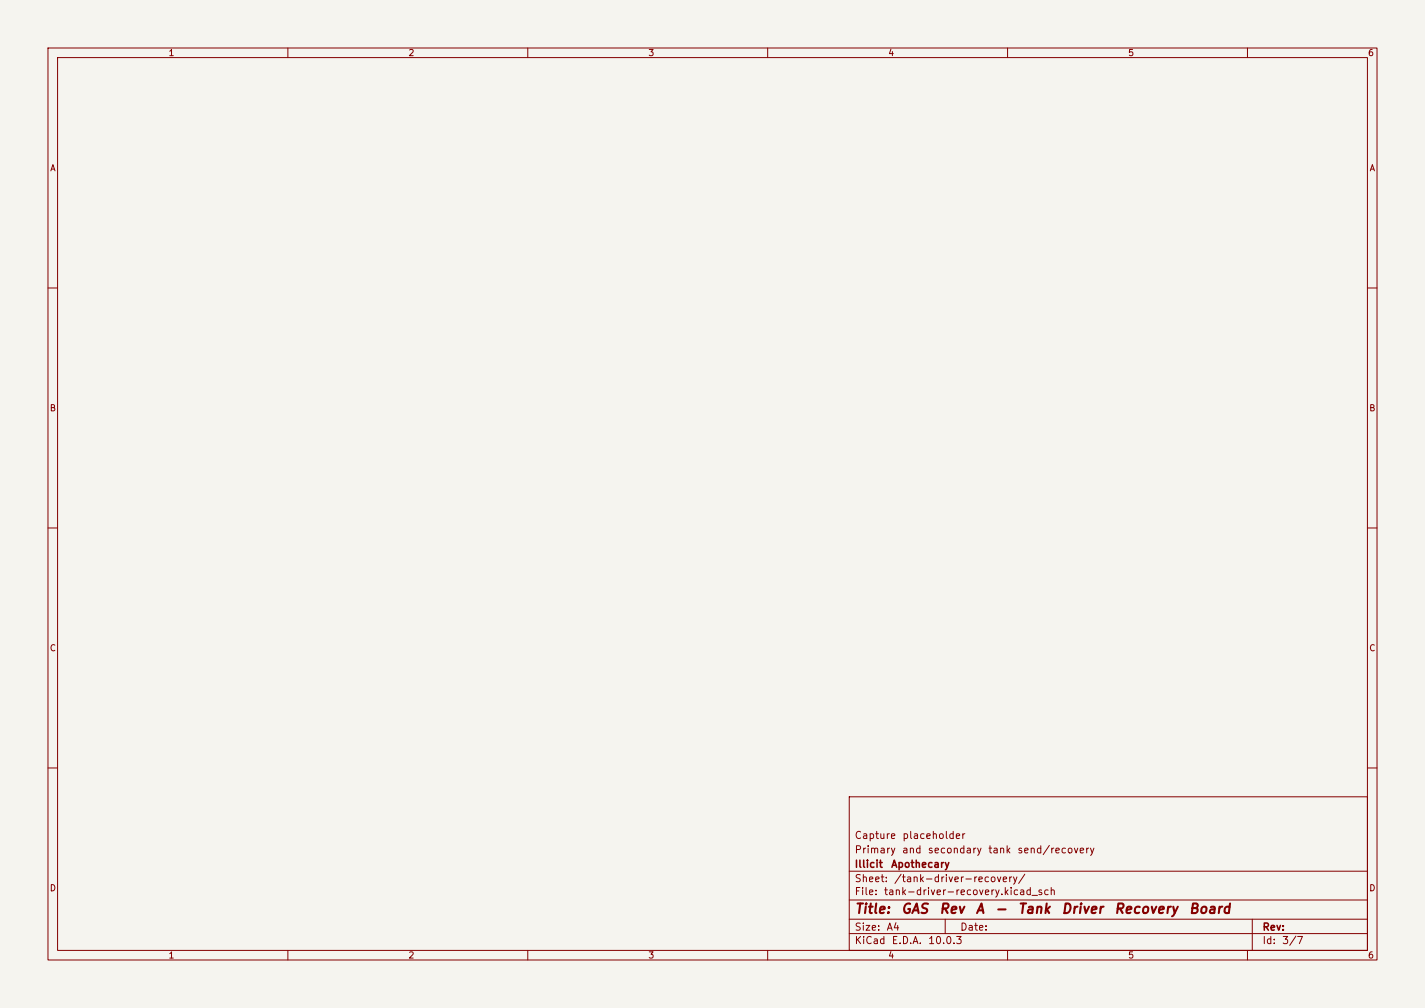
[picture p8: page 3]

Capture placeholder
Primary and secondary tank send/recovery
Illicit Apothecary
Sheet: /tank-driver-recovery/
File: tank-driver-recovery.kicad_sch
Title: GAS Rev A - Tank Driver Recovery Board

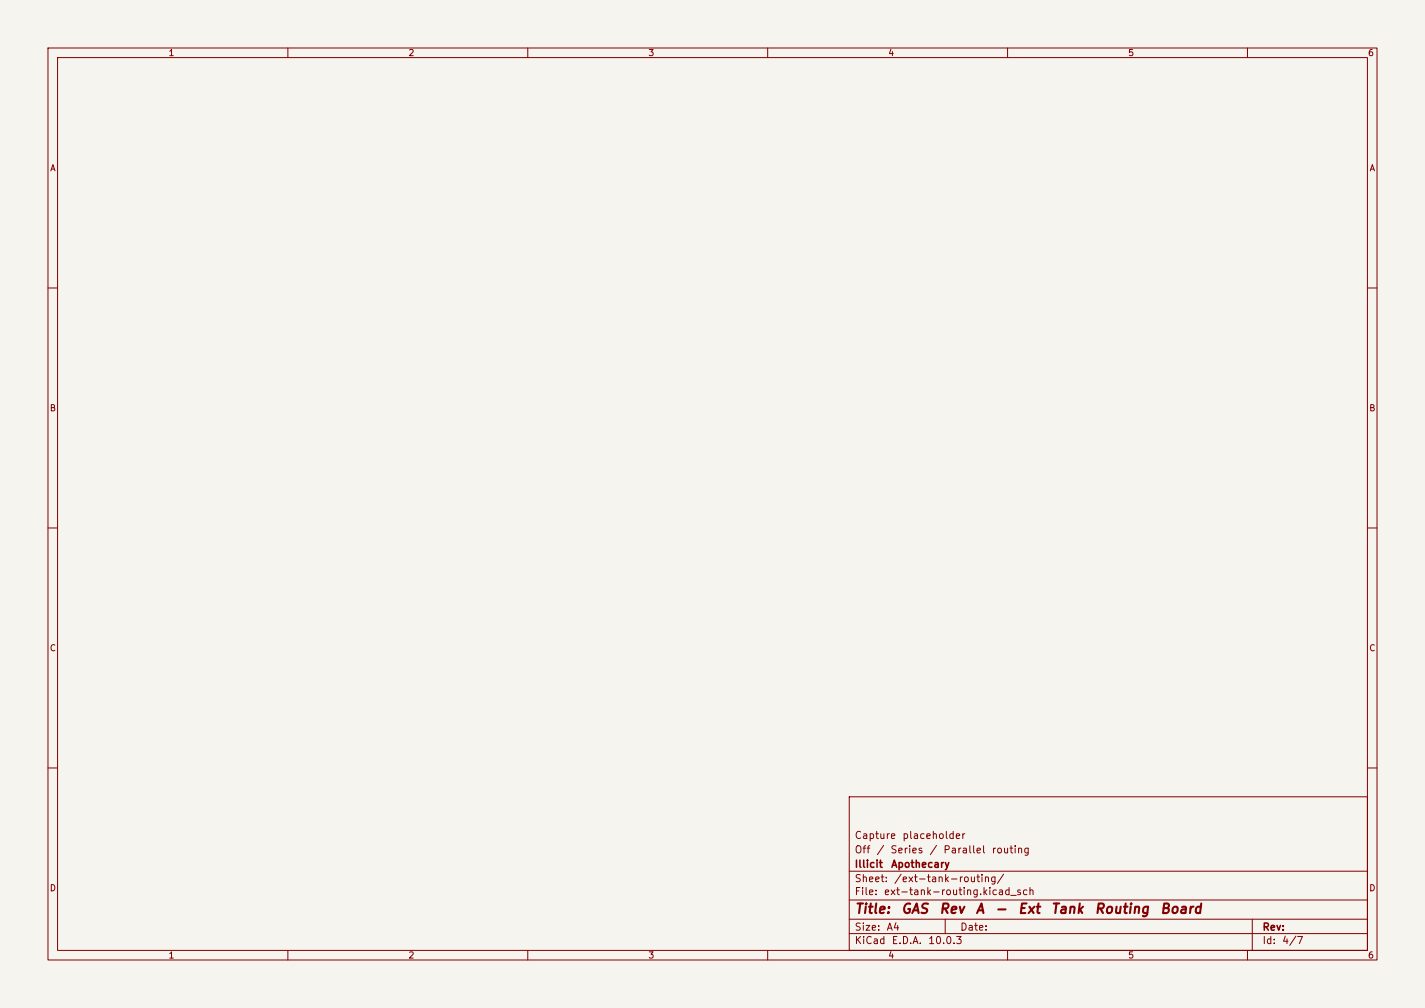
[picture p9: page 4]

Capture placeholder
Off / Series / Parallel routing
Illicit Apothecary
Sheet: /ext-tank-routing/
File: ext-tank-routing.kicad_sch
Title: GAS Rev A - Ext Tank Routing Board

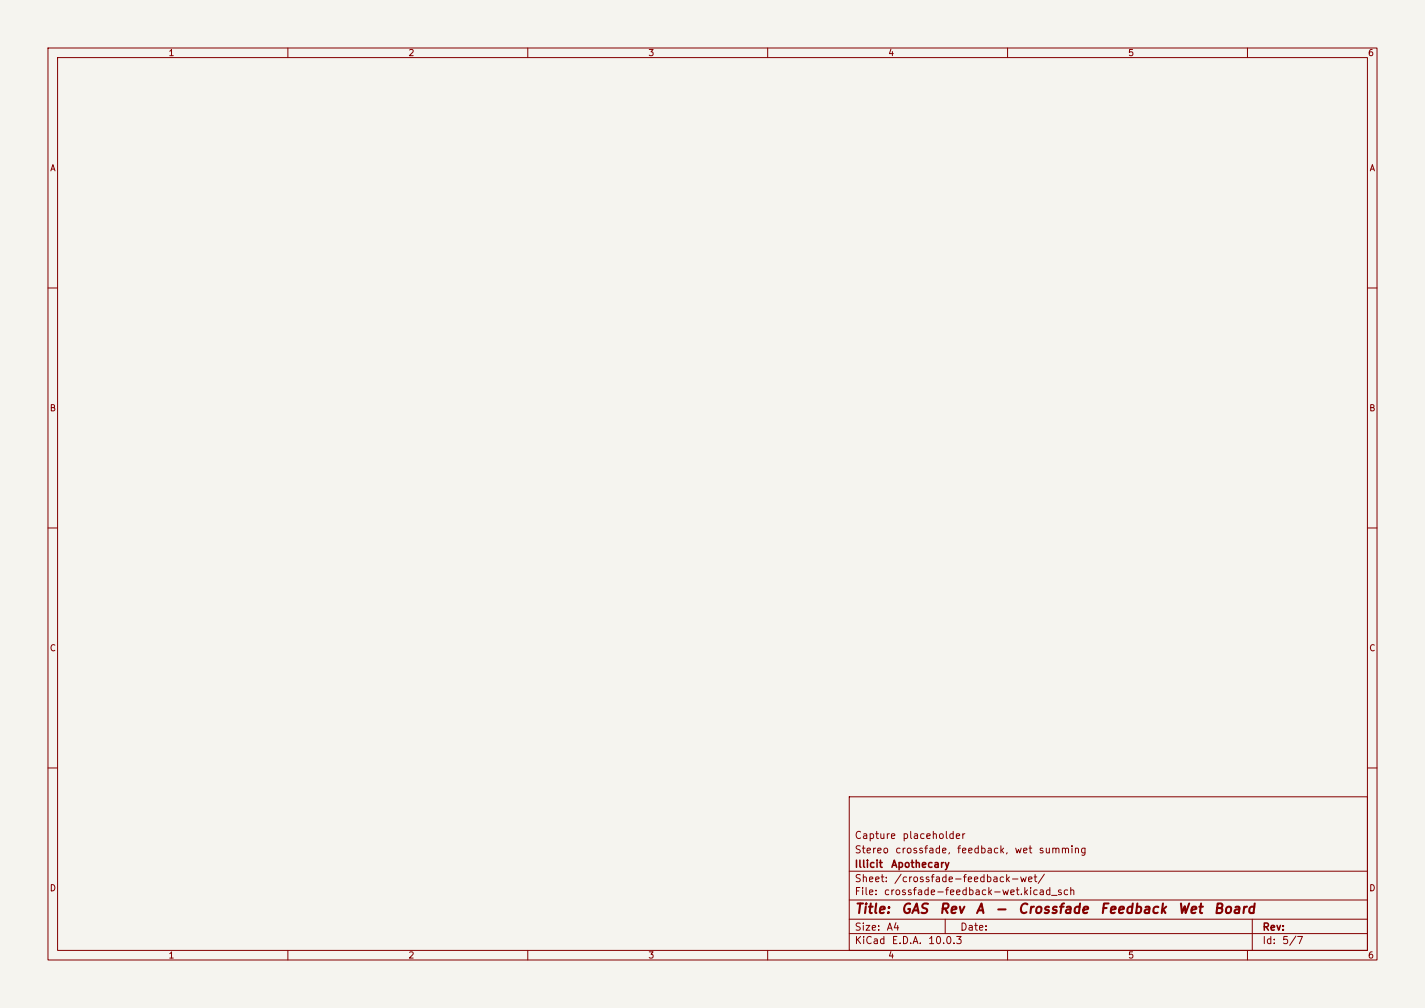
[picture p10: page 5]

Capture placeholder
Stereo crossfade, feedback, wet summing
Illicit Apothecary
Sheet: /crossfade-feedback-wet/
File: crossfade-feedback-wet.kicad_sch
Title: GAS Rev A - Crossfade Feedback Wet Board

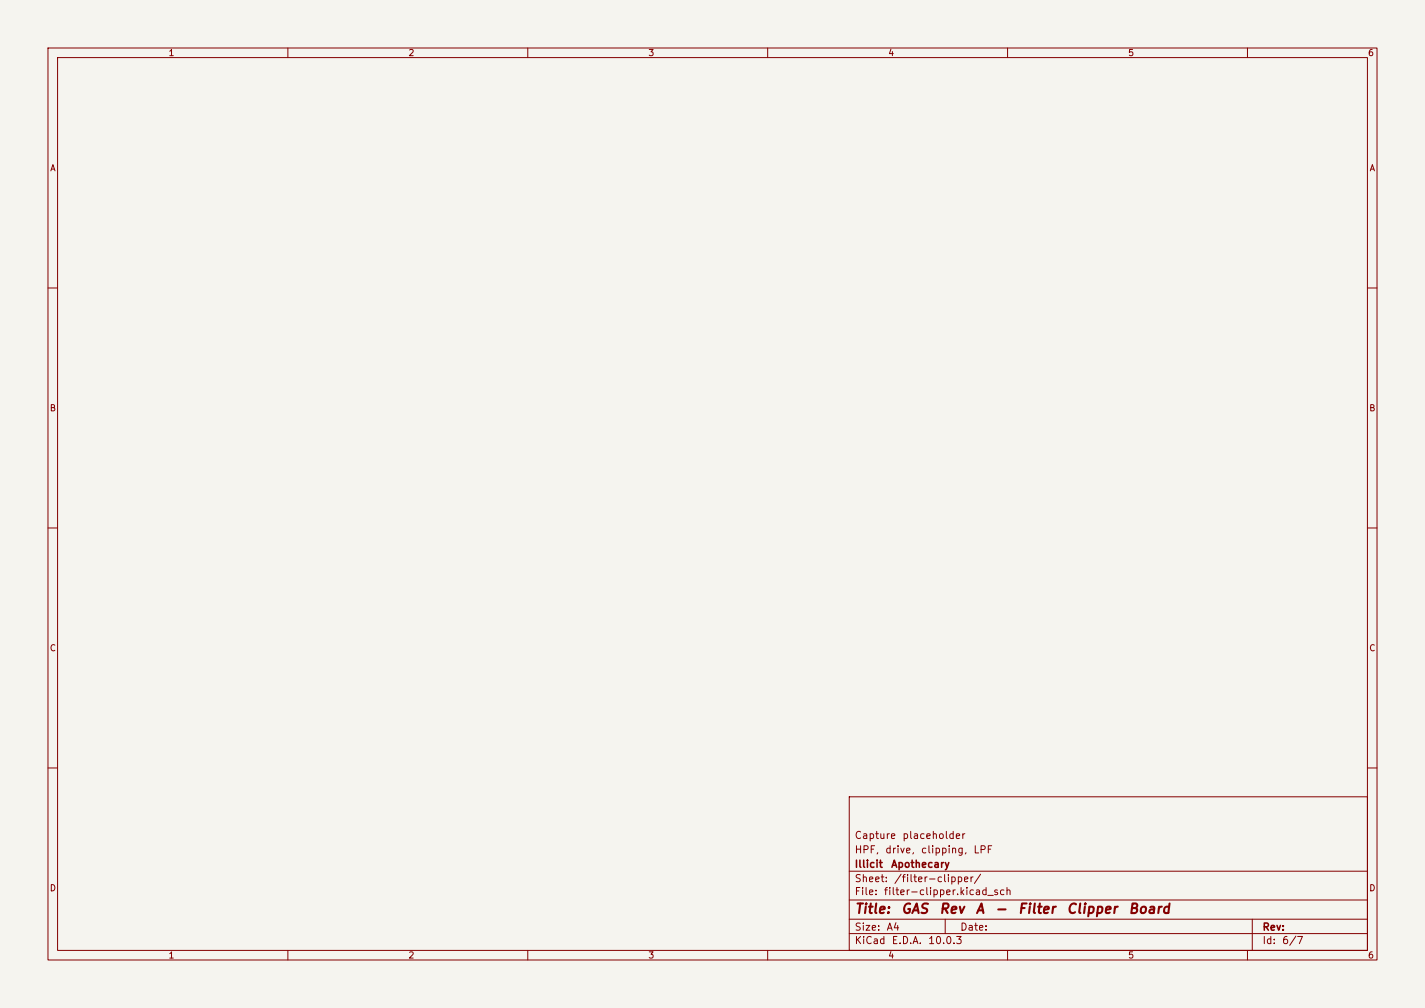
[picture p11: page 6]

Capture placeholder
HPF, drive, clipping, LPF
Illicit Apothecary
Sheet: /filter-clipper/
File: filter-clipper.kicad_sch
Title: GAS Rev A - Filter Clipper Board

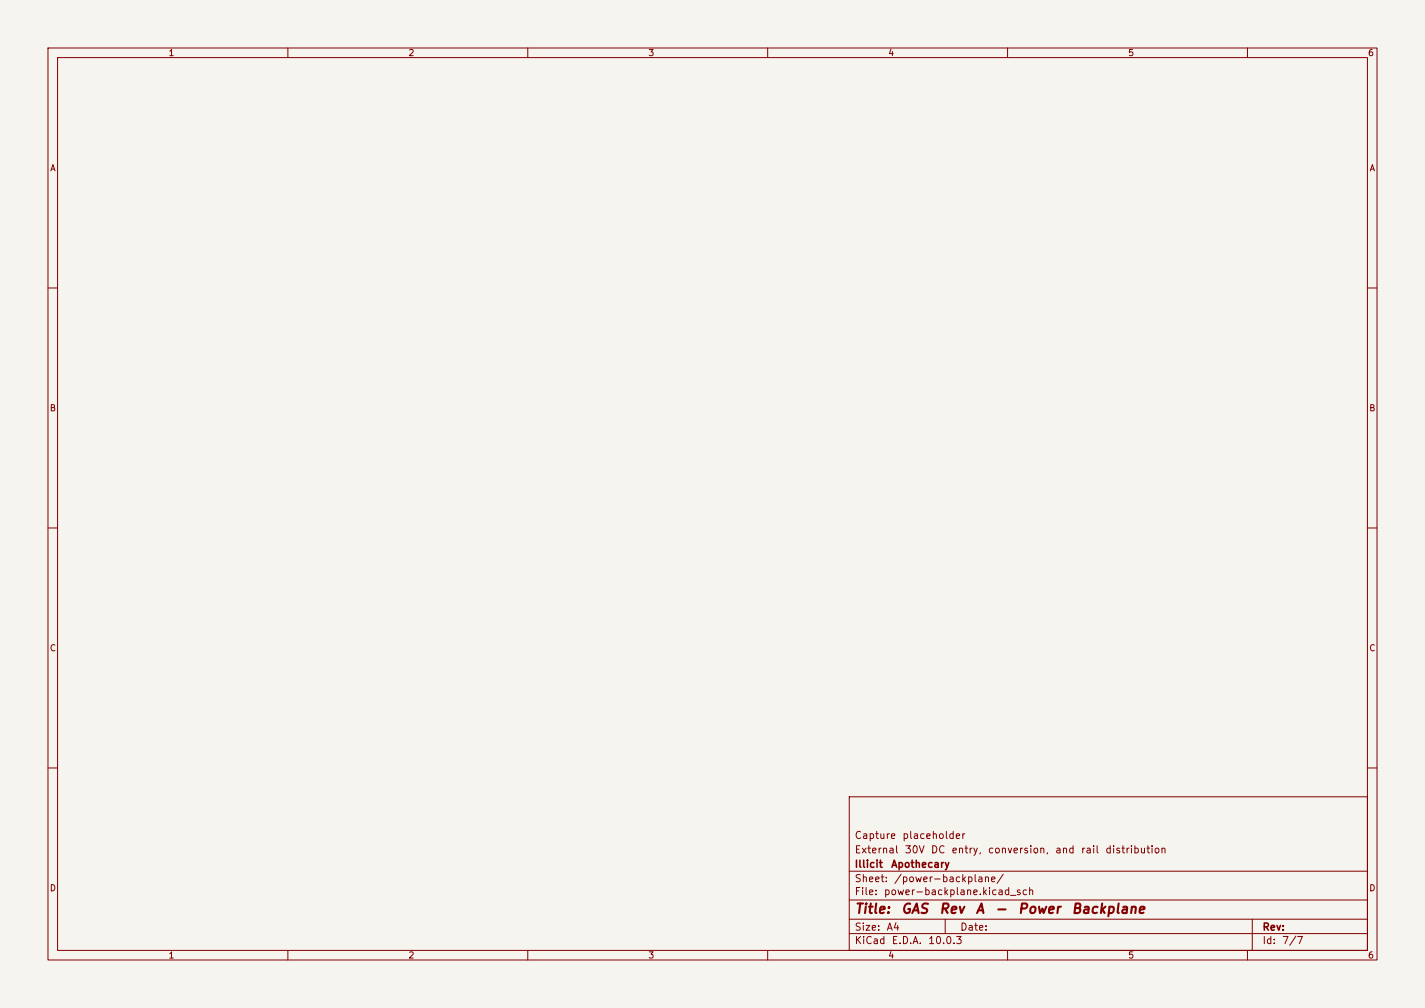
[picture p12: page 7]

Capture placeholder
External 30V DC entry, conversion, and rail distribution
Illicit Apothecary
Sheet: /power-backplane/
File: power-backplane.kicad_sch
Title: GAS Rev A - Power Backplane

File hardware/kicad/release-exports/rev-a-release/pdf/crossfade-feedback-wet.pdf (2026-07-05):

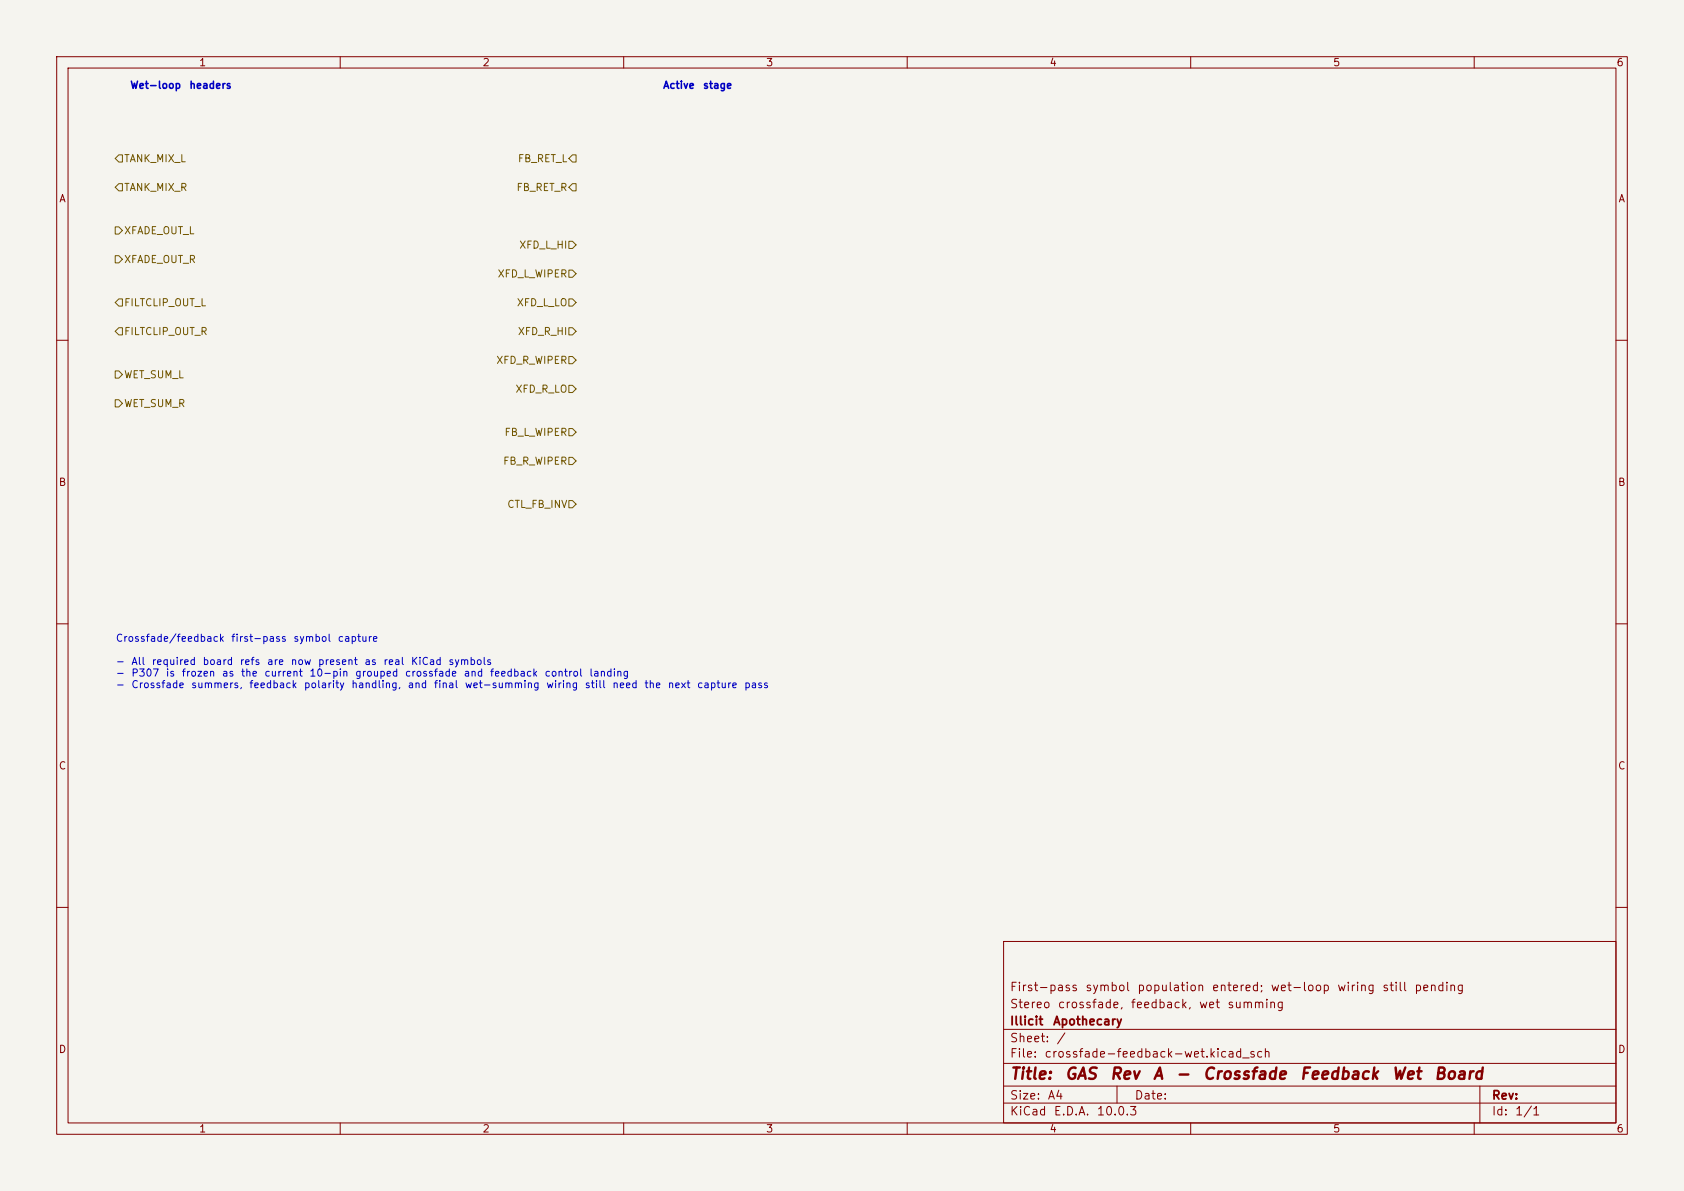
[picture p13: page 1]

Crossfade/feedback first-pass symbol capture - All required board refs are now present as real KiCad symbols - P307 is frozen as the current 10-pin grouped crossfade and feedback control landing - Crossfade summers, feedback polarity handling, and final wet-summing wiring still need the next capture pass

First-pass symbol population entered; wet-loop wiring still pending
Stereo crossfade, feedback, wet summing
Illicit Apothecary
Sheet: /
File: crossfade-feedback-wet.kicad_sch
Title: GAS Rev A - Crossfade Feedback Wet Board

Size: A4 | Rev:
KiCad E.D.A. 10.0.3 | Id: 1/1

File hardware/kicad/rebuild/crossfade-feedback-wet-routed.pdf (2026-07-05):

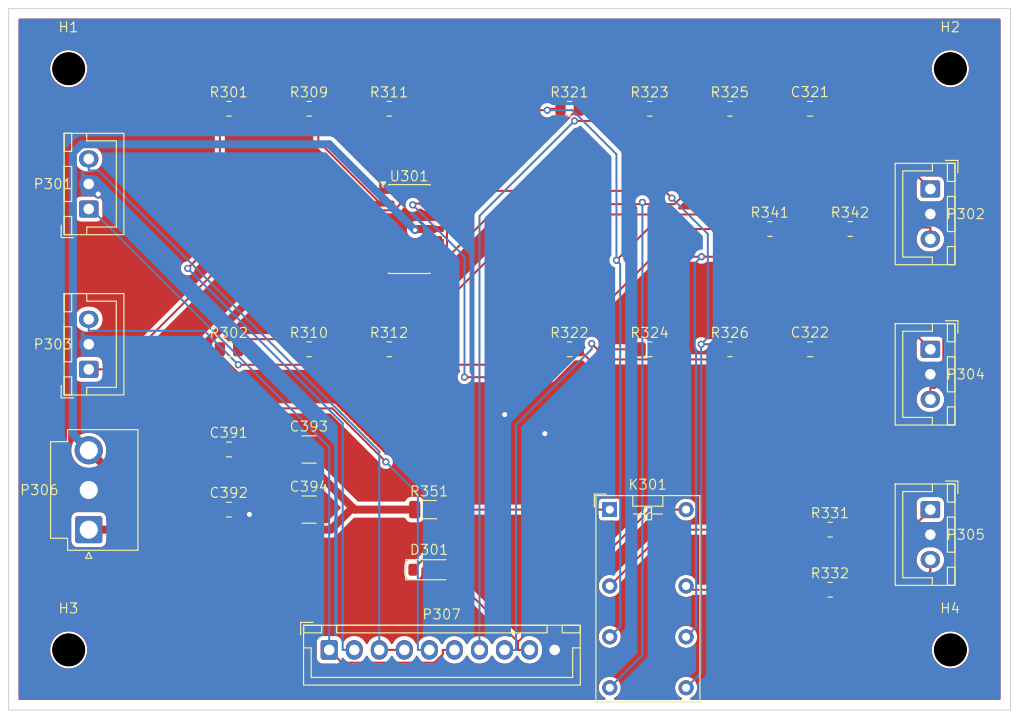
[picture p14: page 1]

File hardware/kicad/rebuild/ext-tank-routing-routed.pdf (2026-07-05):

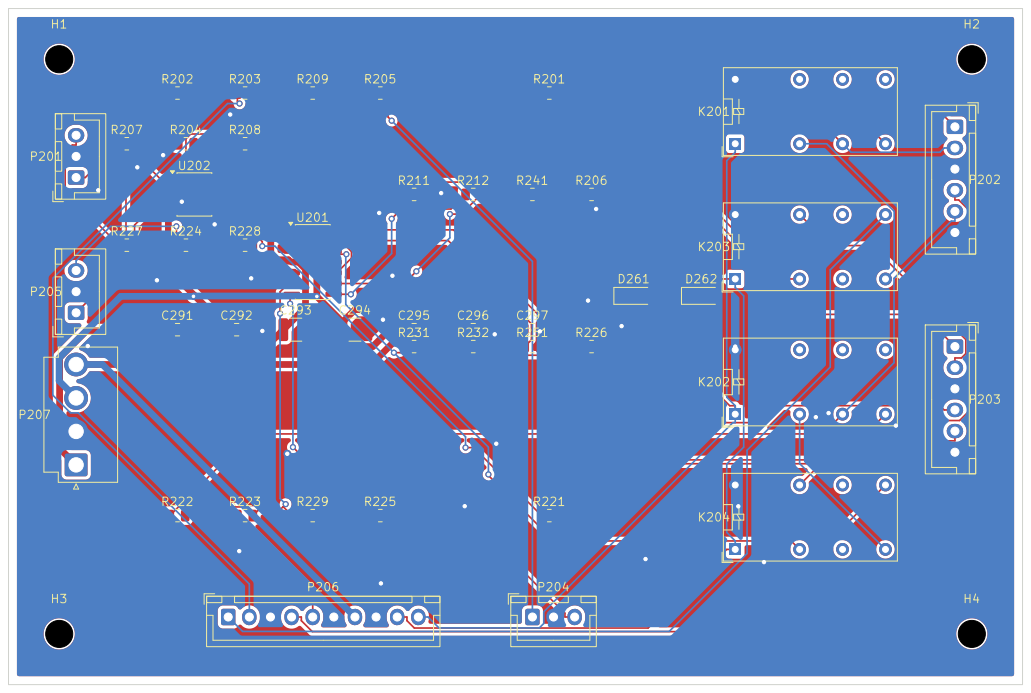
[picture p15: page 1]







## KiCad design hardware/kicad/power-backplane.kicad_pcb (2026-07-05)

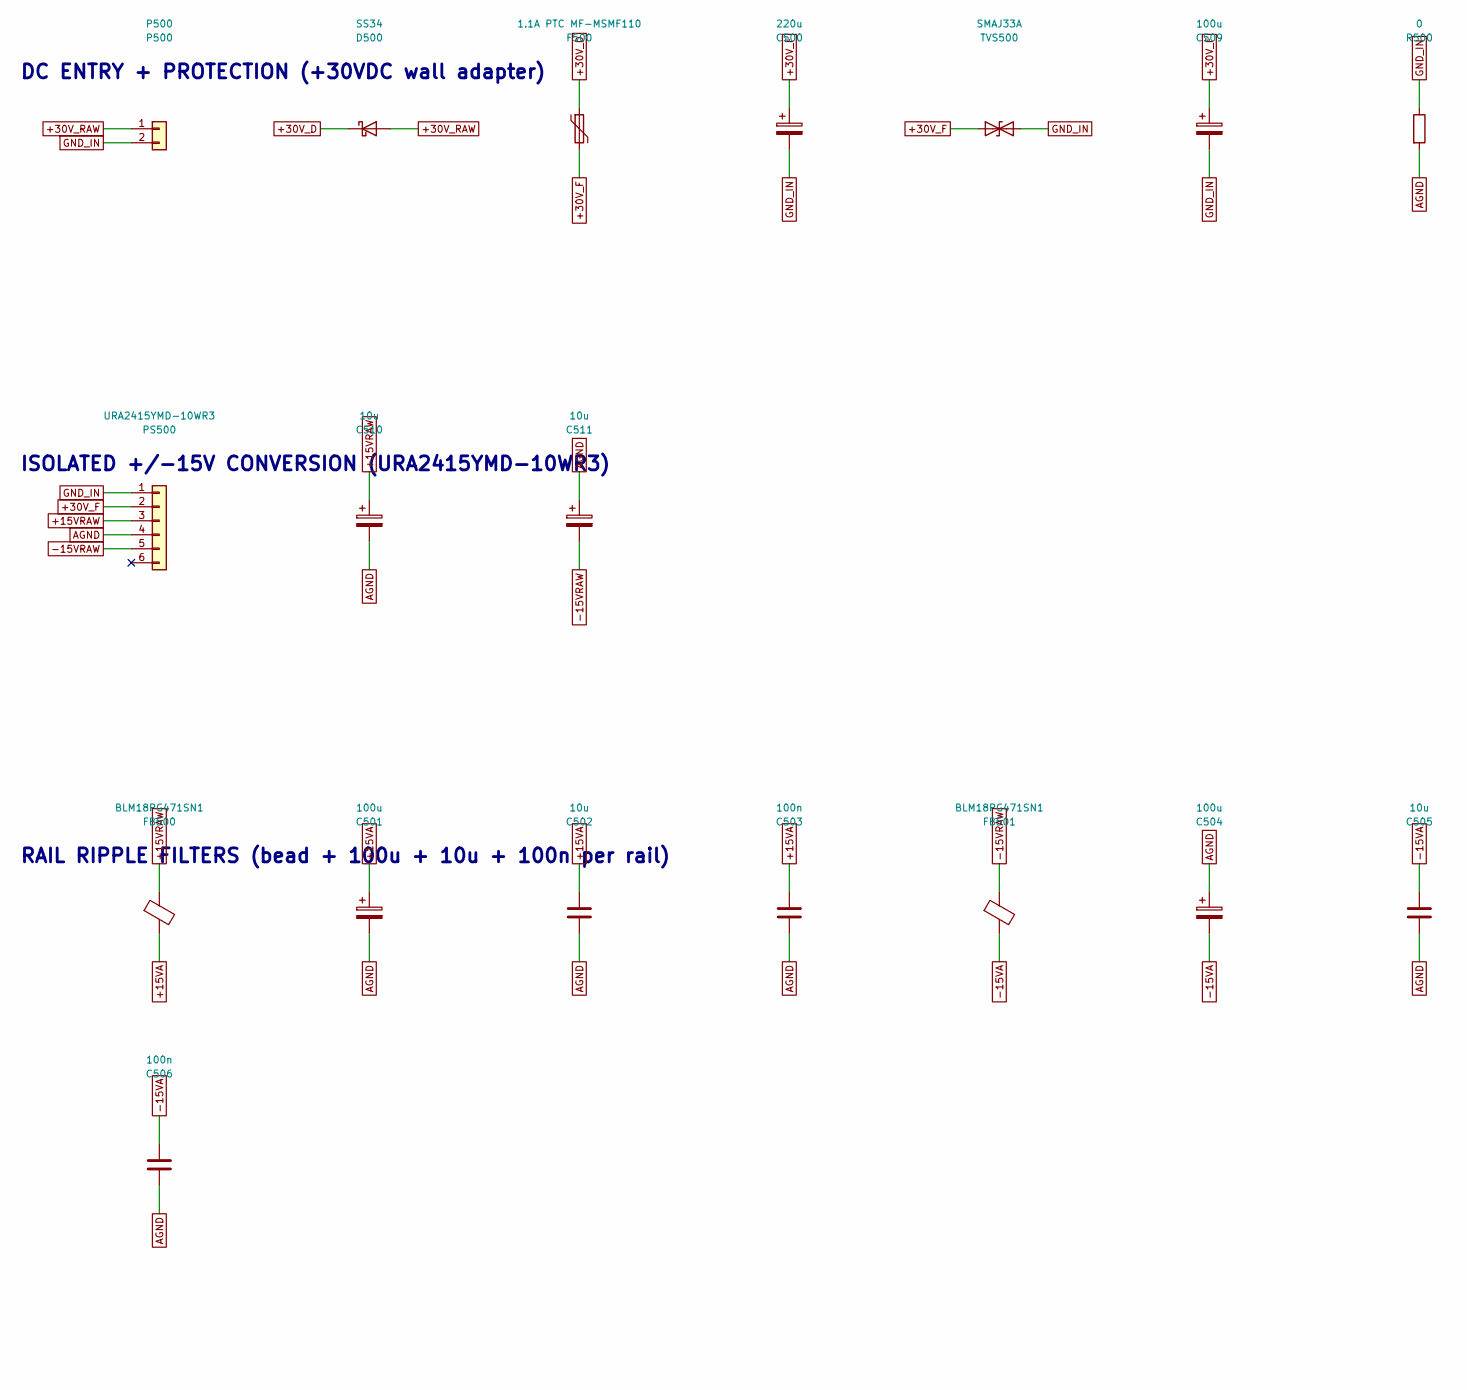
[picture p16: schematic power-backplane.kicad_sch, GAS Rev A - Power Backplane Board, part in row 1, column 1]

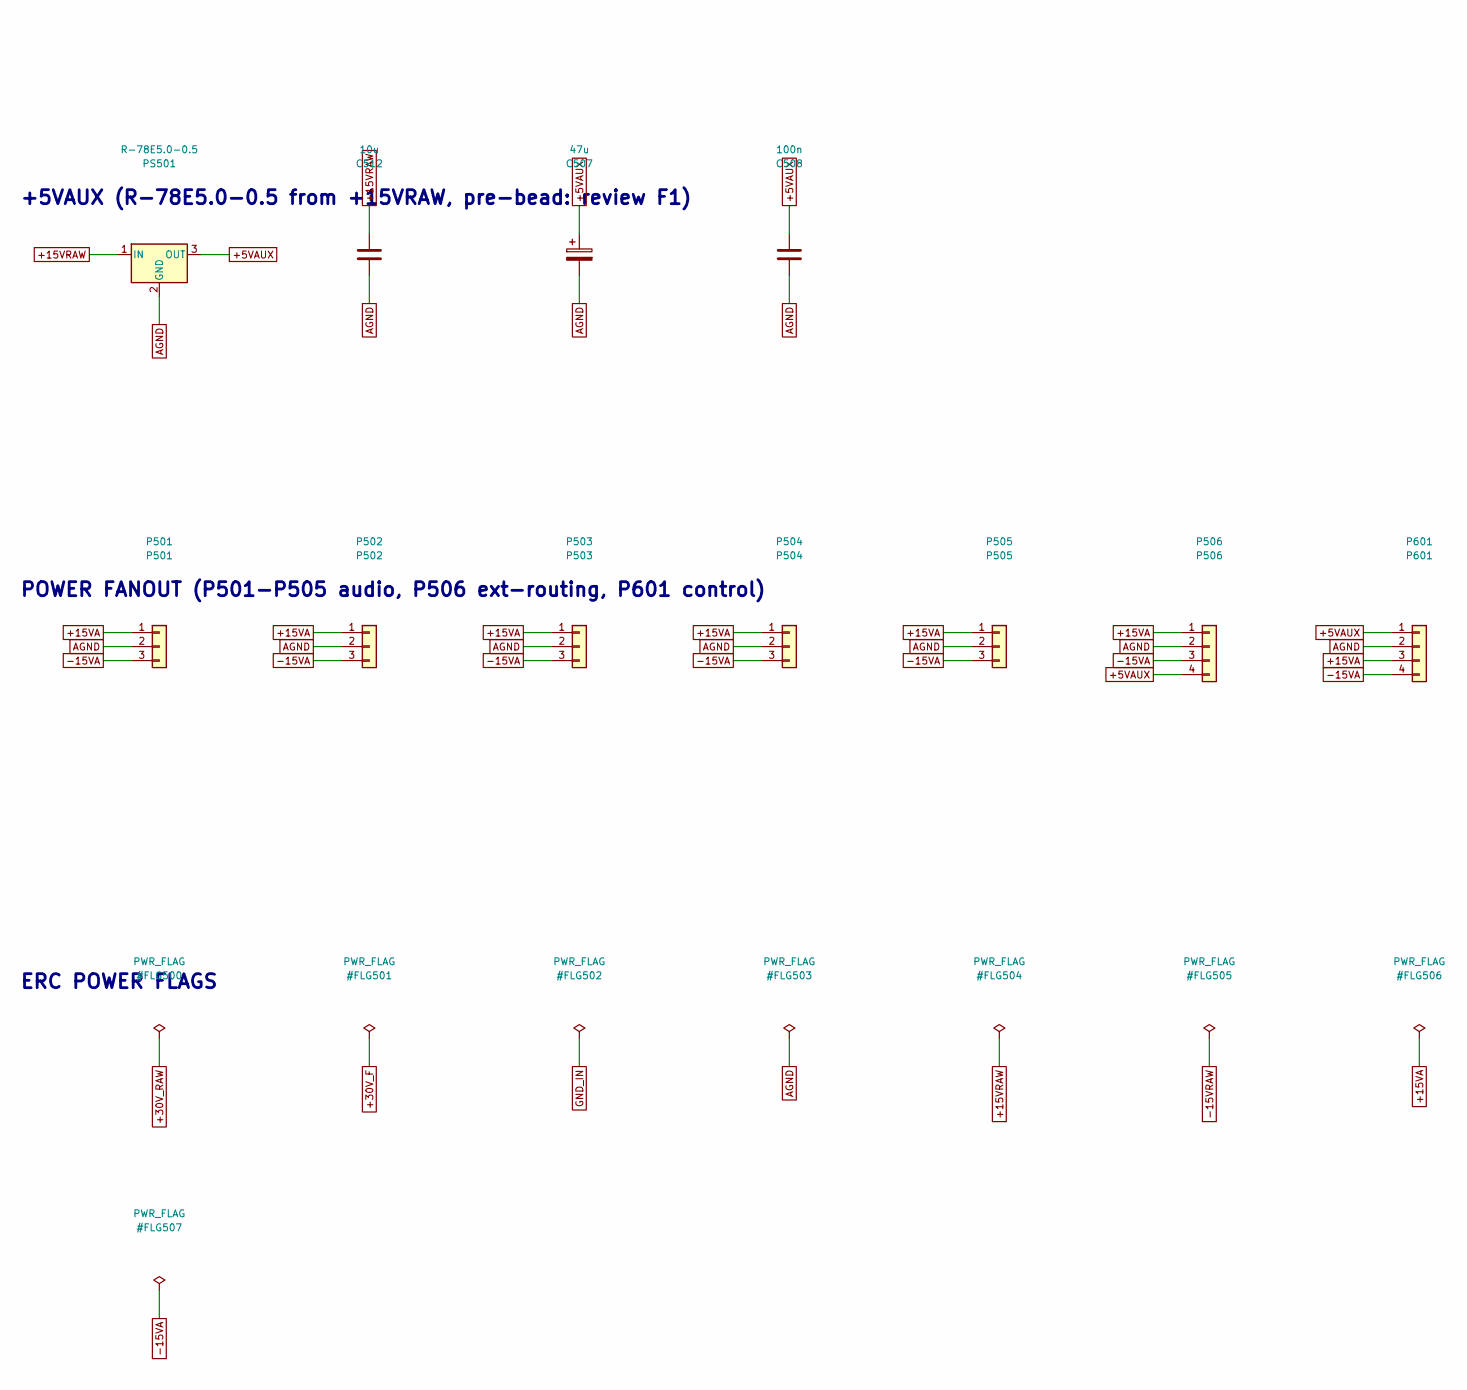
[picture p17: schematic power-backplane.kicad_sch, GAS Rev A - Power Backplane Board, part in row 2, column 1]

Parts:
C500: 220u; CP_Radial_D10.0mm_P5.00mm; Voltage 50V
C501, C504: 100u; CP_Radial_D6.3mm_P2.50mm; Voltage 25V
C502, C505, C512: 10u; C_1206_3216Metric
C503, C506: 100n; C_1206_3216Metric
C507: 47u; CP_Radial_D6.3mm_P2.50mm; Voltage 16V
C508: 100n; C_0805_2012Metric
C509: 100u; CP_Radial_D10.0mm_P5.00mm; Voltage 50V
C510, C511: 10u; CP_Radial_D6.3mm_P2.50mm; Voltage 25V
D500: SS34; D_SMA
F500: 1.1A PTC MF-MSMF110; Fuse_1812_4532Metric
FB500, FB501: BLM18PG471SN1; L_0603_1608Metric
P500: P500; JST_XH_B2B-XH-A_1x02_P2.50mm_Vertical
P501: P501; JST_VH_B3P-VH_1x03_P3.96mm_Vertical
P502: P502; JST_VH_B3P-VH_1x03_P3.96mm_Vertical
P503: P503; JST_VH_B3P-VH_1x03_P3.96mm_Vertical
P504: P504; JST_VH_B3P-VH_1x03_P3.96mm_Vertical
P505: P505; JST_VH_B3P-VH_1x03_P3.96mm_Vertical
P506: P506; JST_VH_B4P-VH_1x04_P3.96mm_Vertical
P601: P601; JST_VH_B4P-VH_1x04_P3.96mm_Vertical
PS500: URA2415YMD-10WR3; URA_YMD-10WR3
PS501: R-78E5.0-0.5; Converter_DCDC_RECOM_R-78E-0.5_THT
R500: 0; R_1206_3216Metric
TVS500: SMAJ33A; D_SMA

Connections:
+5VAUX: C507.1, C508.1, P506.4, P601.1, PS501.3 (OUT)
+15VA: C501.1, C502.1, C503.1, FB500.2, P501.1, P502.1, P503.1, P504.1, P505.1, P506.1, P601.3
+15VRAW: C510.1, C512.1, FB500.1, PS500.3, PS501.1 (IN)
+30V_D: D500.1 (K), F500.1
+30V_F: C500.1, C509.1, F500.2, PS500.2, TVS500.1 (A1)
+30V_RAW: D500.2 (A), P500.1
-15VA: C504.2, C505.1, C506.1, FB501.2, P501.3, P502.3, P503.3, P504.3, P505.3, P506.3, P601.4
-15VRAW: C511.2, FB501.1, PS500.5
AGND: C501.2, C502.2, C503.2, C504.1, C505.2, C506.2, C507.2, C508.2, C510.2, C511.1, C512.2, P501.2, P502.2, P503.2, P504.2, P505.2, P506.2, P601.2, PS500.4, PS501.2 (GND), R500.2
GND_IN: C500.2, C509.2, P500.2, PS500.1, R500.1, TVS500.2 (A2)

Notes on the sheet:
DC ENTRY + PROTECTION (+30VDC wall adapter)
ISOLATED +/-15V CONVERSION (URA2415YMD-10WR3)
RAIL RIPPLE FILTERS (bead + 100u + 10u + 100n per rail)
+5VAUX (R-78E5.0-0.5 from +15VRAW, pre-bead: review F1)
POWER FANOUT (P501-P505 audio, P506 ext-routing, P601 control)
ERC POWER FLAGS

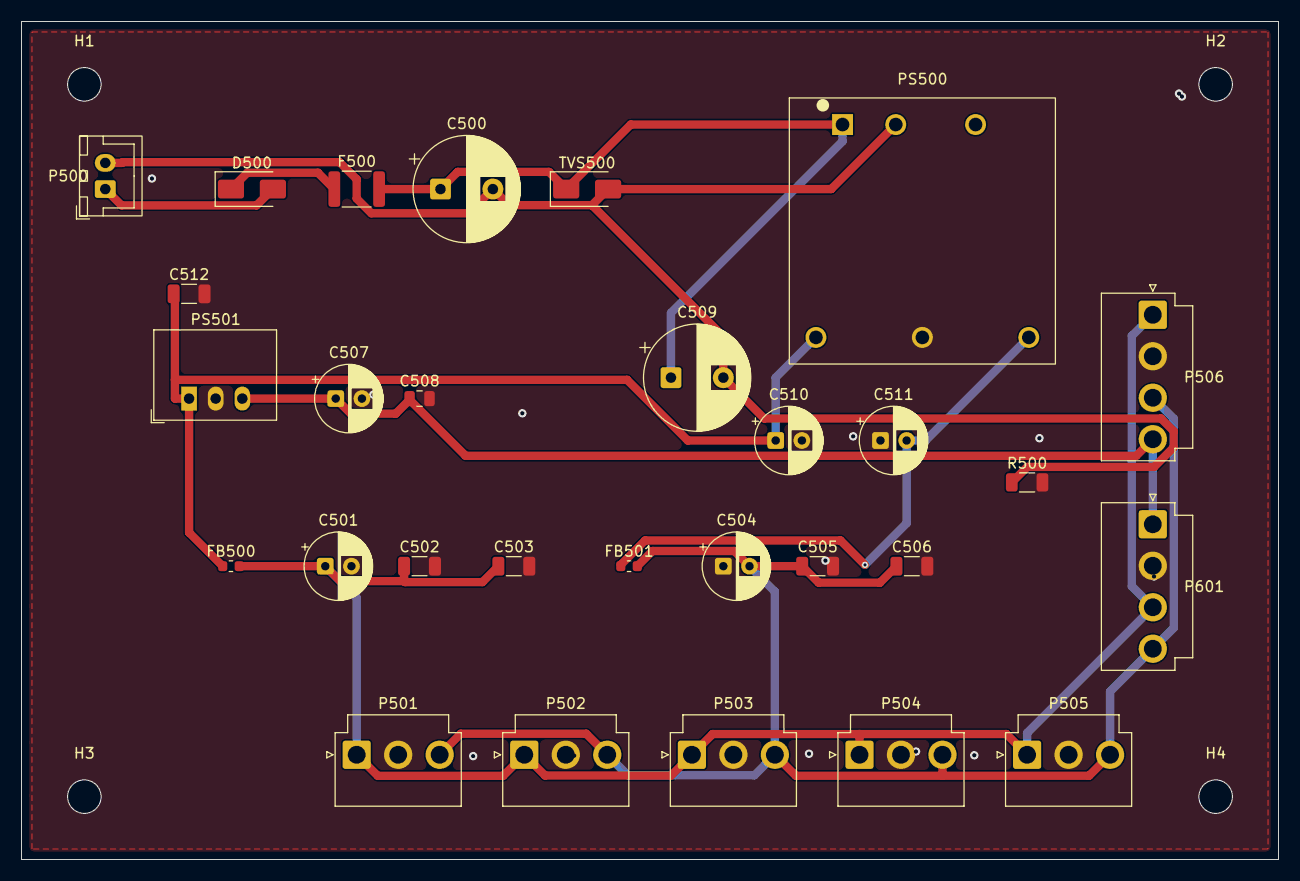
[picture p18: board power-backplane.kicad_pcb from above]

Board: 2 copper layers, 120.0 x 80.0 mm, 33 parts (0 on the bottom side), 10 nets.

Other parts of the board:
H1, H2, H3, H4: M3; MountingHole_3.2mm_M3

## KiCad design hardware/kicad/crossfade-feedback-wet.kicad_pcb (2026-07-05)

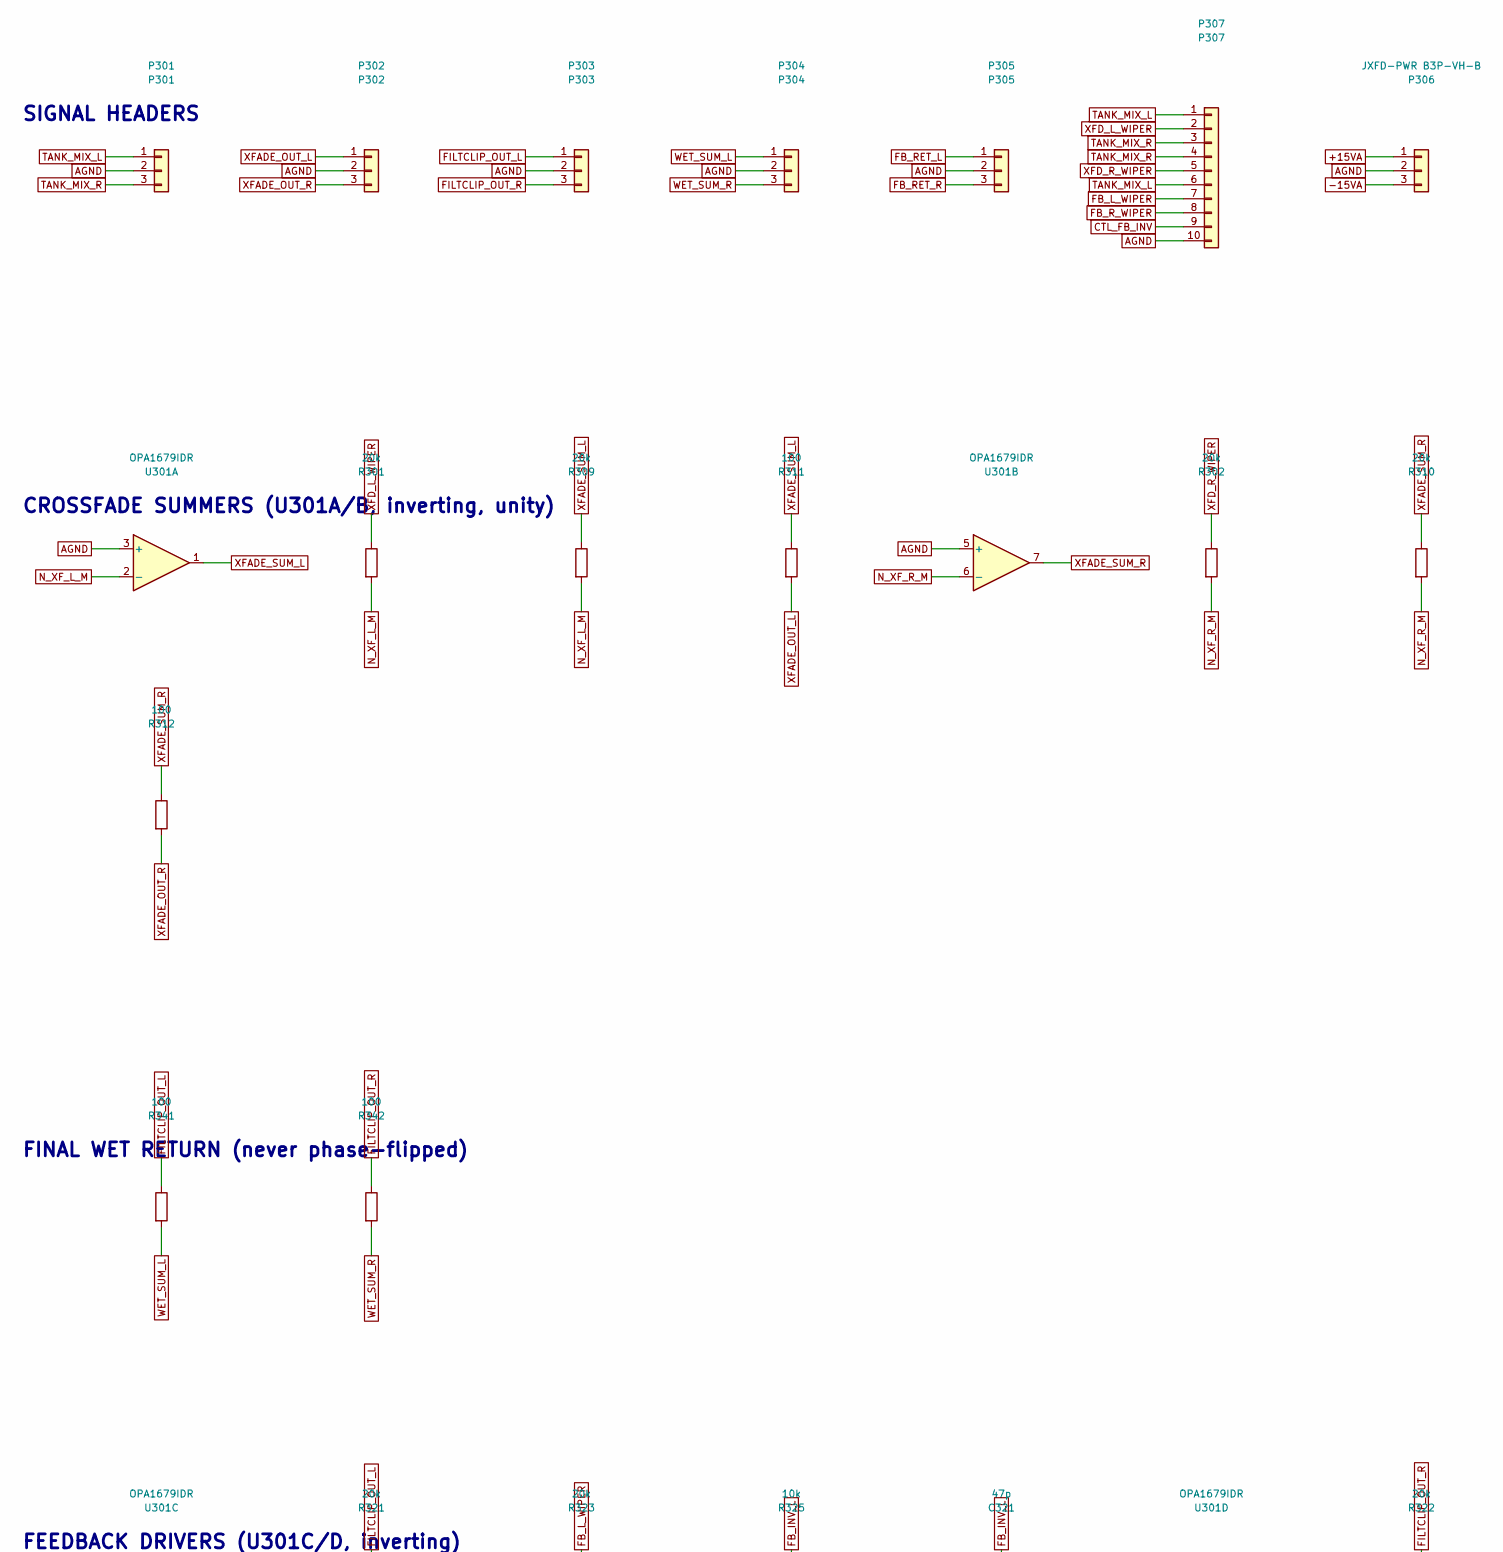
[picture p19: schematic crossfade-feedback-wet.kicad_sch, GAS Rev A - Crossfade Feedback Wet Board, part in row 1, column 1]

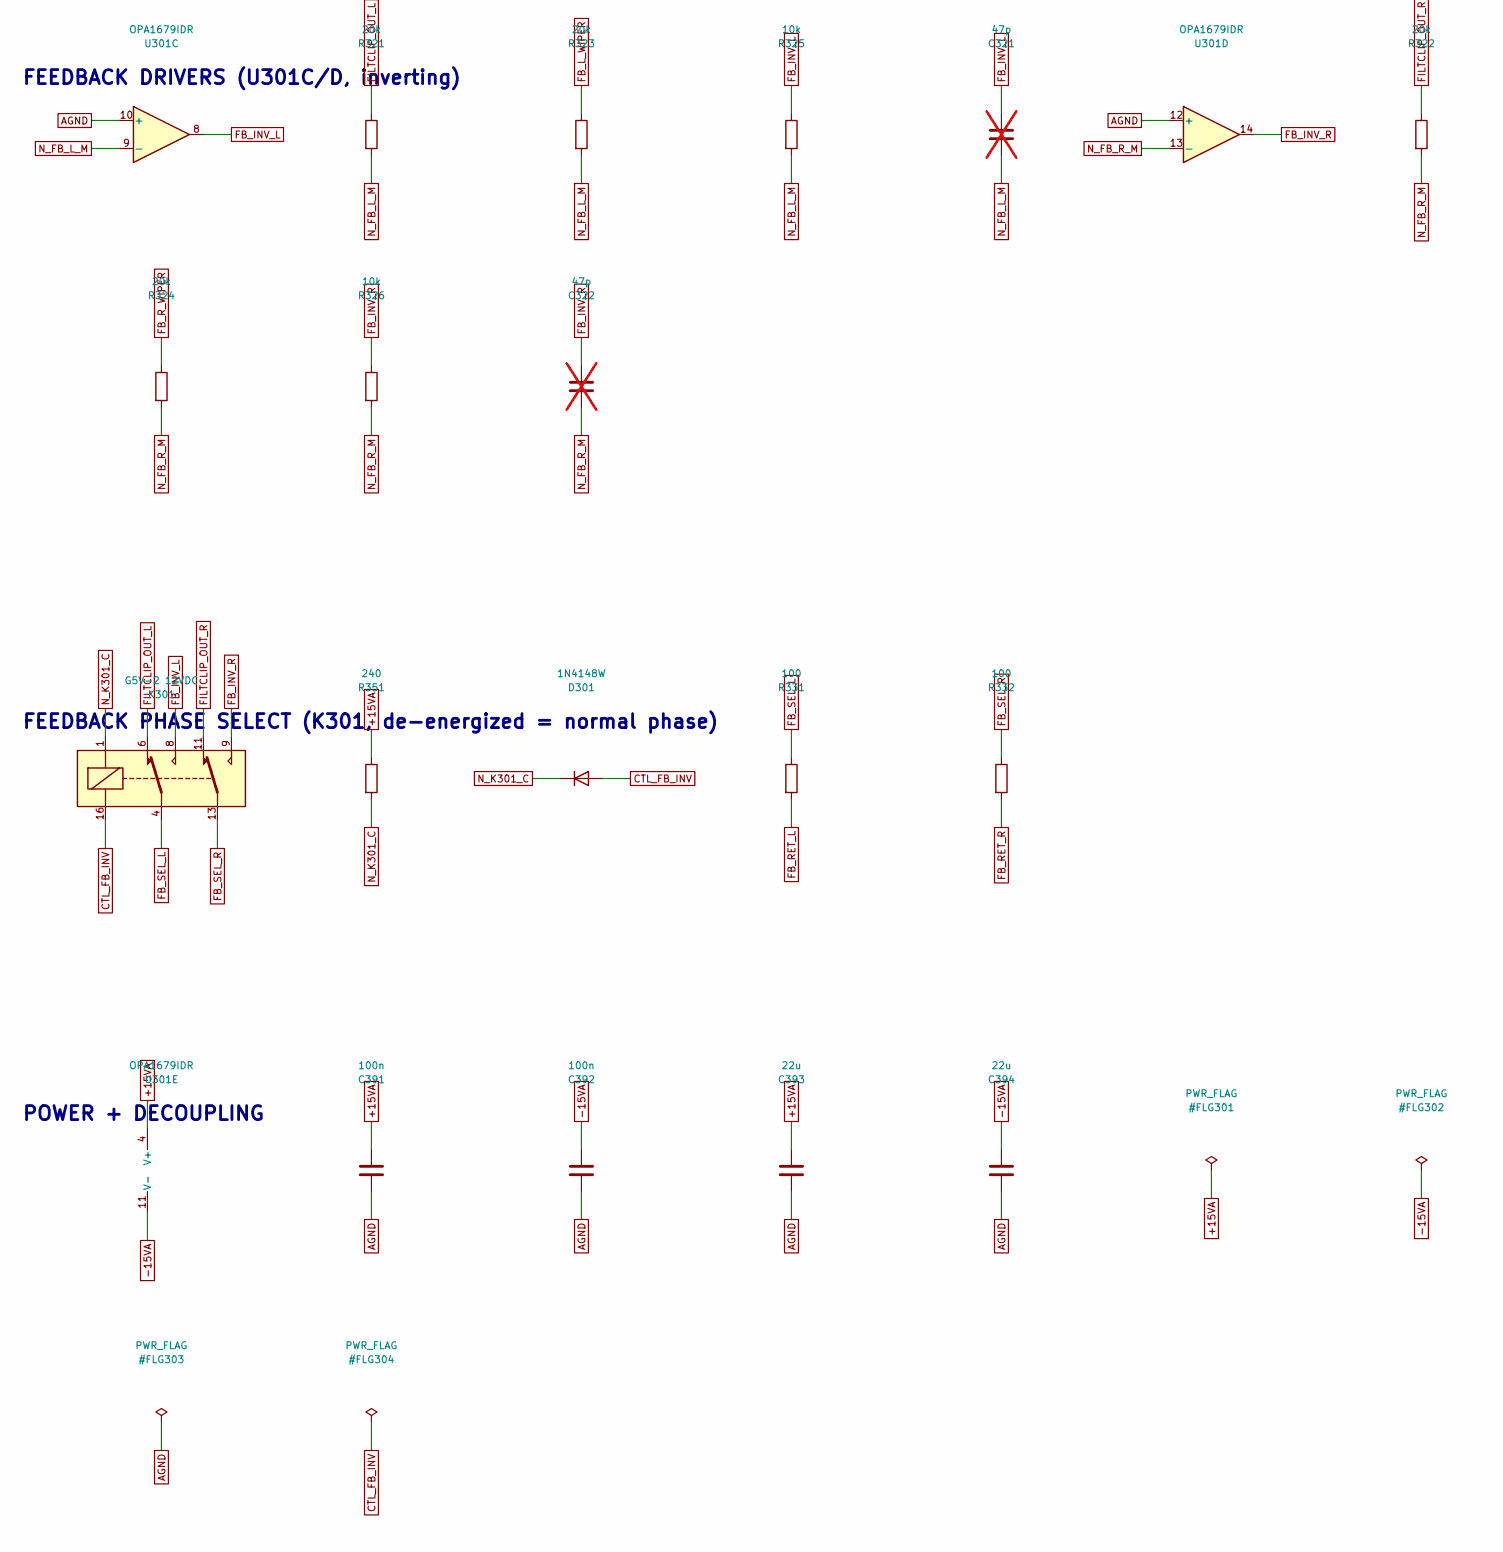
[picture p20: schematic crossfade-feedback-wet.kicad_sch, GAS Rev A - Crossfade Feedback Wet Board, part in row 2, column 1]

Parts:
C321, C322: 47p; C_0805_2012Metric; not fitted
C391, C392: 100n; C_0805_2012Metric
C393, C394: 22u; C_1210_3225Metric
D301: 1N4148W; D_SOD-123
K301: G5V-2 12VDC; Relay_DPDT_Omron_G5V-2
P301: P301; JST_XH_B3B-XH-A_1x03_P2.50mm_Vertical
P302: P302; JST_XH_B3B-XH-A_1x03_P2.50mm_Vertical
P303: P303; JST_XH_B3B-XH-A_1x03_P2.50mm_Vertical
P304: P304; JST_XH_B3B-XH-A_1x03_P2.50mm_Vertical
P305: P305; JST_XH_B3B-XH-A_1x03_P2.50mm_Vertical
P306: JXFD-PWR B3P-VH-B; JST_VH_B3P-VH_1x03_P3.96mm_Vertical
P307: P307; JST_XH_B10B-XH-A_1x10_P2.50mm_Vertical
R301, R302, R309, R310, R321, R322, R323, R324: 20k; R_0805_2012Metric
R311, R312, R331, R332, R341, R342: 100; R_0805_2012Metric
R325, R326: 10k; R_0805_2012Metric
R351: 240; R_1206_3216Metric
U301: OPA1679IDR; SOIC-14_3.9x8.7mm_P1.27mm

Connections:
+15VA: C391.1, C393.1, P306.1, R351.1, U301.4 (V+)
-15VA: C392.1, C394.1, P306.3, U301.11 (V-)
AGND: C391.2, C392.2, C393.2, C394.2, P301.2, P302.2, P303.2, P304.2, P305.2, P306.2, P307.10, U301.3 (+), U301.5 (+), U301.10 (+), U301.12 (+)
CTL_FB_INV: D301.2 (A), K301.16, P307.9
FB_INV_L: C321.1, K301.8, R325.1, U301.8
FB_INV_R: C322.1, K301.9, R326.1, U301.14
FB_L_WIPER: P307.7, R323.1
FB_RET_L: P305.1, R331.2
FB_RET_R: P305.3, R332.2
FB_R_WIPER: P307.8, R324.1
FB_SEL_L: K301.4, R331.1
FB_SEL_R: K301.13, R332.1
FILTCLIP_OUT_L: K301.6, P303.1, R321.1, R341.1
FILTCLIP_OUT_R: K301.11, P303.3, R322.1, R342.1
N_FB_L_M: C321.2, R321.2, R323.2, R325.2, U301.9 (-)
N_FB_R_M: C322.2, R322.2, R324.2, R326.2, U301.13 (-)
N_K301_C: D301.1 (K), K301.1, R351.2
N_XF_L_M: R301.2, R309.2, U301.2 (-)
N_XF_R_M: R302.2, R310.2, U301.6 (-)
TANK_MIX_L: P301.1, P307.1, P307.6
TANK_MIX_R: P301.3, P307.3, P307.4
WET_SUM_L: P304.1, R341.2
WET_SUM_R: P304.3, R342.2
XFADE_OUT_L: P302.1, R311.2
XFADE_OUT_R: P302.3, R312.2
XFADE_SUM_L: R309.1, R311.1, U301.1
XFADE_SUM_R: R310.1, R312.1, U301.7
XFD_L_WIPER: P307.2, R301.1
XFD_R_WIPER: P307.5, R302.1

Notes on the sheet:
SIGNAL HEADERS
CROSSFADE SUMMERS (U301A/B, inverting, unity)
FINAL WET RETURN (never phase-flipped)
FEEDBACK DRIVERS (U301C/D, inverting)
FEEDBACK PHASE SELECT (K301, de-energized = normal phase)
POWER + DECOUPLING

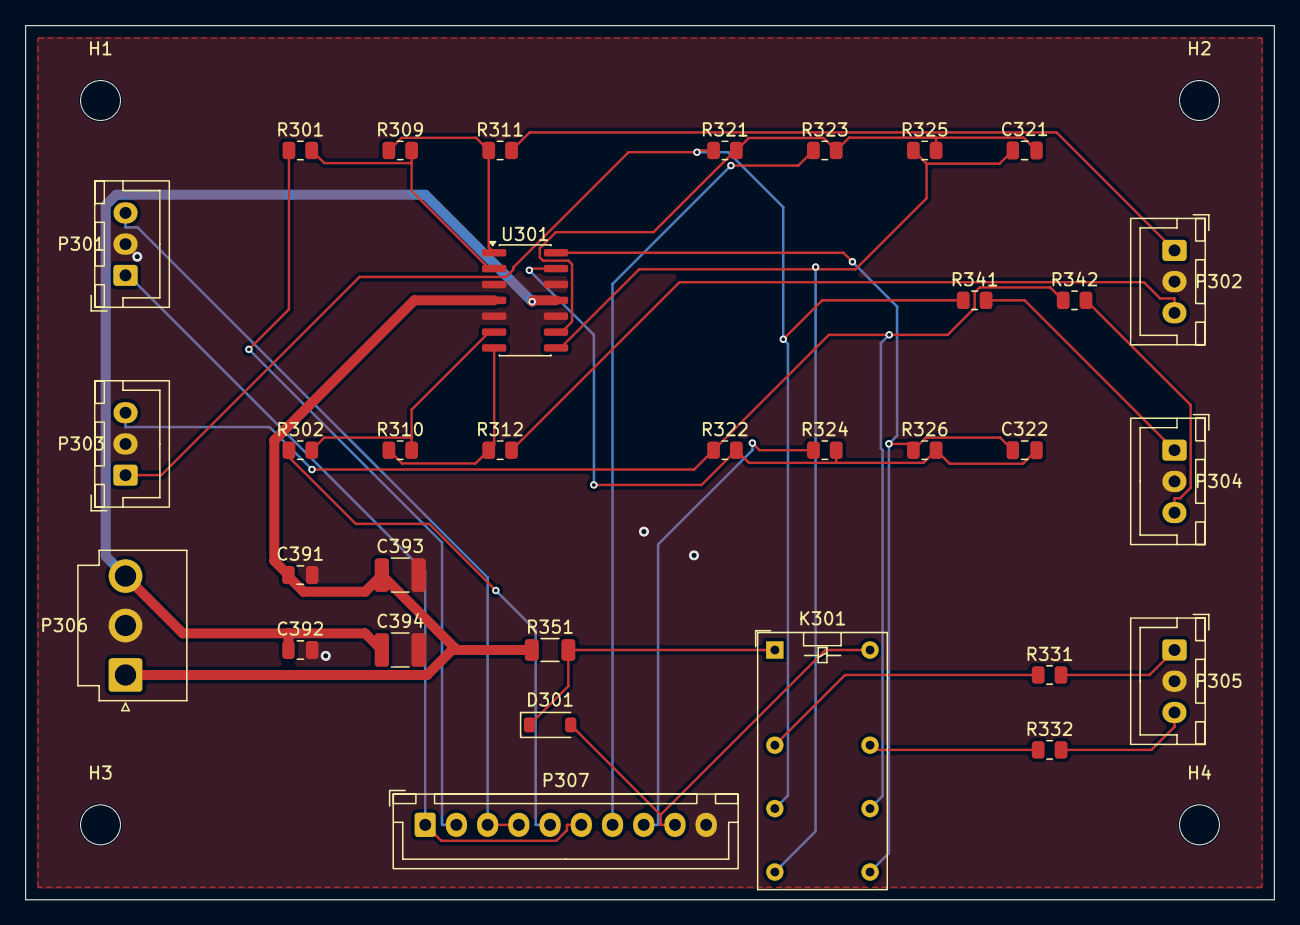
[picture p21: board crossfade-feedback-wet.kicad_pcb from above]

Board: 2 copper layers, 100.0 x 70.0 mm, 37 parts (0 on the bottom side), 29 nets.

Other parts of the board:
H1, H2, H3, H4: M3; MountingHole_3.2mm_M3

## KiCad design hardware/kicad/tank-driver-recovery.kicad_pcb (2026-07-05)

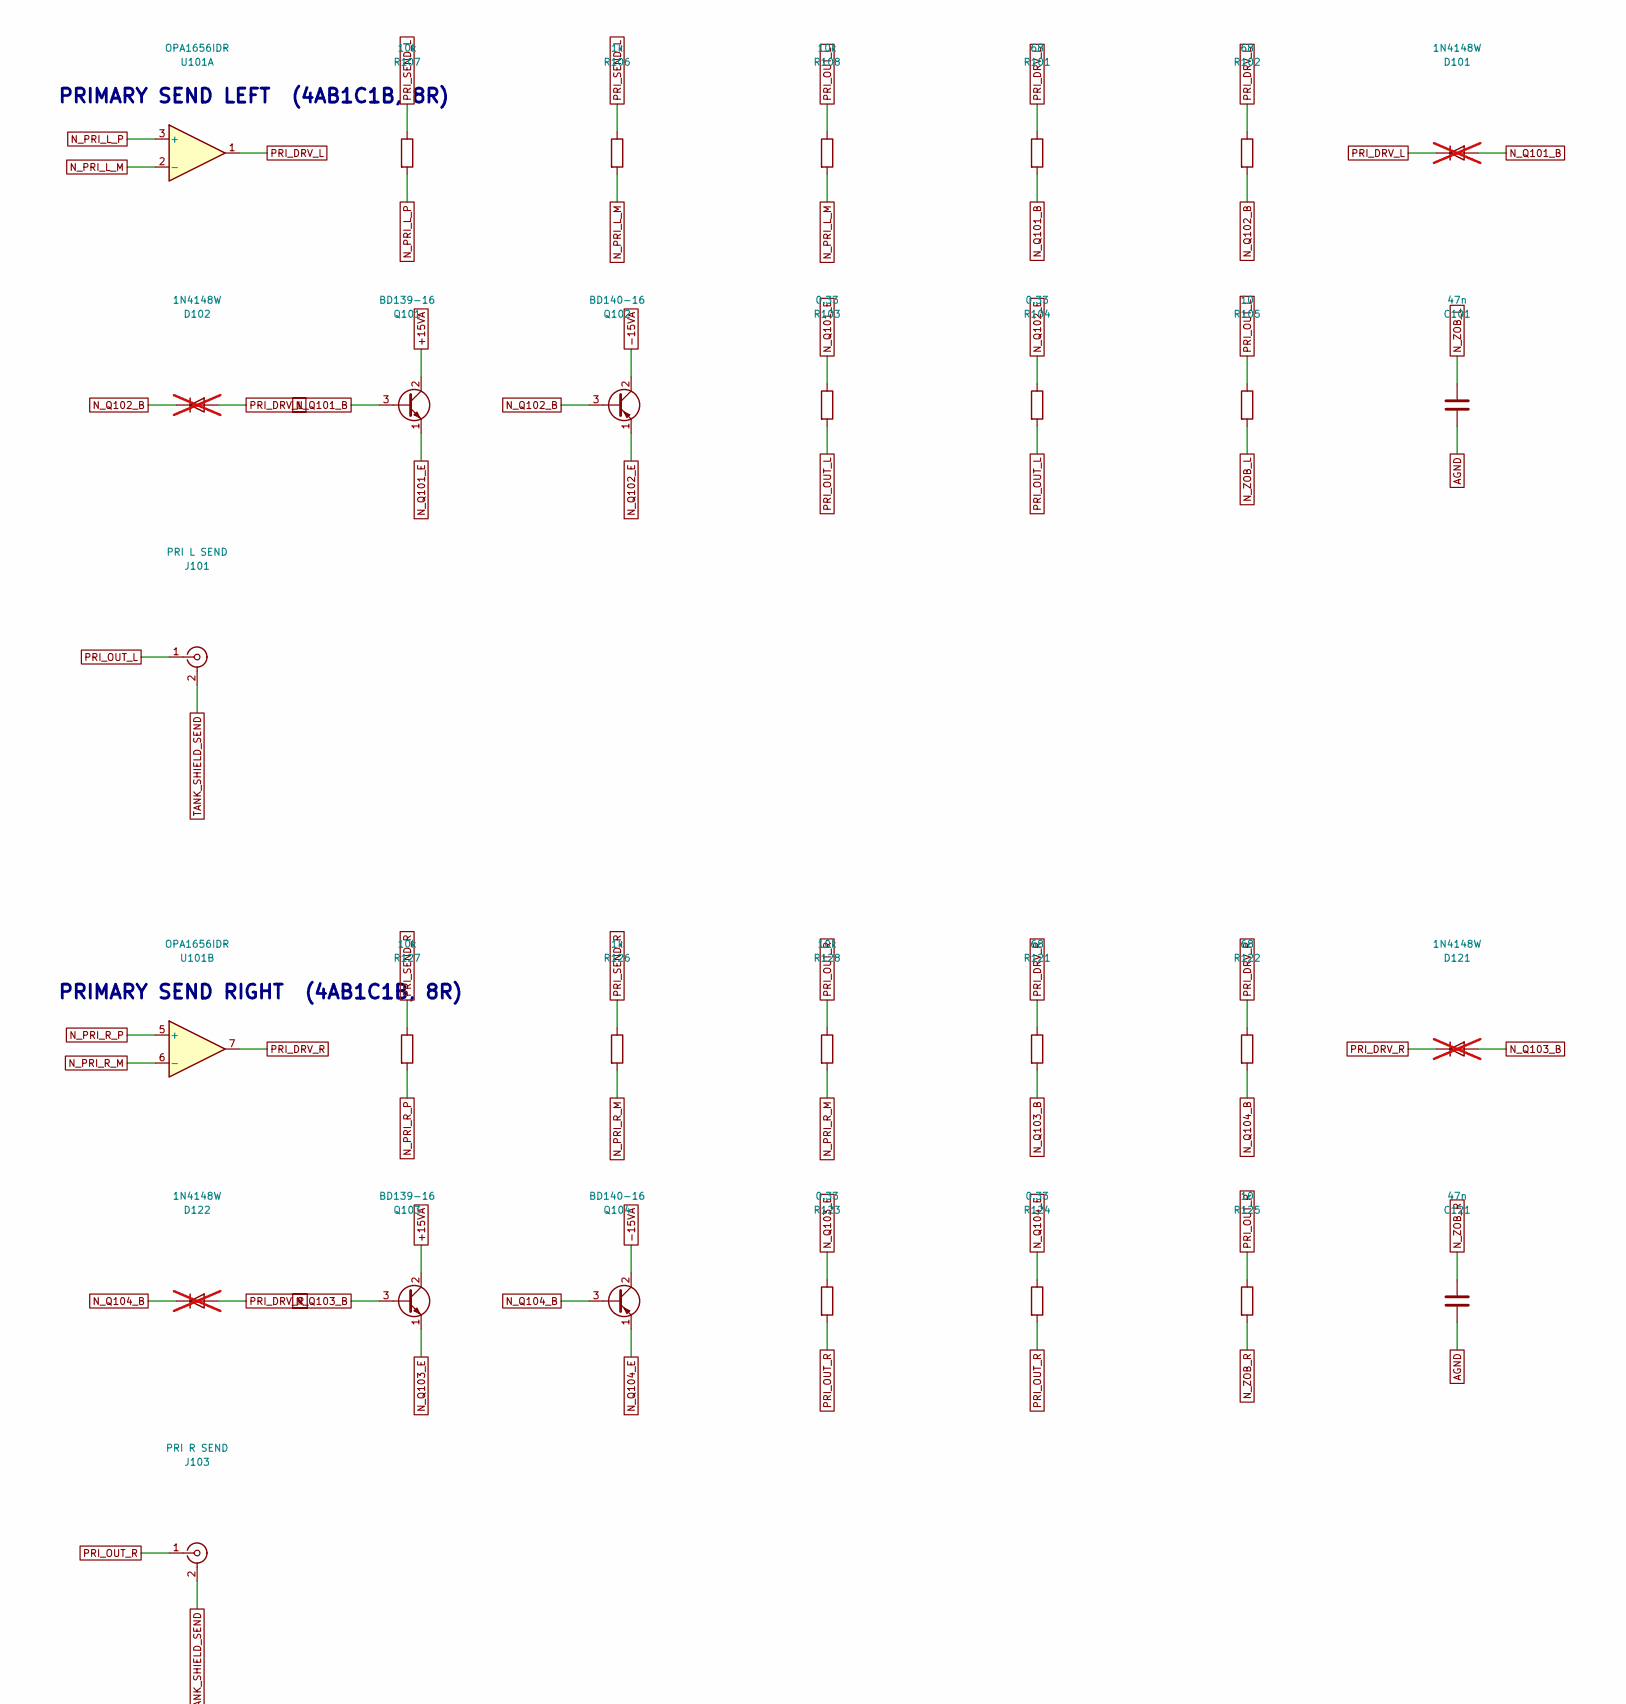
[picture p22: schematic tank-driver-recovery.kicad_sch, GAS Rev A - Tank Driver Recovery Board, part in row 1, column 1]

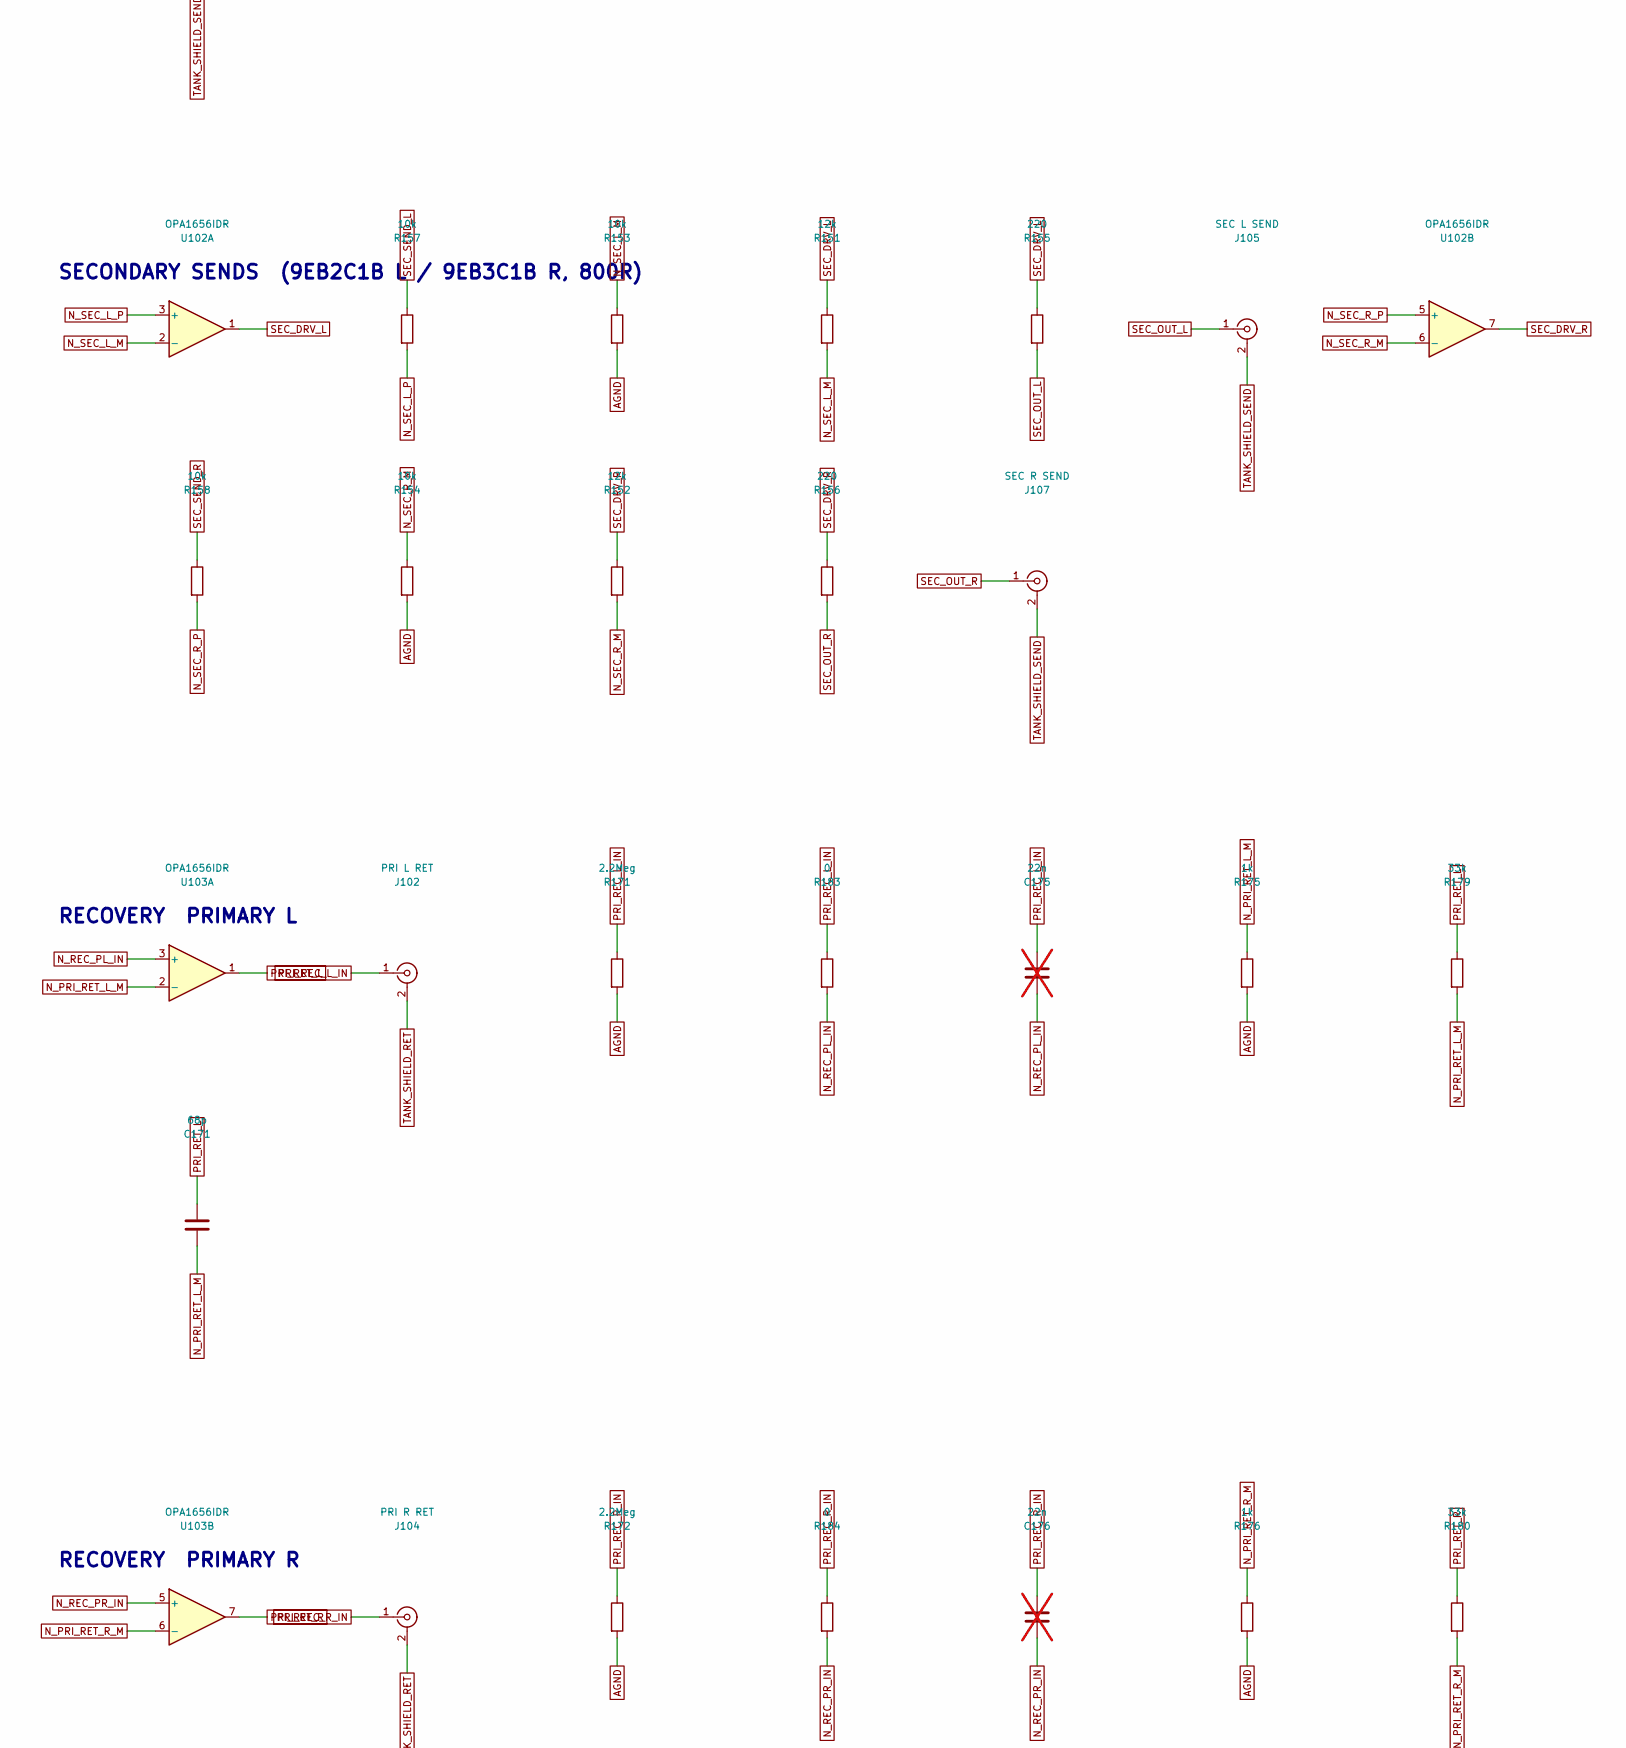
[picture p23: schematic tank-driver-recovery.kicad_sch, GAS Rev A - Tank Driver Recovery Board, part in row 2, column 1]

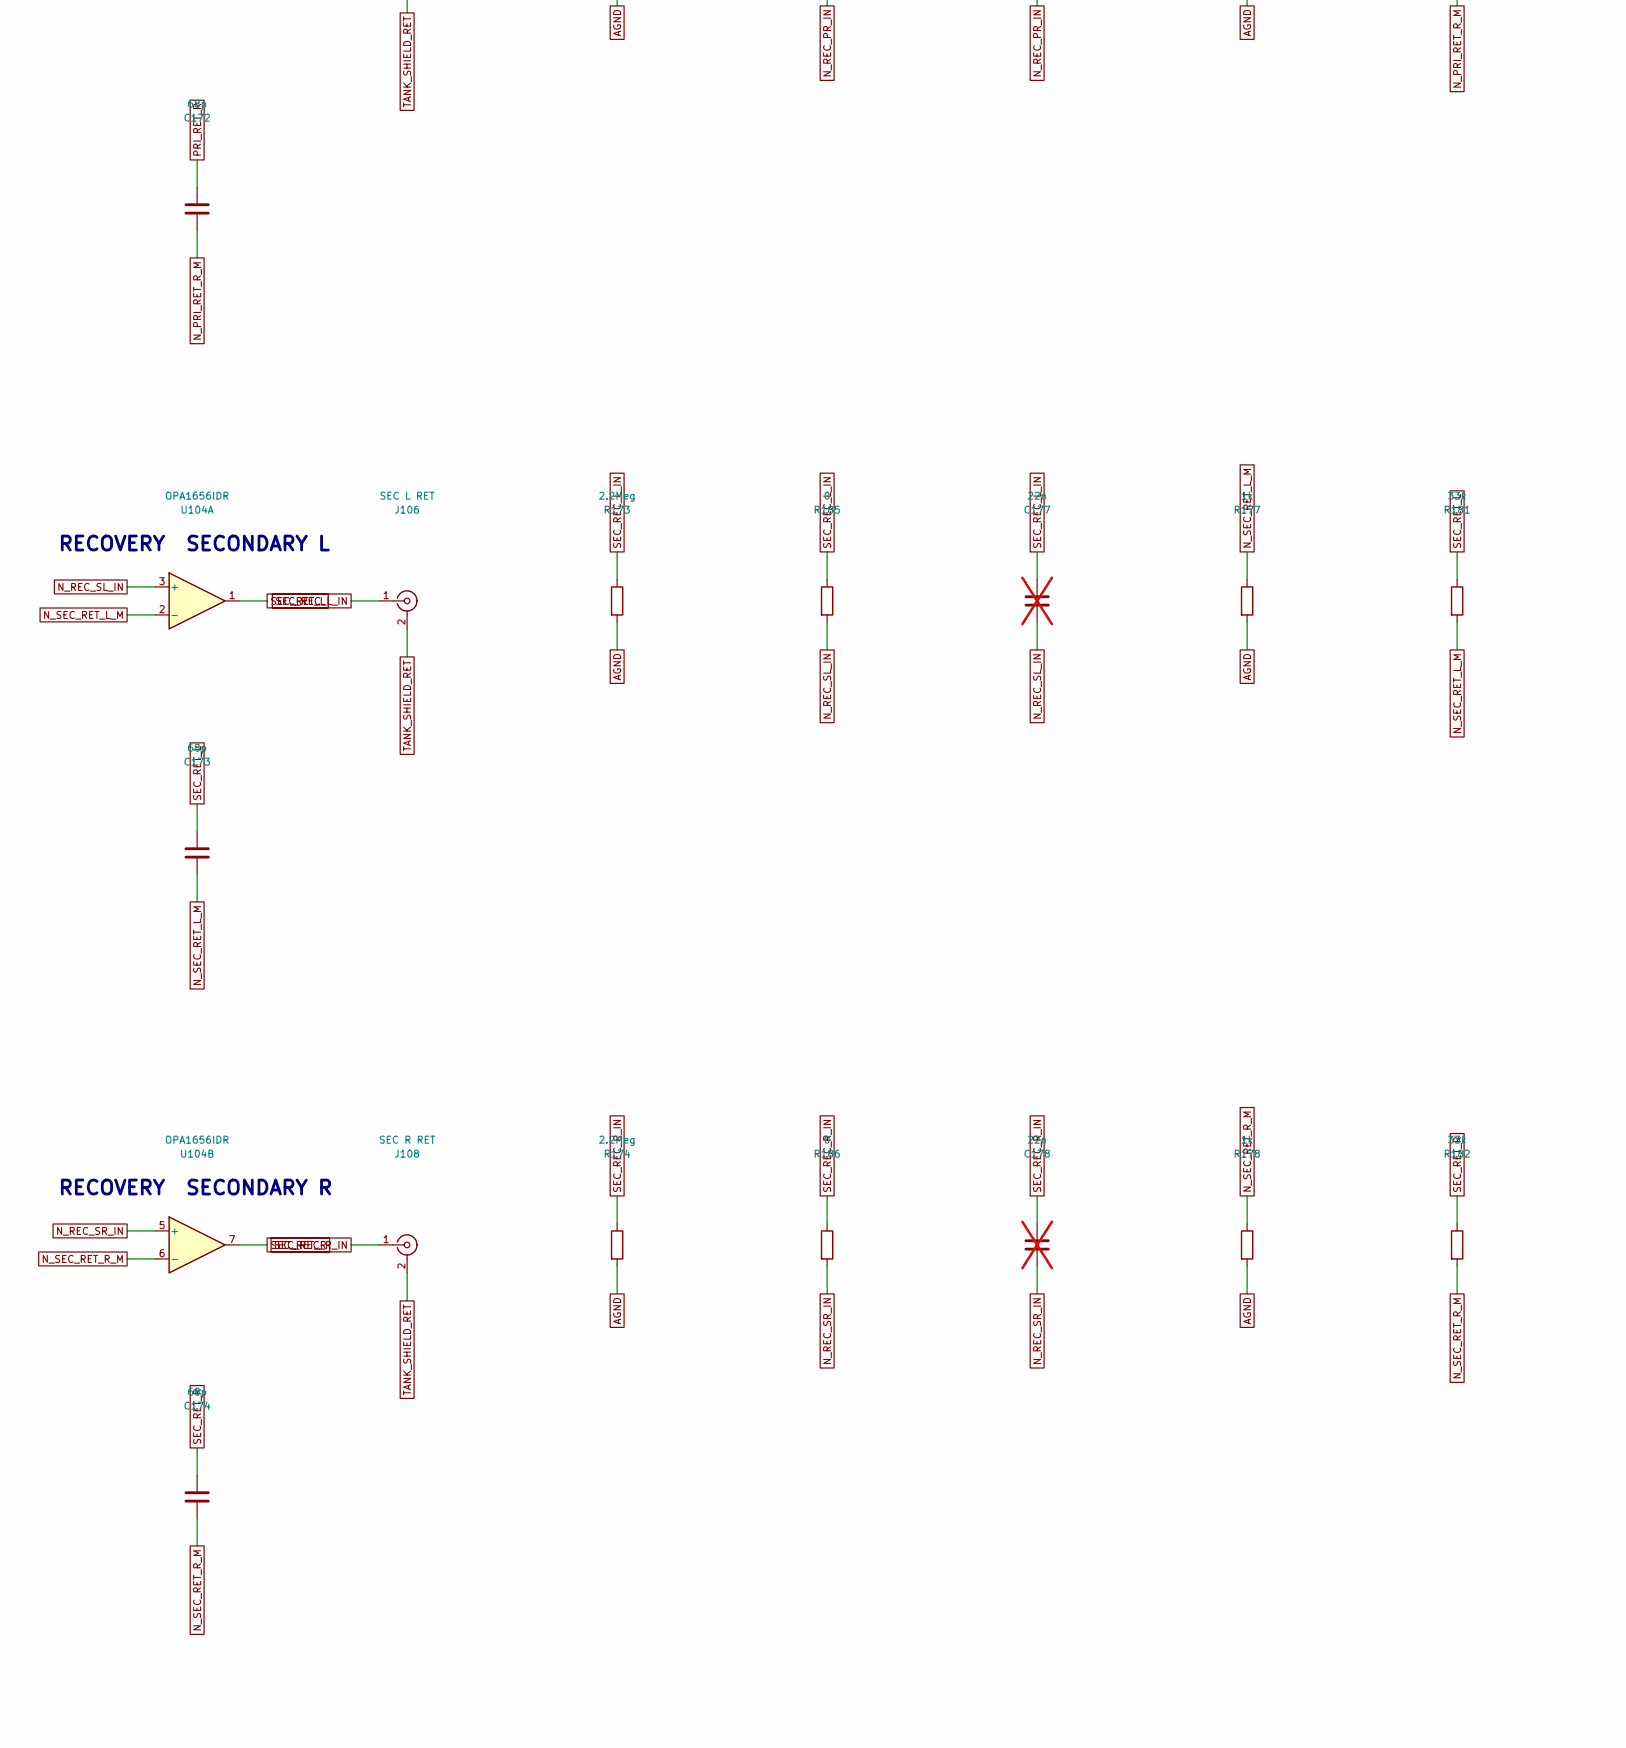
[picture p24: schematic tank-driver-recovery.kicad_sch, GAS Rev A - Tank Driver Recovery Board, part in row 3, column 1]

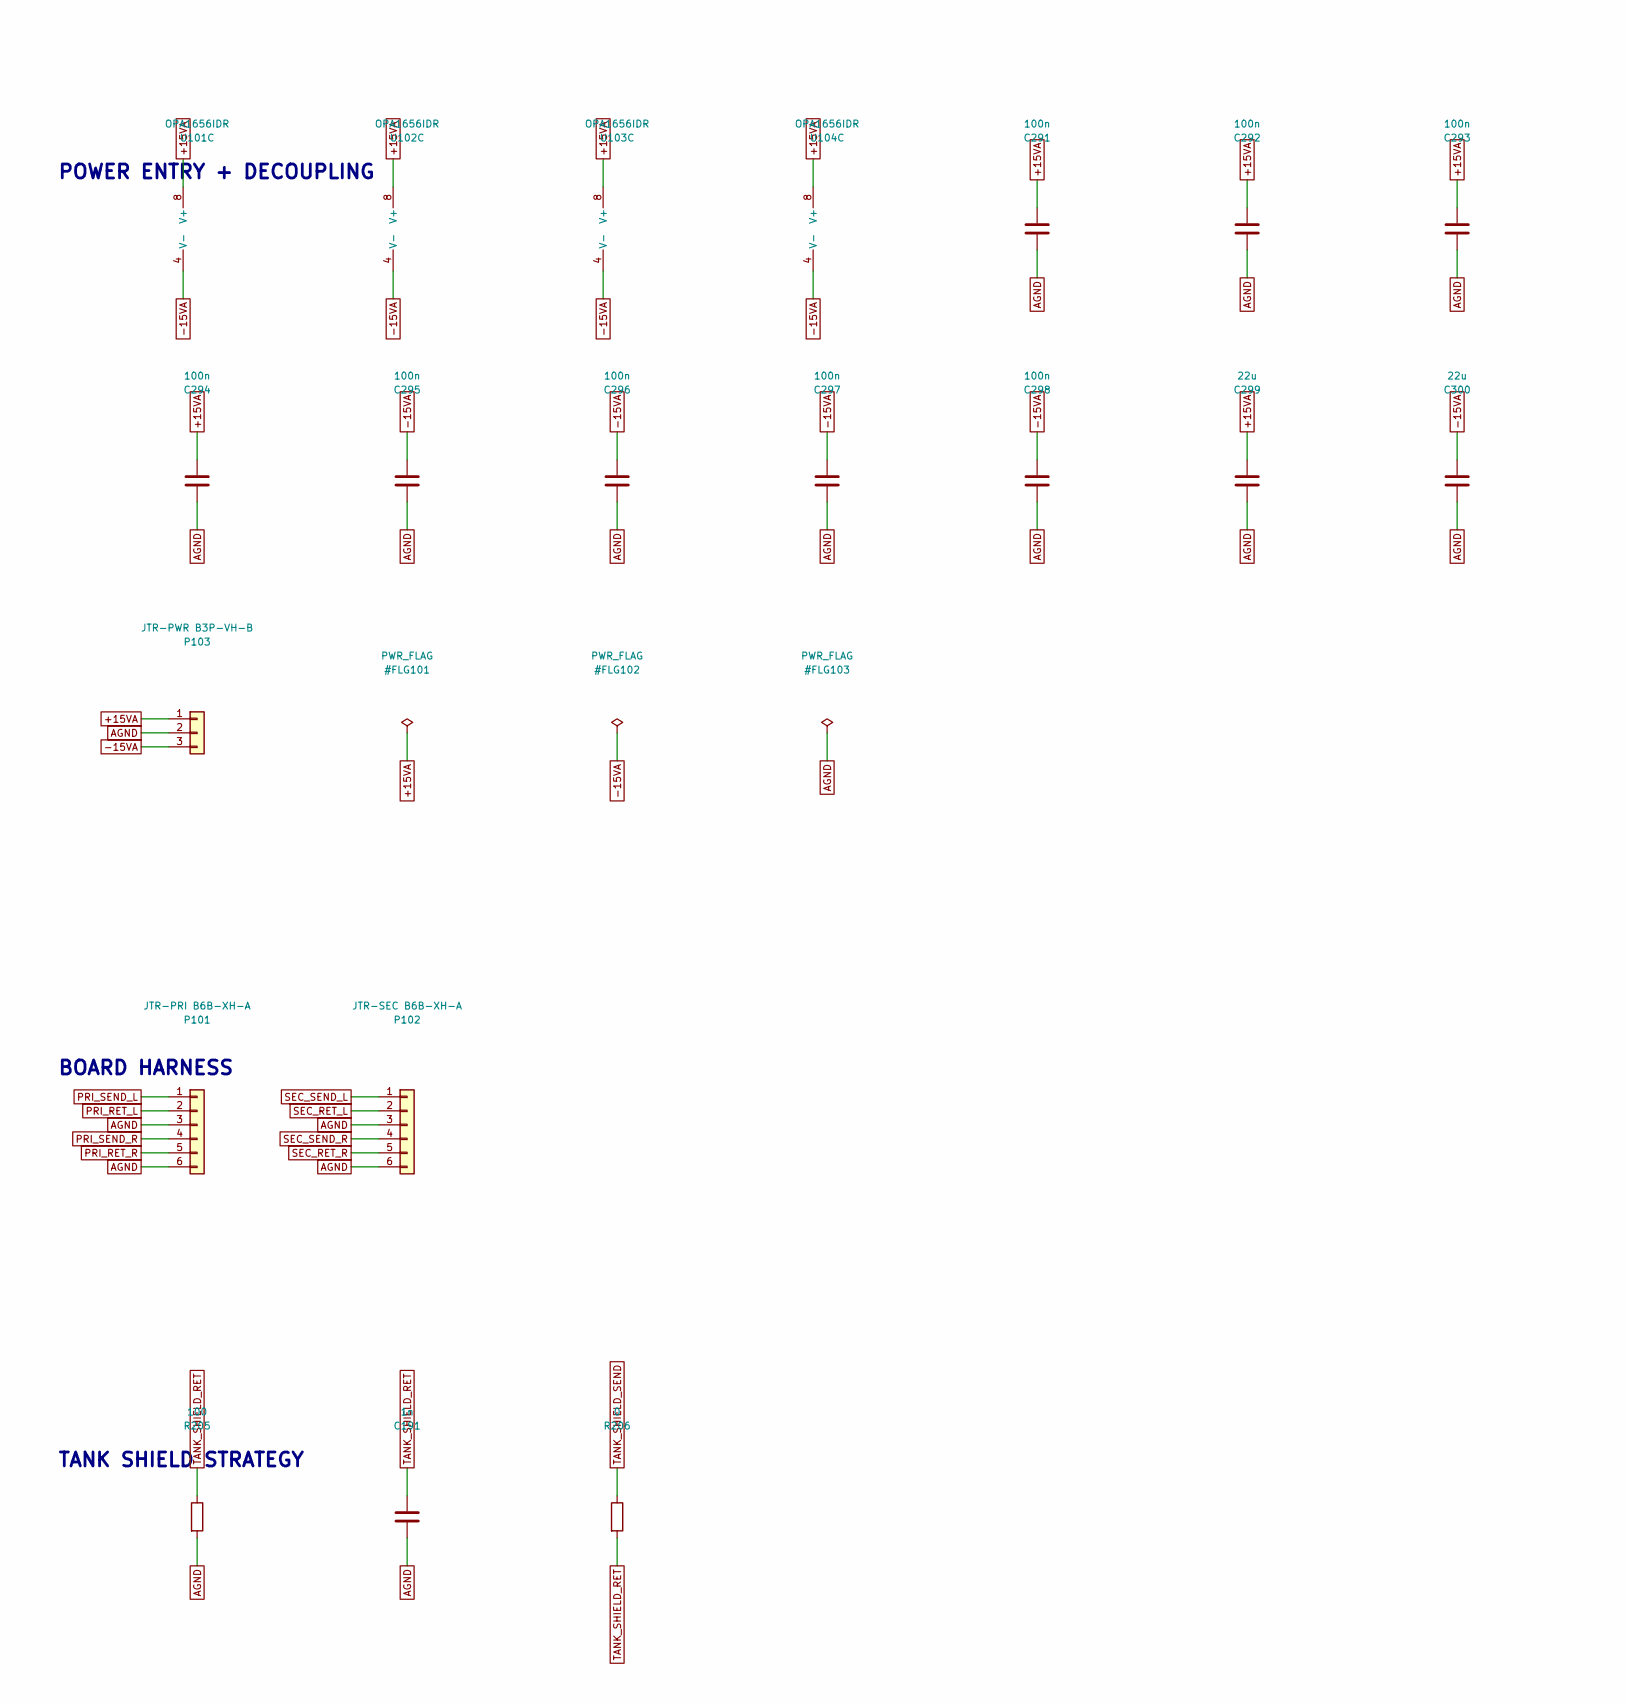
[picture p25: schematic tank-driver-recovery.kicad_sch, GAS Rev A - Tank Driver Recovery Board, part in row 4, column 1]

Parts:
C101, C121: 47n; C_1210_3225Metric
C171, C172, C173, C174: 68p; C_0805_2012Metric
C175, C176, C177, C178: 22n; C_1206_3216Metric; not fitted
C191: 1n; C_0805_2012Metric
C291, C292, C293, C294, C295, C296, C297, C298: 100n; C_0805_2012Metric
C299, C300: 22u; C_1210_3225Metric
D101, D102, D121, D122: 1N4148W; D_SOD-123; not fitted
J101: PRI L SEND; JST_XH_B2B-XH-A_1x02_P2.50mm_Vertical
J102: PRI L RET; JST_XH_B2B-XH-A_1x02_P2.50mm_Vertical
J103: PRI R SEND; JST_XH_B2B-XH-A_1x02_P2.50mm_Vertical
J104: PRI R RET; JST_XH_B2B-XH-A_1x02_P2.50mm_Vertical
J105: SEC L SEND; JST_XH_B2B-XH-A_1x02_P2.50mm_Vertical
J106: SEC L RET; JST_XH_B2B-XH-A_1x02_P2.50mm_Vertical
J107: SEC R SEND; JST_XH_B2B-XH-A_1x02_P2.50mm_Vertical
J108: SEC R RET; JST_XH_B2B-XH-A_1x02_P2.50mm_Vertical
P101: JTR-PRI B6B-XH-A; JST_XH_B6B-XH-A_1x06_P2.50mm_Vertical
P102: JTR-SEC B6B-XH-A; JST_XH_B6B-XH-A_1x06_P2.50mm_Vertical
P103: JTR-PWR B3P-VH-B; JST_VH_B3P-VH_1x03_P3.96mm_Vertical
Q101, Q103: BD139-16; TO-126-3_Vertical
Q102, Q104: BD140-16; TO-126-3_Vertical
R101, R102, R121, R122: 68; R_0805_2012Metric
R103, R104, R123, R124: 0.33; R_2512_6332Metric
R105, R125: 10; R_1206_3216Metric
R106, R126, R175, R176, R177, R178: 1k; R_0805_2012Metric
R107, R108, R127, R128, R153, R154, R157, R158: 10k; R_0805_2012Metric
R151, R152: 12k; R_0805_2012Metric
R155, R156: 220; R_0805_2012Metric
R171, R172, R173, R174: 2.2Meg; R_0805_2012Metric
R179, R180, R181, R182: 33k; R_0805_2012Metric
R183, R184, R185, R186: 0; R_0805_2012Metric
R205: 100; R_1206_3216Metric
R206: 0; R_1206_3216Metric
U101, U102, U103, U104: OPA1656IDR; SOIC-8_3.9x4.9mm_P1.27mm

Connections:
+15VA: C291.1, C292.1, C293.1, C294.1, C299.1, P103.1, Q101.2 (C), Q103.2 (C), U101.8 (V+), U102.8 (V+), U103.8 (V+), U104.8 (V+)
-15VA: C295.1, C296.1, C297.1, C298.1, C300.1, P103.3, Q102.2 (C), Q104.2 (C), U101.4 (V-), U102.4 (V-), U103.4 (V-), U104.4 (V-)
AGND: C101.2, C121.2, C191.2, C291.2, C292.2, C293.2, C294.2, C295.2, C296.2, C297.2, C298.2, C299.2, C300.2, P101.3, P101.6, P102.3, P102.6, P103.2, R153.2, R154.2, R171.2, R172.2, R173.2, R174.2, R175.2, R176.2, R177.2, R178.2, R205.2
N_PRI_L_M: R106.2, R108.2, U101.2 (-)
N_PRI_L_P: R107.2, U101.3 (+)
N_PRI_RET_L_M: C171.2, R175.1, R179.2, U103.2 (-)
N_PRI_RET_R_M: C172.2, R176.1, R180.2, U103.6 (-)
N_PRI_R_M: R126.2, R128.2, U101.6 (-)
N_PRI_R_P: R127.2, U101.5 (+)
N_Q101_B: D101.2 (A), Q101.3 (B), R101.2
N_Q101_E: Q101.1 (E), R103.1
N_Q102_B: D102.1 (K), Q102.3 (B), R102.2
N_Q102_E: Q102.1 (E), R104.1
N_Q103_B: D121.2 (A), Q103.3 (B), R121.2
N_Q103_E: Q103.1 (E), R123.1
N_Q104_B: D122.1 (K), Q104.3 (B), R122.2
N_Q104_E: Q104.1 (E), R124.1
N_REC_PL_IN: C175.2, R183.2, U103.3 (+)
N_REC_PR_IN: C176.2, R184.2, U103.5 (+)
N_REC_SL_IN: C177.2, R185.2, U104.3 (+)
N_REC_SR_IN: C178.2, R186.2, U104.5 (+)
N_SEC_L_M: R151.2, R153.1, U102.2 (-)
N_SEC_L_P: R157.2, U102.3 (+)
N_SEC_RET_L_M: C173.2, R177.1, R181.2, U104.2 (-)
N_SEC_RET_R_M: C174.2, R178.1, R182.2, U104.6 (-)
N_SEC_R_M: R152.2, R154.1, U102.6 (-)
N_SEC_R_P: R158.2, U102.5 (+)
N_ZOB_L: C101.1, R105.2
N_ZOB_R: C121.1, R125.2
PRI_DRV_L: D101.1 (K), D102.2 (A), R101.1, R102.1, U101.1
PRI_DRV_R: D121.1 (K), D122.2 (A), R121.1, R122.1, U101.7
PRI_OUT_L: J101.1 (In), R103.2, R104.2, R105.1, R108.1
PRI_OUT_R: J103.1 (In), R123.2, R124.2, R125.1, R128.1
PRI_REC_L_IN: C175.1, J102.1 (In), R171.1, R183.1
PRI_REC_R_IN: C176.1, J104.1 (In), R172.1, R184.1
PRI_RET_L: C171.1, P101.2, R179.1, U103.1
PRI_RET_R: C172.1, P101.5, R180.1, U103.7
PRI_SEND_L: P101.1, R106.1, R107.1
PRI_SEND_R: P101.4, R126.1, R127.1
SEC_DRV_L: R151.1, R155.1, U102.1
SEC_DRV_R: R152.1, R156.1, U102.7
SEC_OUT_L: J105.1 (In), R155.2
SEC_OUT_R: J107.1 (In), R156.2
SEC_REC_L_IN: C177.1, J106.1 (In), R173.1, R185.1
SEC_REC_R_IN: C178.1, J108.1 (In), R174.1, R186.1
SEC_RET_L: C173.1, P102.2, R181.1, U104.1
SEC_RET_R: C174.1, P102.5, R182.1, U104.7
SEC_SEND_L: P102.1, R157.1
SEC_SEND_R: P102.4, R158.1
TANK_SHIELD_RET: C191.1, J102.2 (Ext), J104.2 (Ext), J106.2 (Ext), J108.2 (Ext), R205.1, R206.2
TANK_SHIELD_SEND: J101.2 (Ext), J103.2 (Ext), J105.2 (Ext), J107.2 (Ext), R206.1

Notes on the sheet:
PRIMARY SEND LEFT (4AB1C1B, 8R)
PRIMARY SEND RIGHT (4AB1C1B, 8R)
SECONDARY SENDS (9EB2C1B L / 9EB3C1B R, 800R)
RECOVERY PRIMARY L
RECOVERY PRIMARY R
RECOVERY SECONDARY L
RECOVERY SECONDARY R
POWER ENTRY + DECOUPLING
BOARD HARNESS
TANK SHIELD STRATEGY

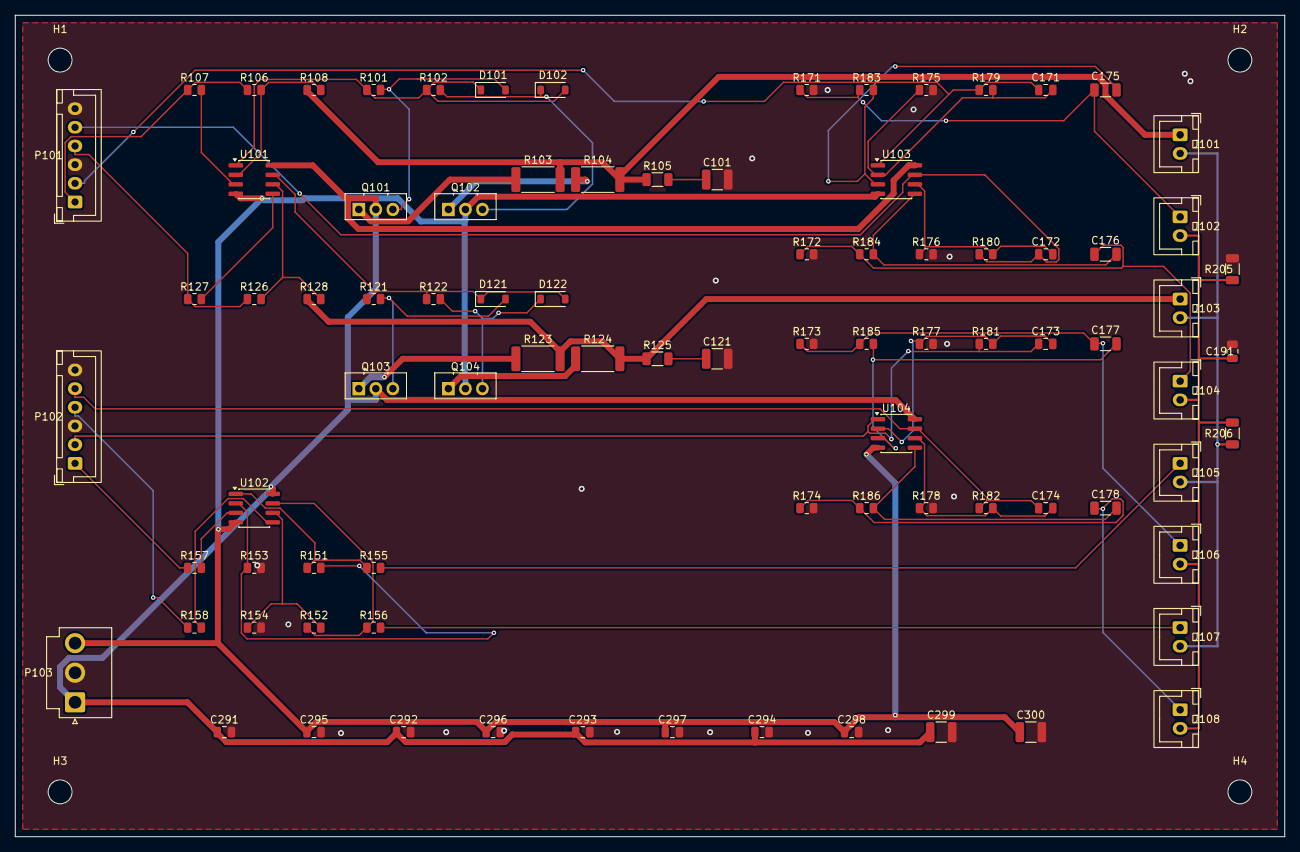
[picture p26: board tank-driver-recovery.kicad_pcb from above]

Board: 2 copper layers, 170.0 x 110.0 mm, 90 parts (0 on the bottom side), 51 nets.

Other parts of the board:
H1, H2, H3, H4: M3; MountingHole_3.2mm_M3

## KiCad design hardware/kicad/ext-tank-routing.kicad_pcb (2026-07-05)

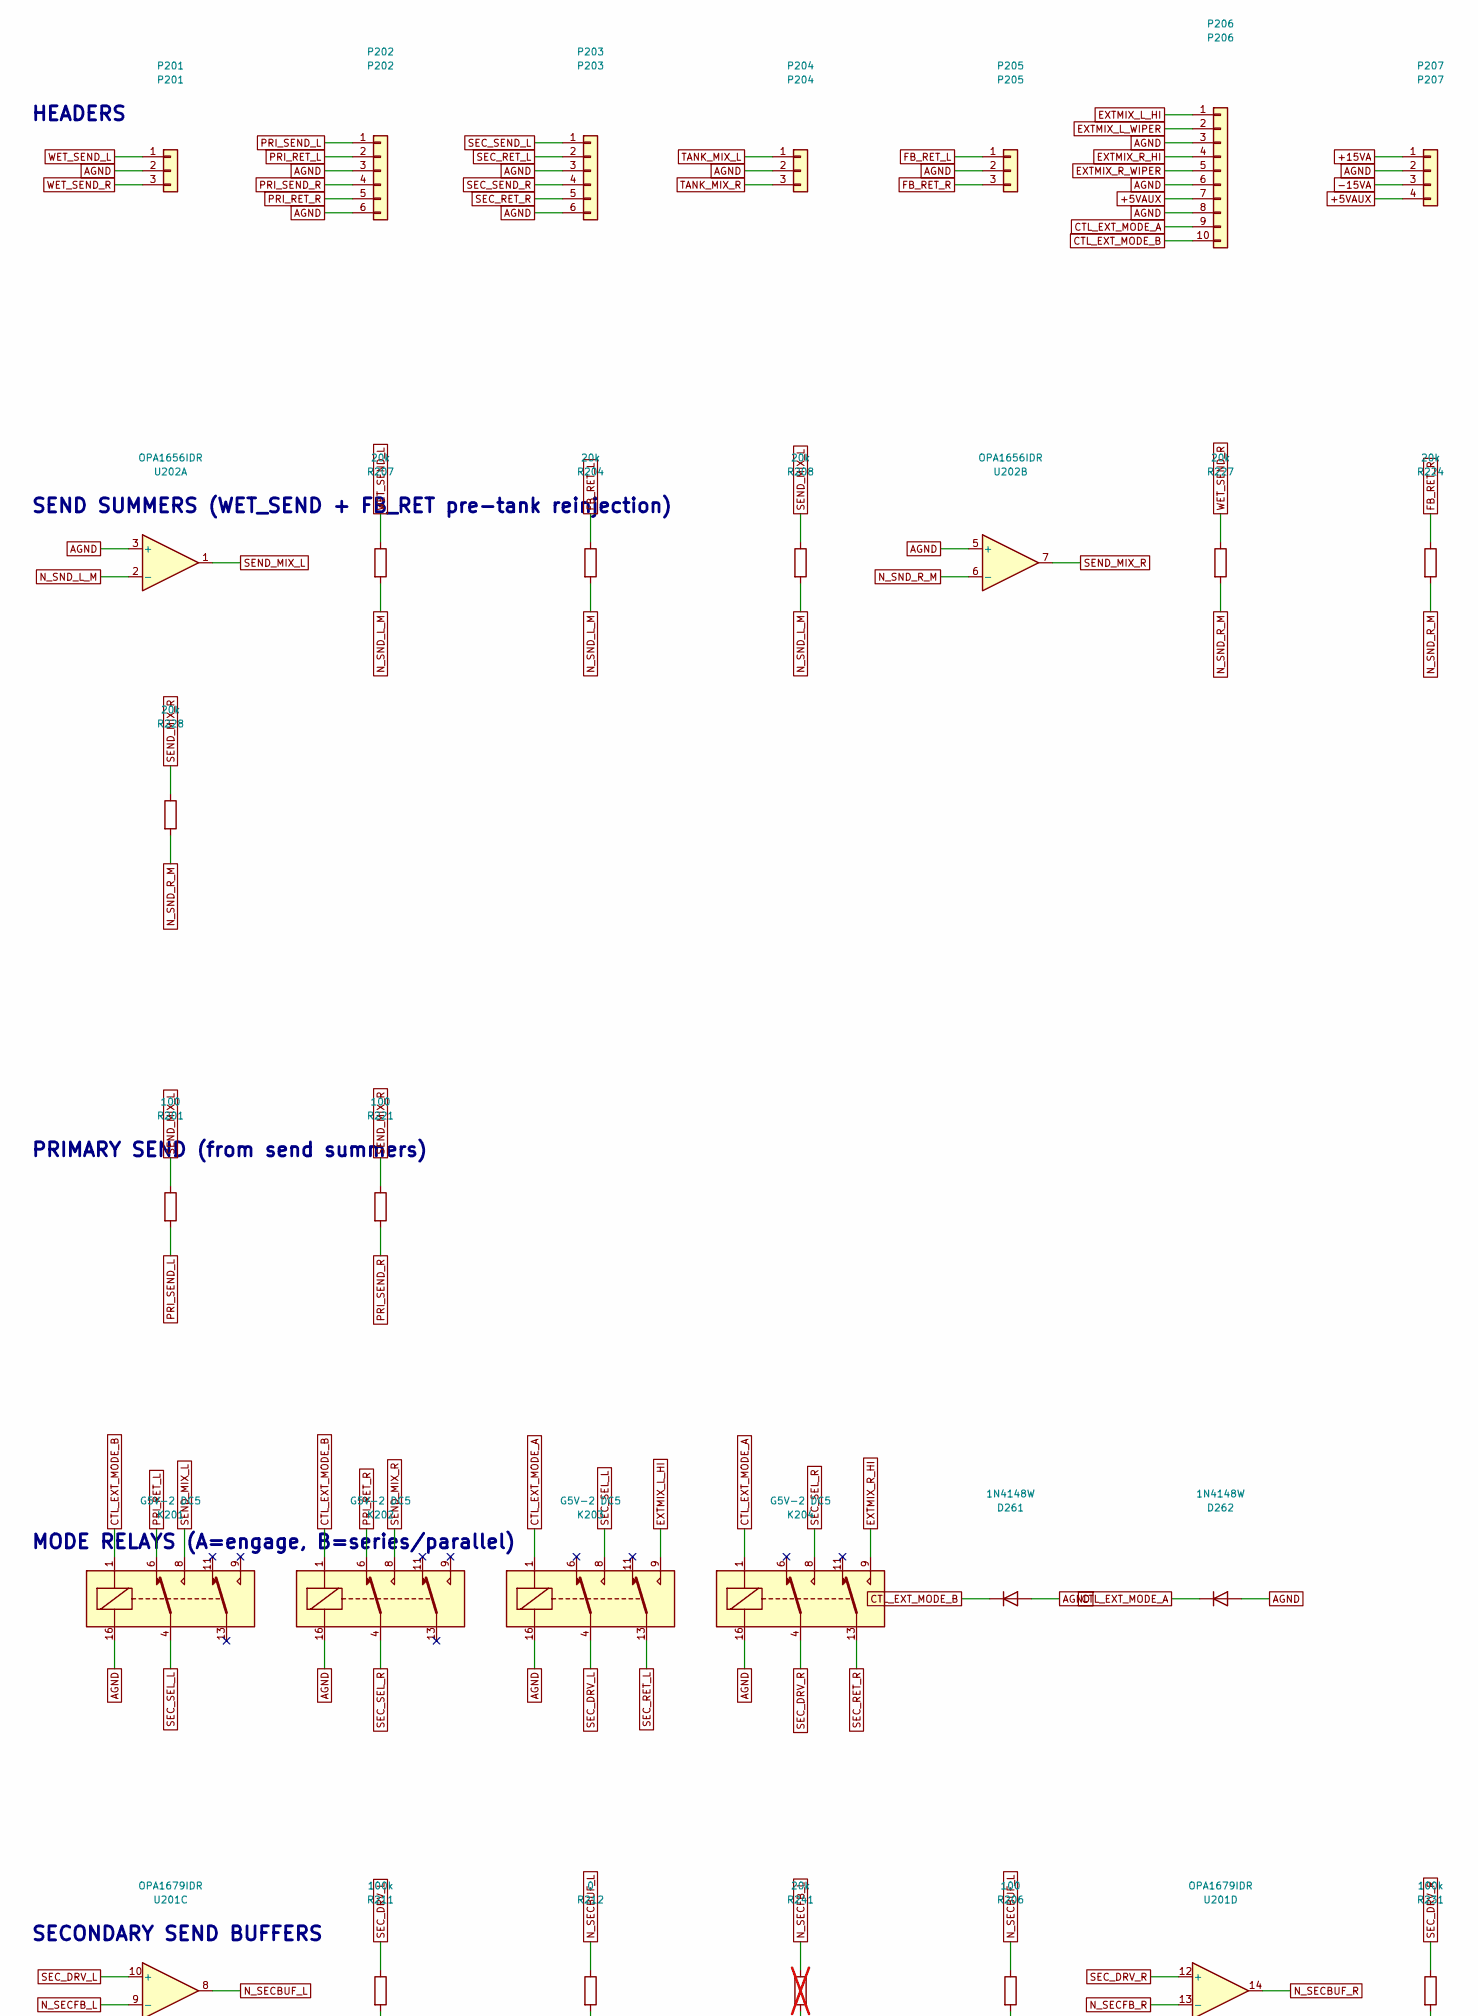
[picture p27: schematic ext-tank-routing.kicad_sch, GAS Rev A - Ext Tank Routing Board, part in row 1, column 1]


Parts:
C291, C292, C295, C296, C297: 100n; C_0805_2012Metric
C293, C294: 22u; C_1210_3225Metric
D261, D262: 1N4148W; D_SOD-123
K201, K202, K203, K204: G5V-2 DC5; Relay_DPDT_Omron_G5V-2
P201: P201; JST_XH_B3B-XH-A_1x03_P2.50mm_Vertical
P202: P202; JST_XH_B6B-XH-A_1x06_P2.50mm_Vertical
P203: P203; JST_XH_B6B-XH-A_1x06_P2.50mm_Vertical
P204: P204; JST_XH_B3B-XH-A_1x03_P2.50mm_Vertical
P205: P205; JST_XH_B3B-XH-A_1x03_P2.50mm_Vertical
P206: P206; JST_XH_B10B-XH-A_1x10_P2.50mm_Vertical
P207: P207; JST_VH_B4P-VH_1x04_P3.96mm_Vertical
R201, R205, R206, R221, R225, R226: 100; R_0805_2012Metric
R202, R203, R204, R207, R208, R209, R222, R223, R224, R227, R228, R229: 20k; R_0805_2012Metric
R211, R231: 100k; R_0805_2012Metric
R212, R232: 0; R_0805_2012Metric
R241, R251: 20k; R_0805_2012Metric; not fitted
U201: OPA1679IDR; SOIC-14_3.9x8.7mm_P1.27mm
U202: OPA1656IDR; SOIC-8_3.9x4.9mm_P1.27mm

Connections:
+5VAUX: C295.1, P206.7, P207.4
+15VA: C291.1, C293.1, C296.1, P207.1, U201.4 (V+), U202.8 (V+)
-15VA: C292.1, C294.1, C297.1, P207.3, U201.11 (V-), U202.4 (V-)
AGND: C291.2, C292.2, C293.2, C294.2, C295.2, C296.2, C297.2, D261.2 (A), D262.2 (A), K201.16, K202.16, K203.16, K204.16, P201.2, P202.3, P202.6, P203.3, P203.6, P204.2, P205.2, P206.3, P206.6, P206.8, P207.2, R211.2, R231.2, R241.2, R251.2, U201.3 (+), U201.5 (+), U202.3 (+), U202.5 (+)
CTL_EXT_MODE_A: D262.1 (K), K203.1, K204.1, P206.9
CTL_EXT_MODE_B: D261.1 (K), K201.1, K202.1, P206.10
EXTMIX_L_HI: K203.9, P206.1
EXTMIX_L_WIPER: P206.2, R203.1
EXTMIX_R_HI: K204.9, P206.4
EXTMIX_R_WIPER: P206.5, R223.1
FB_RET_L: P205.1, R204.1
FB_RET_R: P205.3, R224.1
N_SECBUF_L: R206.1, R212.1, U201.8
N_SECBUF_R: R226.1, R232.1, U201.14
N_SECFB_L: R212.2, R241.1, U201.9 (-)
N_SECFB_R: R232.2, R251.1, U201.13 (-)
N_SND_L_M: R204.2, R207.2, R208.2, U202.2 (-)
N_SND_R_M: R224.2, R227.2, R228.2, U202.6 (-)
N_SUM_L_M: R202.2, R203.2, R209.2, U201.2 (-)
N_SUM_R_M: R222.2, R223.2, R229.2, U201.6 (-)
N_TMIX_L: R205.1, R209.1, U201.1
N_TMIX_R: R225.1, R229.1, U201.7
PRI_RET_L: K201.6, P202.2, R202.1
PRI_RET_R: K202.6, P202.5, R222.1
PRI_SEND_L: P202.1, R201.2
PRI_SEND_R: P202.4, R221.2
SEC_DRV_L: K203.4, R211.1, U201.10 (+)
SEC_DRV_R: K204.4, R231.1, U201.12 (+)
SEC_RET_L: K203.13, P203.2
SEC_RET_R: K204.13, P203.5
SEC_SEL_L: K201.4, K203.8
SEC_SEL_R: K202.4, K204.8
SEC_SEND_L: P203.1, R206.2
SEC_SEND_R: P203.4, R226.2
SEND_MIX_L: K201.8, R201.1, R208.1, U202.1
SEND_MIX_R: K202.8, R221.1, R228.1, U202.7
TANK_MIX_L: P204.1, R205.2
TANK_MIX_R: P204.3, R225.2
WET_SEND_L: P201.1, R207.1
WET_SEND_R: P201.3, R227.1

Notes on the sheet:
HEADERS
SEND SUMMERS (WET_SEND + FB_RET pre-tank reinjection)
PRIMARY SEND (from send summers)
MODE RELAYS (A=engage, B=series/parallel)
SECONDARY SEND BUFFERS
FINAL SUMMERS
POWER + DECOUPLING

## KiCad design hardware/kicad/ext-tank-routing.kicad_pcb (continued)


Board: 2 copper layers, 120.0 x 80.0 mm, 50 parts (0 on the bottom side), 40 nets.

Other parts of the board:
H1, H2, H3, H4: M3; MountingHole_3.2mm_M3

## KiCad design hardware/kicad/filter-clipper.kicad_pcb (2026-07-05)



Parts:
C401, C421: 47n; C_1210_3225Metric
C403, C406, C407, C423, C426, C427: 10n; C_1210_3225Metric
C405, C425: 47p; C_0805_2012Metric; not fitted
C591, C592, C593, C594: 100n; C_0805_2012Metric
C595, C596: 22u; C_1210_3225Metric
D401, D402, D403, D404, D421, D422: 1N4148W; D_SOD-123
D405, D406, D407, D408: LED red; LED_0805_2012Metric
D409, D410, D411, D412: 1N5819HW; D_SOD-123
K401, K402, K403: G5V-2 DC5; Relay_DPDT_Omron_G5V-2
P401: JXF-FILT B3B-XH-A; JST_XH_B3B-XH-A_1x03_P2.50mm_Vertical
P402: JFILT-WET B3B-XH-A; JST_XH_B3B-XH-A_1x03_P2.50mm_Vertical
P403: JFILT-CTL-A B12B-XH-A; JST_XH_B12B-XH-A_1x12_P2.50mm_Vertical
P404: JFILT-PWR B3P-VH-B; JST_VH_B3P-VH_1x03_P3.96mm_Vertical
P405: JFILT-CTL-B B12B-XH-A; JST_XH_B12B-XH-A_1x12_P2.50mm_Vertical
R401, R406, R421, R426: 1k; R_0805_2012Metric
R402, R407, R422, R427: 47k; R_0805_2012Metric
R403, R423: 39k; R_0805_2012Metric
R404, R424: 10k; R_0805_2012Metric
R405, R425: 4.7k; R_0805_2012Metric
R408, R428, R432: 100; R_0805_2012Metric
U401, U402: OPA1679IDR; SOIC-14_3.9x8.7mm_P1.27mm

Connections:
+5VAUX: P405.9
+15VA: C591.1, C593.1, C595.1, P404.1, U401.4 (V+), U402.4 (V+)
-15VA: C592.1, C594.1, C596.1, P404.3, U401.11 (V-), U402.11 (V-)
AGND: C406.2, C426.2, C591.2, C592.2, C593.2, C594.2, C595.2, C596.2, D421.2 (A), D422.2 (A), K401.16, K402.16, K403.16, P401.2, P402.2, P403.3, P403.6, P403.9, P403.12, P404.2, P405.3, P405.6, P405.12, R401.2, R404.2, R421.2, R424.2, R432.2
CTL_CLIP_MODE_A: D421.1 (K), K401.1, P405.10
CTL_CLIP_MODE_B: D422.1 (K), K402.1, K403.1, P405.11
DRV_HI: D401.1 (K), D402.2 (A), D403.1 (K), D404.2 (A), D405.1 (K), D406.2 (A), D407.1 (K), D408.2 (A), D409.1 (K), D410.2 (A), D411.1 (K), D412.2 (A), P403.1
DRV_WIPER: P403.2, R432.1
FILTCLIP_OUT_L: P402.1, R408.2
FILTCLIP_OUT_R: P402.3, R428.2
HPF_F_L_HI: C401.2, C403.2, P403.4, U401.3 (+)
HPF_F_L_WIPER: P403.5, R401.1
HPF_F_R_HI: C421.2, C423.2, P403.7, U401.5 (+)
HPF_F_R_WIPER: P403.8, R421.1
HPF_Q_L_WIPER: C403.1, P403.10, R402.2
HPF_Q_R_WIPER: C423.1, P403.11, R422.2
LPF_F_L_HI: P405.1, R406.2
LPF_F_L_WIPER: C406.1, C407.2, P405.2, U402.3 (+)
LPF_F_R_HI: P405.4, R426.2
LPF_F_R_WIPER: C426.1, C427.2, P405.5, U402.5 (+)
LPF_Q_L_WIPER: C407.1, P405.7, R407.2
LPF_Q_R_WIPER: C427.1, P405.8, R427.2
N_BUF_OUT_L: R408.1, U402.8, U402.9 (-)
N_BUF_OUT_R: R428.1, U402.13 (-), U402.14
N_CLIP_L: K401.4, R405.2, R406.1
N_CLIP_R: K401.13, R425.2, R426.1
N_DRV_M_L: C405.2, R403.2, R404.1, U401.9 (-)
N_DRV_M_R: C425.2, R423.2, R424.1, U401.13 (-)
N_DRV_OUT_L: C405.1, R403.1, R405.1, U401.8
N_DRV_OUT_R: C425.1, R423.1, R425.1, U401.14
N_GE_L: D409.2 (A), D410.1 (K), K402.9
N_GE_R: D411.2 (A), D412.1 (K), K403.9
N_HPF_OUT_L: R402.1, U401.1, U401.2 (-), U401.10 (+)
N_HPF_OUT_R: R422.1, U401.6 (-), U401.7, U401.12 (+)
N_KA_L_NC: K401.6, K402.4
N_KA_L_NO: K401.8, K402.13
N_KA_R_NC: K401.11, K403.4
N_KA_R_NO: K401.9, K403.13
N_LED_L: D405.2 (A), D406.1 (K), K402.11
N_LED_R: D407.2 (A), D408.1 (K), K403.11
N_LPF_OUT_L: R407.1, U402.1, U402.2 (-), U402.10 (+)
N_LPF_OUT_R: R427.1, U402.6 (-), U402.7, U402.12 (+)
N_SI_L: D401.2 (A), D402.1 (K), K402.8
N_SI_R: D403.2 (A), D404.1 (K), K403.8
XFADE_OUT_L: C401.1, P401.1
XFADE_OUT_R: C421.1, P401.3

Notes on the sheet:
HEADERS
LEFT CHANNEL
RIGHT CHANNEL
CLIP MODE DECODE (00 clean, 01 Si, 10 LED, 11 Schottky)
POWER + DECOUPLING


Board: 2 copper layers, 140.0 x 90.0 mm, 61 parts (0 on the bottom side), 45 nets.

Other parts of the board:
H1, H2, H3, H4: M3; MountingHole_3.2mm_M3

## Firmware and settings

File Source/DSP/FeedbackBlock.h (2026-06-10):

#pragma once

#include <JuceHeader.h>

class FeedbackBlock
{
public:
    void prepare (double sampleRate, int maximumBlockSize)
    {
        feedbackAmount.reset (sampleRate, 0.05);
        feedbackAmount.setCurrentAndTargetValue (0.0f);
        lastLeftSample = 0.0f;
        lastRightSample = 0.0f;

        juce::dsp::ProcessSpec monoSpec;
        monoSpec.sampleRate = sampleRate;
        monoSpec.maximumBlockSize = static_cast<juce::uint32> (juce::jmax (1, maximumBlockSize));
        monoSpec.numChannels = 1;

        feedbackPredelayLeft.prepare (monoSpec);
        feedbackPredelayRight.prepare (monoSpec);
    }

    void reset()
    {
        feedbackAmount.setCurrentAndTargetValue (feedbackAmount.getTargetValue());
        lastLeftSample = 0.0f;
        lastRightSample = 0.0f;
        feedbackPredelayLeft.reset();
        feedbackPredelayRight.reset();
    }

    void setFeedbackAmount (float normalizedAmount)
    {
        feedbackAmount.setTargetValue (juce::jlimit (0.0f, 1.0f, normalizedAmount));
    }

    void setFeedbackPhaseInverted (bool shouldInvert)
    {
        feedbackPhase = shouldInvert ? -1.0f : 1.0f;
    }

    void process (const juce::AudioBuffer<float>& inputWet,
                  juce::AudioBuffer<float>& outputWet,
                  juce::AudioBuffer<float>& feedbackReturn,
                  const float* predelaySamplesPerSample,
                  int numSamples)
    {
        outputWet.copyFrom (0, 0, inputWet, 0, 0, numSamples);
        outputWet.copyFrom (1, 0, inputWet, 1, 0, numSamples);

        auto* feedbackLeft = feedbackReturn.getWritePointer (0);
        auto* feedbackRight = feedbackReturn.getWritePointer (1);
        const auto* wetLeft = inputWet.getReadPointer (0);
        const auto* wetRight = inputWet.getReadPointer (1);

        auto delayedLeft = lastLeftSample;
        auto delayedRight = lastRightSample;

        for (int sample = 0; sample < numSamples; ++sample)
        {
            feedbackPredelayLeft.pushSample (0, delayedLeft);
            feedbackPredelayRight.pushSample (0, delayedRight);

            const auto amount = feedbackAmount.getNextValue();
            const auto predelaySamples = predelaySamplesPerSample != nullptr ? juce::jmax (0.0f, predelaySamplesPerSample[sample]) : 0.0f;
            feedbackLeft[sample] = feedbackPredelayLeft.popSample (0, predelaySamples) * amount * feedbackPhase;
            feedbackRight[sample] = feedbackPredelayRight.popSample (0, predelaySamples) * amount * feedbackPhase;

            delayedLeft = wetLeft[sample];
            delayedRight = wetRight[sample];
        }

        lastLeftSample = delayedLeft;
        lastRightSample = delayedRight;
    }

private:
    juce::SmoothedValue<float, juce::ValueSmoothingTypes::Linear> feedbackAmount;
    juce::dsp::DelayLine<float, juce::dsp::DelayLineInterpolationTypes::Linear> feedbackPredelayLeft { 16384 };
    juce::dsp::DelayLine<float, juce::dsp::DelayLineInterpolationTypes::Linear> feedbackPredelayRight { 16384 };
    float lastLeftSample = 0.0f;
    float lastRightSample = 0.0f;
    float feedbackPhase = 1.0f;
};

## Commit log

2026-06-23 UI refactor: contemporary font, art under title, mono LR swap, inverted buttons, new layout
2026-06-23 Major UI overhaul: Art Nouveau, Input mode, aligned layout, combobox-style buttons
2026-07-02 WIP checkpoint: Codex rev-A capture state before clean rebuild (ERC 740, PCB scaffolds DRC-clean)
    [GAS-Hardware.kicad_sch, crossfade-feedback-wet.kicad_pcb, crossfade-feedback-wet.kicad_sch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]
2026-07-02 Rebuild tank-driver-recovery: ERC-clean schematic + working ngspice testbench + netlist-synced placed PCB (DRC errors 0, routing pending)
    [tank-driver-recovery-sim.kicad_sch, tank-driver-recovery.kicad_pcb, tank-driver-recovery.kicad_sch]
2026-07-02 Board 1 routed: 0 DRC errors, 0 unconnected; Freerouting pipeline; fab outputs (gerbers, drill, pos, BOM)
    [tank-driver-recovery-B_Courtyard.gbr, tank-driver-recovery-B_Cu.gbl, tank-driver-recovery-B_Fab.gbr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]
2026-07-02 Board 2 power-backplane: ERC 0, ripple-filter sim -50dB @350kHz verified, routed PCB DRC 0/0, fab outputs; URB->URA2415YMD-10WR3 part correction (URB is single-output)
    [power-backplane-B_Courtyard.gbr, power-backplane-B_Cu.gbl, power-backplane-B_Fab.gbr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]
2026-07-02 Board 3 crossfade-feedback-wet: ERC 0, sim verified (crossfade/wet/feedback math exact), routed DRC 0/0, fab outputs; added K301 G5V-2 phase-select relay missing from old BOM
    [crossfade-feedback-wet-B_Courtyard.gbr, crossfade-feedback-wet-B_Cu.gbl, crossfade-feedback-wet-B_Fab.gbr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]
2026-07-02 Board 4 filter-clipper: ERC 0, sim verified (HPF/drive 4.9x/clip modes/LPF), routed DRC 0/0, fab outputs; clip decode = 3x G5V-2 relay tree per frozen truth table
    [filter-clipper-B_Courtyard.gbr, filter-clipper-B_Cu.gbl, filter-clipper-B_Fab.gbr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]
2026-07-02 Board 5 ext-tank-routing: ERC 0, sim verified (Series/Off relay modes, summers exact), routed DRC 0/0, fab outputs; relays standardized to G5V-2 DC5
    [ext-tank-routing-B_Courtyard.gbr, ext-tank-routing-B_Cu.gbl, ext-tank-routing-B_Fab.gbr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]
2026-07-02 Board 6 io-board complete (ERC 0, sim verified, DRC 0/0 with ground grid stitching); all six boards READY TO ORDER; fab packet with gerber zips, BOMs, pos files, ORDER-PACKET.md; readiness report reg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
    [io-board-B_Courtyard.gbr, io-board-B_Cu.gbl, io-board-B_Fab.gbr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]
2026-07-02 Schematic review (kicad-schematic-review skill): F1 R-78E moved to +15VRAW, F2 mono-float bleed R25; both boards re-routed/verified; datasheet cache, per-instance reviews, schematic_review.md
    [io-board-B_Courtyard.gbr, io-board-B_Cu.gbl, io-board-B_Fab.gbr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]
2026-07-04 ext-tank-routing: move feedback reinjection pre-tank (U202 send summers)
    FB_RET_L/R now sum with WET_SEND_L/R at new OPA1656 send summers (U202)
    upstream of PRI_SEND and the parallel-mode pickoff, so feedback re-passes
    through the spring tanks. Removed FB_RET from the U201A/B TANK_MIX output
    summers. Matches the JUCE sim, where feedbackReturnBuffer adds into
    wetInputBaseBuffer before predelay+convolution (= the tanks).
    - gen_ext.py: U202 stage, R207/R208/R227/R228 20k, C296/C297 100n,
    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
    [ext-tank-routing-B_Courtyard.gbr, ext-tank-routing-B_Cu.gbl, ext-tank-routing-B_Fab.gbr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]
2026-07-04 Endcap: finalize control positions and move to 10 in nominal diameter
    - DC jack to (95,-18.35) after clash history (88,-48)->(88,-12)->(95,-18.35)
    - Toggles SW701/SW702 to (+/-63.65, 61.3), fixes 12 mm edge-rule violation
    - Wet/dry and HPF cutoff raised 1/4 in to Y=-45.65
    - Diameter: 10 in nominal preferred (off-the-shelf pipe/cap size); 9 in
    still passes all spacing rules but is rarely stocked
    - All 18 panel items verified against spacing rules on 10 in and 9 in faces
    - Endcap blank BOM line moved to 10 in, flagged for requote
    [rev-a-endcap-hole-table.csv, rev-a-panel-and-mechanical-reference-bom.csv, rev-a-procurement-snapshot.csv]
2026-07-04 Pre-order fixes: io-board AGND island, BOM DNP columns, clip-5V harness decision, fresh gate
    - io-board: remove orphan AGND via (117.102,96.479), zones to island-removal=always, refill; DRC 0/0; gerbers+drill+pos re-exported, zip rebuilt (only F_Cu/B_Cu/drl changed vs old packet)
    - Regenerate all six BOM CSVs with DNP column (five lacked it); verified ref-by-ref against schematics
    - Clip-mode +5V: rev-A panel jumper documented (H33, connector schedule, ORDER-PACKET); rev-B 4-pin P404/P504 recorded as open issue #9
    - Fresh ERC+DRC gate on all six boards (0 errors, 0 unconnected); stale reports and abandoned GAS-Hardware top level archived
    - Add pre-order review report, review_outputs findings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
    [GAS-Hardware.kicad_sch, crossfade-feedback-wet-bom.csv, filter-clipper-bom.csv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]
2026-07-05 Order prep: HQDFM triage of all six boards, assembly BOMs, fab output fixes
    - assembly-ready BOMs (bom-assembly.csv/.xlsx) merged from fab + priced BOMs with MPN/Manufacturer/Qty/DNP; J1-J4 corrected to board-mounted JST headers; xlsx centroid files for NextPCB upload
    - HQDFM reports triaged for all six boards: all 'missing THT hole' flags verified false (drill files complete on all six), IPC open/shorts = absent netlist, power NPTH flag = noise
    - filter-clipper: removed 9 duplicate drill hits (stacked AGND vias) from .drl and gerber zip, verified zero dups and full pad/via coverage; kicad_pcb dedupe deferred to rev B
    - via-in-pad relocation evaluated and rejected (no compliant spot within 3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
    [crossfade-feedback-wet-bom-assembly.csv, crossfade-feedback-wet-bom-assembly.xlsx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]
